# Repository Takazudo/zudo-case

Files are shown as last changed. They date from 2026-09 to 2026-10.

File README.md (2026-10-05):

# ZUDO CASE — zudo-doc引継ぎセット

**D1 / 文書スナップショット: 2026-09-24**

3U・60HP、3U＋3U＋1U・40HP、3U＋3U＋1U・60HPの金属ケースを、現物確認・見積・発注へ進めるためのドキュメントです。本文は日本語のMDX、サイト設定はzudo-doc用です。

このD1は**資料整理の版**です。ケースCADの新しい版や、製造承認ではありません。

## 現行7U40候補

[R9-FITFIX-01](src/content/docs/design/r9-fitfix-01.mdx)を追加。ガードと蓋座面の修正候補で、固定環境の生成・検査記録は `engineering/r9-fitfix-01/verification/`。旧R9は履歴として保存し、現物嵌合・接着・運搬と製造承認は未完了。

## 家庭印刷用8mmスペーサー

フレームとケース側板の間に入れる[8mmスペーサーのSTL・編集用ソース・印刷手順](engineering/home-print-spacer-01/README.md)を追加。外径10mm／穴径5.5mmはR6由来の仮寸法です。まず1個で現物確認し、3U60は4個、7U40/7U60は各10個を印刷します。

## まず起動する

Node.js 22以上とpnpmを用意してください。このスナップショットは公式scaffolderで初期化済みで、`package.json`と`pnpm-lock.yaml`を含みます。新しいチェックアウトでは、依存をロックファイルどおりに入れてから使います。動作確認した環境はNode.js 24.13.1、pnpm 10.30.3です。

```sh
# リポジトリのルートで実行
pnpm install --frozen-lockfile
pnpm check:docs
pnpm check:assets
pnpm test:setup
pnpm build
pnpm dev
```

このセットの初期化には公式`create-zudo-doc@5.27.0`を使いました。`scripts/setup.mjs`はscaffoldをまだ取り込んでいない文書のみのスナップショット向けです。この初期化済みチェックアウトでは再実行せず、ロックファイルから依存を復元してください。Git初期化、デプロイ、注文は自動実行しません。

2026-09-24の初回ビルドでは44ページを生成し、41件の文書ルートと検索項目、47件の公開資産を確認しました。現在は画像・図15件をzudo-docのAsset Viewerに移し、`/files/`の一覧と各閲覧ページを追加して60ページを生成します。同日のChrome 146.0.7680.153で、desktop 1440×900とnarrow 390×844の実表示も確認しました。41ルートと8カテゴリを両幅で開き、narrowでの横はみ出しはなく、検索・テーマ・画像・R8/R6プレビューの主要操作も動作しました。画面ごとの記録、ダウンロード件数、スクリーンショットは[検証記録](project/browser-validation.md)にまとめています。物理的な嵌合・強度・運搬試験はこのブラウザー確認に含みません。`pnpm dev`が表示するURLを開き、「現在地と最初に読むページ」から読んでください。

### ローカルと本番のプレビュー確認

`pnpm dev`で開いた文書のR8/R6プレビューと参照・旧版ZIPのリンクは、既定では同じチェックアウトの`public/previews/`と`public/downloads/`を参照します。R8ページの埋め込み枠の下にある「表示元: ローカル (public/)」を確認してください。`public/previews/r8-simple-lid.html`を変更すると、開き直したローカル文書からその変更を確認できます。

別のプレビュー配信元を試すときは、起動時にHTTP(S)のoriginだけを指定します。パスは付けません。

```sh
ZUDO_CASE_PREVIEW_ORIGIN=http://localhost:8787 pnpm dev
```

`dev`・`check`・`build` は同じチェックアウトで併用できます。起動ごとに `.cache/site-runs/run-*` の独立した設定と内部キャッシュを使うため、別コマンドを実行しても稼働中のdevの表示元は変わりません。異なるoverrideを指定したdevも、`pnpm dev --port 3001` のように別ポートで起動できます。記事・コード・設定は実行ごとのコピーを使い、devでは元の編集・追加・削除を約250ms間隔で反映します。`public/` は元のチェックアウトを直接参照します。build/checkは起動時のコピーを使います。

内部キャッシュは終了時に削除します。強制終了などで残った実行フォルダーは、対応するプロセスが停止していることを確認してから削除してください。公開ビルドは従来どおりチェックアウトの `dist/` に出力し、`pnpm preview` もその出力を配信します。同じ出力先への複数buildの同時実行は避けてください。

この場合は枠下に指定先のホストが表示されます。本番ビルドの既定値は`https://zudo-case-preview.zudolab.dev`で、文書とプレビューの２ホスト配信を維持します。本番ビルド前は上記環境変数を外してください。`pnpm build`後の`pnpm check:built-preview-links`で、生成した文書HTMLに本番ホストのリンクがあり、ローカルURLが混入していないことを確認できます。

### 初期化履歴と確認範囲

元の文書のみのスナップショットではnpmレジストリの名前解決が`EAI_AGAIN`となり、その時点では初期化・ビルドを確認できませんでした。その後、2026-09-24に公式scaffolderの実行とロックファイルに基づく依存インストールを完了し、上記の実ビルドを確認しています。各画面のブラウザー確認結果・表示幅・残件は検証記録に記載します。

初期化前の文書のみのスナップショットで、取り込み内容だけを確認する場合:

```sh
node scripts/setup.mjs --dry-run
```

公式CLIを別フォルダーへ実行した場合は、次の形でも土台だけ取り込めます。

```sh
node scripts/setup.mjs --from /absolute/path/to/fresh-official-scaffold
```

既に運用中のサイトへ統合する場合は、setupを実行せず、記事・資産・設定を個別にマージしてください。補助スクリプトはファイル衝突があると上書きせず停止します。CLIの版は`ZUDO_DOC_CLI_VERSION`環境変数で指定でき、デフォルトは`5.27.0`です。生成結果は`.handoff/`に記録します。

## 入っているもの

| 大分類 | 内容 |
|---|---|
| 概要 | 現在地、採用仕様、未確認事項、用語 |
| ３機種 | 寸法、レール・金具・ガード数量、比較表 |
| 設計 | レール積層、8mmスペーサー、長穴、締結、ガード、載せ蓋とバンド |
| 製作 | BOM、見積依頼条件、印刷用データの扱い、過去価格の根拠 |
| 検証 | 嵌合・組立・持ち運びの確認と、発注前ゲート |
| 資料 | R8とR6の3Dプレビュー、CAD、STL、STEP、DXF、元データ |
| 判断履歴 | 5→8mm、ガード薄肉化、蓋のロック不採用、バンド採用 |
| 引継ぎ | セットアップ、次工程、更新手順 |

**41文書ページ、8カテゴリ**です。カテゴリ一覧は`project/navigation.json`にあります。画像・図は`/files/`の一覧と閲覧ページにも表示されます。既存のプレビューは、サイトを起動しなくても`public/previews/r8-simple-lid.html`をブラウザーで直接開けます。

## 最初に確認すべき状態

| 対象 | 現在の扱い |
|---|---|
| 採用方式 | 10BOX式の載せ蓋＋運搬時だけ外周バンド２本。蓋と本体のロックなし |
| 本体 | R6の名目CADが修正起点。３機種・8mmスペーサー・薄型ガード |
| ブラケット用長穴 | 意図は採用済み。R6の製作図にはまだ丸穴が残る |
| 蓋 | R8の表示用形状まで。新しい製作用STL/STEP/DXFは未生成 |
| R7のM3ロック蓋 | 不採用の参考資料。最終仕様として注文しない |
| 現在の総原価 | 未確定。旧R3ガード2,264円を現行全体の見積に流用しない |
| 製作承認ファイル | なし。`engineering/release/`は注意書きだけ |

ガードの固定方法・嵌合、公差、ノブ上方の隙間、バンドによる天板のたわみ等も確認待ちです。ここを見失わないため、`project/open-issues.json`と発注前ゲートを用意しました。

## フォルダー

```text
zudo-case-doc/
├── README.md / AGENTS.md
├── zfb.config.ts                 # この文書サイトの設定
├── setup.preset.json             # 公式初期化CLIへ渡す設定
├── src/content/docs/             # 41ページのMDX
├── public/
│   ├── assets/                  # Asset Viewerの画像・図・見積画面
│   ├── previews/                # R8/R6の単一HTML
│   ├── evidence/                # 旧README、計算結果
│   └── downloads/
│       ├── reference/           # 未承認のR6参照データ
│       └── archive/             # 不採用のR7・ロック比較
├── engineering/
│   ├── r6-body/                 # 元ソース・CAD・STL・PCB
│   ├── r8-preview/              # 載せ蓋の表示用ソース
│   └── release/                 # 承認後にのみ格納
├── project/                     # 仕様・根拠・見積・課題・ハッシュ
├── scripts/                     # 初期化、整合チェック、表の再生成
└── tests/                       # 初期化の安全な取り込みを検査
```

元のR6/R8ソースと旧アーカイブは保全しています。過去の生成コードやREADMEにある絶対パス・前提は作成当時のものです。そのまま全スクリプトを一括実行せず、`src/content/docs/resources/engineering.mdx`を読んでからローカル環境に合わせてください。

## 更新と静的チェック

次は依存を入れる前でもNodeだけで実行できます。

```sh
node scripts/check-docs.mjs
node scripts/verify-assets.mjs
node --test tests/setup.test.mjs
```

- `check-docs`: メタデータ、ローカルリンク先、機種寸法・数量・見積加算の整合を検査します。MDXコンパイラではありません。
- `verify-assets`: 同梱資産のSHA-256を、引継ぎ時の台帳に照合します。CADの強度・干渉・公差を保証するものではありません。意図的に変更した資産は差分になります。
- `test:setup`: 模擬scaffoldを使い、既存記事保護・衝突停止・復旧を確認します。公式CLIの実行確認ではありません。

機種別の表とBOMは台帳から再生成します。

```sh
# project/current-spec.jsonを根拠とともに更新した後:
node scripts/sync-reference-tables.mjs
node scripts/check-docs.mjs
```

自動生成の対象は３機種ページ、機種比較、BOMの５ページ。**台帳はCADジェネレーターの入力ではありません**。ここだけ直して製作データを更新済みにしないでください。

## 根拠と公開範囲

ユーザーが測定した寸法、採用方針、元STL/PCB、過去のモデル値、見積画面、助手の概算を分けました。会話由来の採用判断は`project/source-notes/user-decisions.md`、出典台帳は`project/sources.json`です。今回、サプライヤーの価格を取り直してはいません。

Cloudflare Workers Static Assetsへの公開設定は２つのホストに分けています。`zudo-case.zudolab.dev`は文書、Asset Viewerの画像・図、テキスト/JSON根拠を配信し、`zudo-case-preview.zudolab.dev`は単体HTMLプレビューと参照/旧版ZIPを配信します。`pnpm build`の後に`pnpm prepare:worker-assets`で配信フォルダーを分離し、25MiBを超える２ファイルは小片に分けてプレビューWorkerが元のURLでストリーム配信します。元ファイルのSHA-256は維持します。GitHub Actionsは`main`へのpushで２つのWorkerを順にデプロイし、`CLOUDFLARE_ACCOUNT_ID`と`CLOUDFLARE_API_TOKEN`をデプロイ手順だけに渡します。**noindexはアクセス制限ではありません。** 見積画像と旧版ZIPもそれぞれのホストで閲覧できる設定です。初期設定はルートパス配信です。

### 公開配信の検証範囲

ローカルのモックテスト（`node --test tests/verify-deployed-assets.test.mjs tests/worker-assets.test.mjs`）は、短いサンプル資産でHTTP転送、SHA-256照合、Workerのチャンク欠落・切り詰めを確認します。デプロイ後のGitHub Actionsと`pnpm verify:deployed`は、対象２ファイルを全量GETでストリーム読み込みし、チェックアウト内の元ファイルとバイト数・SHA-256を照合します。HEADリクエストは到達確認だけです。どちらもブラウザー/WebGL表示の証拠ではなく、ブラウザー表示の確認は[検証記録](project/browser-validation.md)を参照してください。

第三者ライブラリや元資料の著作権・ライセンス表示は元ファイルの記載に従います。資料整理によって再ライセンスしたものではありません。

## 再実行と復旧

`pnpm prepare:worker-assets`を同じビルド結果に対して再実行すると、世代番号と分割ファイルの完全性を確認してから「already prepared」と表示し、配信ファイルを変更せず終了します。不完全な分割ファイルや片方だけ残った入力が見つかった場合は停止します。`pnpm build`を再実行して入力を作り直し、改めて`pnpm prepare:worker-assets`を実行してください。準備中の失敗でも元の`dist/previews`と`dist/downloads`は移動せず、成功後にだけ配信用のコピーから除きます。`public/`や`engineering/`の元資料には触れません。

公式資料: [Installation](https://zudo-doc.takazudomodular.com/docs/getting-started/installation/) / [CLI](https://zudo-doc.takazudomodular.com/docs/reference/create-zudo-doc/) / [Configuration](https://zudo-doc.takazudomodular.com/docs/guides/configuration/)

## 2WAY experimental family

The independent two-tray study is scoped by `engineering/two-way/AGENTS.md` and `project/two-way/`. F5 is immutable reference; TW-01 is the maintained workbench. It is separate from R9, not a manufacturing release. Its 72/58 mm patch-gap assumptions do not replace the single-tray lid specification.

TW-01の通常生成はオフラインで、既存CADの再生成を必要としません。

```sh
pnpm build:two-way
pnpm check:two-way
pnpm test:two-way
```

[2WAY文書](src/content/docs/two-way/index.mdx)と[ソース・ブラウザー検証手順](engineering/two-way/tw-01/README.md)を参照してください。元F5受入結果とTW-01の描画方式別結果は分けて記録します。

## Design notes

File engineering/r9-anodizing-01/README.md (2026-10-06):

# R9-ANODIZING-01 — 13枚のアルマイト吊り穴追加

Issue [#116](https://github.com/Takazudo/zudo-case/issues/116)。JLCCNC のアルミ試験片13枚に、各1個の専用丸穴を追加した別リビジョン。A5052、板厚1.5 mm、黒アルマイト。PA12の13設計・15個とは別です。元のR9/R9-FITFIXソース、注文ZIP、既存プレビューは変更しません。

`out/r9-anodizing-01-aluminum-13-NOT-APPROVED.zip` は13 STEP＋13 DXF、対応表と検査manifestを収録。STEP/DXFの組は同一品で、26個ではありません。各1枚です。`out/r9-anodizing-01-review.zip` は変更前後SVG13枚、参照STL13個、manifestです。STLはアルミ加工の提出原本ではありません。ZIPの `NOT-APPROVED` はサプライヤーへの製造承認・差替え操作を行っていない意味です。

## Ø4 mm、最小残り幅1.5 mmで保護領域を避ける

サプライヤーから伝達された許容径3.5–5 mmの中で、4 mmを選択。小さいC5でも既存接触面を避ける余地を残し、3.5 mmの下限より0.5 mm大きくしています。残り幅は**穴の端から板端まで**。許容の出発点1 mmに対し、通常2–3 mm、C5で1.5 mmを確保しました。

| ID | 板の平面寸法 mm | 穴中心 U,V mm | 最小残り幅 mm |
|---|---|---|---|
| c1-metal-edge | 40 × 20 | 5, 5 | 3 |
| c2-01-wall | 30 × 31 | 5, 5 | 3 |
| c2-01-plate | 30 × 26.4 | 5, 21.4 | 3 |
| c3-01-bottom / wall | 各32 × 20 | 各4, 16 | 2 |
| c3-02-bottom / wall | 各32 × 20 | 各4, 16 | 2 |
| c3-03-bottom / wall | 各32 × 20 | 各4, 16 | 2 |
| c4-01-floor | 30 × 20 | 5, 15 | 3 |
| c4-01-wall | 30 × 18.5 | 5, 13.5 | 3 |
| c5-01-front | 10.5 × 20 | 7, 7 | 1.5 |
| c5-01-left | 12 × 20 | 8.5, 7 | 1.5 |

U,Vは各DXF左下を原点、右・上が正。元のSTEPが組立座標の部品はそのまま保持。C3 STEPは従来どおり平置き座標です。manifestはSTEP座標と実ケース座標を明確に分離しています。

## 保護した領域とケースとの関係

- C1: 全比較ガードの上端5 mm帯を保持。
- C2: 3種類すべてのフレーム、ガード、支持棚、取付ねじ穴の周辺を避ける。壁の穴は下部、天板は棚から離れた内側の自由端。
- C3: 幅16 mmの金具帯全体と下端5 mmを保護。元の5.5×7.5 / 5.5×8.5 mm長穴および対照Ø5.5 mm丸穴は保持。金具帯は長い比較長穴の±1.5 mm移動と、計算上OD13.5 mmまでの座金受け面も含む保守的範囲。吊り穴との距離は2 mm。実座金・ねじ・工具は未選定。
- C4: 下ガード・床と壁の接触帯を保持。全体ケースの前底金具も再生成し投影を検査。
- C5: 上端ガードだけでなく、**試験片には含まれない全体ケースの縦角ガードと角金具**も検査。最初の穴案は縦ガード／金具帯にかかったため修正。採用位置は縦ガード帯から1.5 mm、角金具上端から1.5 mm、上ガード帯から6 mm離れる。

[既存ケース・試験片マップ](https://zudo-case-preview.zudolab.dev/previews/r9-order-map.html#part=c2-01-frame)は元注文の形状を表示する参照です。追加穴の正本は本リビジョンのSVG/STEP/DXFです。ケース本体の製造版へ穴を転記したものではありません。

## 再生成と検証

```sh
uv sync --locked --project engineering/r9-prototype-01
uv run --locked --project engineering/r9-prototype-01 python engineering/r9-anodizing-01/build.py
uv run --locked --project engineering/r9-prototype-01 python engineering/r9-anodizing-01/test_revision.py
```

`--out /tmp/anodizing-check` で出力先を分離できます。元の `fitfix.coupons.coupon_families` と `r9.coupons._build_c3` をパラメータから実行し、元STEPとの立体差分・元DXFの再構成一致を確認してから切削します。元ファイルと注文ZIPは注文時commit `541eca7f8ebc2e6da4375108b0d66773a0868b00` とバイト一致を検証。実装起点はプレビューPR115を含む `9bd8e65` です。

生成時に以下を全13枚で検査し、不合格時は停止します。

- 追加物なし、外形／厚み不変、削除領域がØ4×1.5 mm円柱1個だけ。削除体積は18.8495559 mm³。
- ガード／隣接部品の実BREP境界から保守的な平面投影を作り、穴との正の距離を確認。
- STEPを再読込し、DXFの外形・円・長穴円弧から再構成した立体と比較。
- STLの閉じた辺接続、向き、正体積、寸法／体積誤差を確認。
- `replacement-map.csv` と `manifest.json` が旧→新のファイル名・SHA-256を記録。`checksums.json` がZIPと図も含めて記録。
- 回帰テストで、欠落穴、余分な穴、径違い、元取付穴の埋戻し、端距離不足、ガード／金具干渉、誤ったDXFを検出。CIで39個のCADファイルと13枚の図の再生成一致を確認。

これは公称CAD・ファイル整合の検証です。実物の強度、アルマイト処理時の治具アクセス／跡、仕上がり公差、実金具との嵌合は保証しません。サプライヤーへのメール、JLCへの差替え・アップロード・発注／支払操作は実施していません。

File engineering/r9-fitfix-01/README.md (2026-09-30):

# R9-FITFIX-01 — 7U40 / #99・#100・#101 修正候補

## ローカル統合済み（2026-09-30）

Python3.12.12 / CadQuery2.7.0を既存uv.lockで復元して再生成。11回帰テスト、51 STL/STEP、旧R9本体３パターンのDXF比較が通過。候補台帳・文書・公開コピーを `node scripts/sync-fitfix.mjs` で同期し、`--check` で差分を検出する。旧R9台帳の検査は独立して継続する。検査範囲と残件は [verification/LOCAL-VALIDATION.md](verification/LOCAL-VALIDATION.md)。

本体＋専用天板の材質別アルミZIPも各案に追加した。下記のクラウド時点の「残るローカル作業」は引継ぎ当時の記録で、現在の状態は上記検証記録を優先する。out/は各ファイル25MiB以下の候補として保存する。製造承認・現物検証・見積は未完了。

基準: `7f04c5bda0672ecf2cded79b6e1b48ad141e64b5`。
**元のR6・R8・R9を上書きしない、独立した候補ディレクトリ。製造承認ではありません。**

## 実装した変更

- 下辺は底板を挟み込まないL字カバー。垂直単板向けU断面の上下反転は使いません。
- 上端は外側スカート・内側返し・屋根を、入れ子の矩形リングで作ります。２枚の立板が交わる角にも返しが侵入しません。
- `wall`は主要平坦部分の実肉厚です。横方向の嵌合/接着用すきまは肉厚とは独立し、外形と内側開口へ反映されます。
- **垂直な接着面だけ**に`fit_per_face + adhesive_per_face`の空きを設けます。屋根下面は金属上端、下辺の水平フランジ上面は底板下面へ直接当たるハードストップです。未定義のガスケットや上下の浮きは加えません。
- 蓋座面はその実ガード上端と一致。天板下面=座面+30mm、段差下面=座面-12mmを同じ関数から導出します。
- C1/C2を更新し、床＋壁の下辺C4、２立板の上端コーナーC5を追加。同じ本体断面/部品の切り出しです。

## 生成と検査

このフォルダーをリポジトリの`engineering/r9-fitfix-01/`に追加した状態で:

```sh
cd engineering/r9-fitfix-01
uv run --locked --project ../r9-prototype-01 python build.py
uv run --locked --project ../r9-prototype-01 python tests/test_geometry.py
uv run --locked --project ../r9-prototype-01 python tools/compare_r9_patterns.py
```

`build.py`は依存を追加しません。CadQuery/numpy/ezdxfだけを使用します。Python3.12/CadQuery2.7系の既存uv.lock環境での実行は**ローカル担当**です。このチャットの出力はPython3.13.5/CadQuery2.8.0で生成しています。

参照する`../r6-body`は現在のR9が引き継いだ公称配置の保存元です。必要な６入力をGit blob SHAで照合します。元ディレクトリへの書出しは無効化し、レール・PCB・金具の配置だけを再構築します。本体穴はR9のルール（36長穴＋10丸穴）で再作成します。**リポジトリ全体をcloneした環境でR9パイプラインを実行したものではありません。** `compare_r9_patterns.py`で現在R9の実DXFとの一致を追加確認してください。

既存出力を保全して比較する場合、`--out /path/to/new-empty-output`へ生成してください。一度に１ビルドだけ実行してください。`out/`は既定ではgitignore対象です。現物/ローカル確認後、現在のリポジトリ規約に合わせて候補出力の追跡方法を決めます。

## 材料・寸法の扱い

基本案は実肉厚1.2mm、比較案は1.0mm。主断面は屋根・外側壁・内側返しとも同じ厚さです。丸みを含む全域の自動最小肉厚検査や強度解析をしたものではありません。試験片の小さい浮出し文字は識別用で、構造壁とは別です。

基本案: ガード外形232.4×337.0mm、上端Z92.2、蓋座面Z92.2、天板下面Z122.2、天板228.2×332.8×1.5mm。底板下面Z0を基準とし、ガード全高93.4mmと上端座標を混同しません。

`fit=.15`＋`adhesive=.15`は片面の**空間配分候補**で、0.15mmテープを選定した意味ではありません。実際の空き0.30mmを埋めて保持できる接着剤、またはテープ/当て材の組合せが必要です。側面保持は未選定・未検証。上端の着座確認は乾式でもできます。ハードストップに接着層を追加する場合はその高さも再設計してください。

本体アルミ５枚、8mm離隔、レール寸法、単純載せ蓋＋外周バンドの方式は維持。C3の座金/工具/長穴範囲は今回の３件とは別の未確認事項です。厚い旧ガードやロック機構へ戻していません。

## 出力

`out/preview.html`は同じ生成形状を内蔵する単一HTML。WebGLが使えない場合はCanvas簡易描画に切り替わります。簡易描画の断面は三角形の選別で、CAD切断面ではありません。

- `pa12/t1p2` / `pa12/t1p0`: 各案の本体ガード６種類（16個）と蓋枠４個。
- `aluminum/body`: 本体３種類、必要枚数1/2/2。各案の蓋は`aluminum/t1p2`または`t1p0`。
- `coupons`: C1/C2/C4/C5。C2の壁・ガード・天板は比較間で再利用できます。
- `BOM.csv`: 個数、材料、参照パス。STLは１個の形状です。
- `validation.json`: 検証範囲と未検証事項。`environment.json`: 実行環境。
- `outputs-manifest.json`: 生成コード入力と出力のハッシュ。

1.2mm/1.0mmは**それぞれ専用の蓋**も生成します。比較する案を混ぜて注文しないでください。PA12とアルミは別の見積用ZIPです。

## 残るローカル作業

1. 固定環境の再生成、保存R9の本体DXFとの比較、元CIへの統合。
2. 候補台帳・現行指定・生成MDX・公開プレビューの参照をこの版へ統合。古いR9へ新しいSHAだけを書き込まない。
3. 接着/テープ/座金等の品番・最終嵌合を小型試験片で確認。未確認値を試験済みにしない。

`tools/make_ledger_proposal.py --after-local-verification`は、確認後の出力から候補登録案をJSON標準出力へ出すだけです。既存台帳への自動反映、G01〜G11の更新、発注、デプロイ、承認は行いません。

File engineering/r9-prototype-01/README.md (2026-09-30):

# R9-PROTOTYPE-01 7U40 candidate generator

This directory contains the independent 7U40 candidate generator and its recorded CAD outputs. The candidate uses the R6 7U40 geometry as its starting point and rebuilds the adopted R8 lift-off lid as editable R9 geometry. It is not a manufacturing release; all physical fit, hardware, finish, and transport gates remain open.

Python 3.12 and uv are required. From this directory, install the locked environment, regenerate the candidate, and run its validation:

```sh
uv sync --locked
uv run python build.py
uv run python build.py --validate
uv run python tests/smoke.py
```

For a focused regeneration, pass a comma-separated module list such as `uv run python build.py --only body,slots`. The complete module order is body, slots, guards, lid, coupons, preview data, and checks. `out/outputs-manifest.json` records the generator inputs and output byte hashes; `project/release-state.json` and `project/artifact-manifest.json` register the unapproved candidate files.

The committed `out/` files are the generated evidence for this revision. Scratch builds and parameter-change checks use temporary directories. Review generated geometry and its manifest together when intentionally refreshing a candidate; a hash update by itself does not validate a geometry change.

## Candidate bracket slots

The body plate exports use 36 obround bracket slots (5.5 × 7.5 mm, ±1.0 mm candidate travel), with the long axis perpendicular to the joint bend line. The 10 rail-fix holes stay round φ5.5 because the independent rail frame is located by its fixer PCB. There is no intentional adjustment along the bend line; along-edge positions follow the CAD hole spacing. The nominal datums are the bottom plate's lower face and each wall's exterior face. Assemble by 仮締め → 外形/直角を整える → 本締め.

`out/aluminum/hole-table.json` lists all 46 locations; `slot-checks.json` records edge, ligament, bearing, guard-band, and nominal exterior tool-envelope checks. The provisional 10 mm outer washer does not meet the specified bearing overlap at 26 wall slots. An OD of at least 11.5 mm is a candidate to check for fit and availability, not a selected part. Slot size, driver envelope, fastening hardware, and physical access need coupon and assembly confirmation before manufacture.

## Current recorded validation

See [VALIDATION.md](VALIDATION.md) for the stored validation summary and flags. It records 156 passes, 14 flags, and zero failures for the current candidate. CAD checks do not validate physical fit, loads, guard retention, anodizing allowance, strap strength, module clearances, or transport. The open physical checks and blank result sheets are documented in the project verification pages.

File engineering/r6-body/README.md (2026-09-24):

# ZUDO CASE FAMILY — R6

8mmスペーサー、前後約8mmの余白、実データのレール・PCBを反映した３機種の設計検討データです。

- **3u60**：3U・60HP、レール２本。
- **7u40**：3U＋3U＋1U・40HP、レール６本。プレビューの初期表示。
- **7u60**：3U＋3U＋1U・60HP、レール６本。

7Uの３列は同一の水平面に並びます。ケースは奥行が長いトレー形状とし、金属部分の高さ91mmを共通にしています。内部の仕切り板は追加していません。

## まずプレビューを見る

ZIPをすべて展開して `index.html` をブラウザで開いてください。別途配布の `zb60-case-preview.html` は同じ内容を１ファイルにまとめたものです。Three.js、全形状、ガードSTLのダウンロード用データを同梱しているため、インターネット接続なしで利用できます。

上部の３つのボタンでケースを切り替えます。ガード厚1.2／1.0mm、組立／分解／レール脱着、黒アルマイト／識別色／銀色表示、外板の透過、断面、部品別の表示を選べます。部品をクリックすると寸法が出て、ガードはその部品のSTLを保存できます。「寸法・積層・出典」には選択中のモデルの条件が表示されます。

## 外形と数量

寸法の順序は **幅W（レールの長手）× 奥行D（区画を並べる方向）× 高さH**、単位mmです。ガード込みは1.2mm案の公称包絡寸法で、ゴム脚・外側ナットなどの突起、モジュール・ノブ・ケーブルは含みません。

| モデル | 金属外形 mm | ガード込み mm | レール本数 | 8mmスペーサー個数 | L字ブラケット個数 | ガード個数 | ガード体積 cm³ |
|---|---|---|---:|---:|---:|---:|---:|
| 3u60 | 330.4 × 154 × 91 | 332.8 × 156.4 × 93.4 | 2 | 4 | 16 | 12 | 27.333 |
| 7u40 | 229.4 × 334 × 91 | 231.8 × 336.4 × 93.4 | 6 | 10 | 18 | 16 | 31.096 |
| 7u60 | 330.4 × 334 × 91 | 332.8 × 336.4 × 93.4 | 6 | 10 | 18 | 16 | 35.906 |

40HPの実STL長は204.0mm、60HPは305.0mmです。HPから算出した公称幅への置換や、60HPデータの縮尺変更は行っていません。

外幅は以下の積層から求めています。

`レール長 + 2 × (padder 1.6 + fixer 1.6 + 内側スペーサー8 + アルミ1.5)`

したがって40HPは229.4mm、60HPは330.4mmです。レールユニット外幅は、それぞれ210.4／311.4mmです。

前後の余白は、**レールユニット全体の最も外側の輪郭から、前後アルミ板の内面まで**を基準にしました。元データの長手包絡は3Uが134.531860mm、7Uが314.754456mm。両側に8mmと板厚1.5mmを加え、加工寸法を整数mmに切り上げて154／334mmとしました。実際の片側余白は3Uが8.234070mm、7Uが8.122772mmです。上端ガードは板内面から1mm内側へ張り出すため、ガードまでの余白はそれぞれ約7.23／7.12mmです。

## アルミ５枚

全モデルで1.5mm厚の黒アルマイト仕上げを想定しています。曲げ加工や、厚い板の凸凹による組合せを使わず、底１枚・左右２枚・前後２枚をL字ブラケットで固定します。

| モデル | 底板：W × D、１枚 | 前後板：横 × 高さ、２枚 | 左右板：横 × 高さ、２枚 |
|---|---|---|---|
| 3u60 | 330.4 × 154 | 327.4 × 89.5 | 154 × 89.5 |
| 7u40 | 229.4 × 334 | 226.4 × 89.5 | 334 × 89.5 |
| 7u60 | 330.4 × 334 | 327.4 × 89.5 | 334 × 89.5 |

左右板が前後板の端面を挟み、４枚の立板が底板の上に載る配置です。縦の４接合部にはそれぞれL字ブラケット２個。3Uの底の周囲は各辺２個、7Uの長い左右辺は３個ずつとして中央の支持を増やしています。

ブラケットは在庫の20×20×16mm、実測厚2.0mmをモデル化しました。変形分として0.2mmを足した2.2mmの占有厚もクリアランスの検討に使います。**穴中心の位置は現物未測定のため、内面から10mmという仮値です。** アルミのφ5.5穴とDXFの穴位置はこの条件に基づく提案です。長穴への変更方向・長さは、現物穴位置を確認してから決めてください。

## 底面のネジと仮のゴム脚

底板との接合ネジ８本（3U）／10本（7U）は、低頭の頭を底板の外側、ワッシャーとナットを内側へ向けます。外側ナットが接地してしまう問題を避けるため、ここだけ締結方向を反転しました。アルミ穴とガード形状は同じです。

低頭の頭は底板下面から1.4mm出るため、接地用に黒い貼付ゴム脚φ10×厚3mmを４個仮配置しました。中心は各外縁から20mm内側。無荷重の公称寸法で、脚の接地面から金属ネジ頭まで1.6mmの余裕があります。脚は未選定の既製部品を想定しており、JLC3DP用ガードSTLや体積に含みません。実物の材質と圧縮量は別途確認してください。

1.2mmガードとこの脚を含む高さは95.2mm、1.0mmガードでは95.0mmです。上表の「ガード込み外形」は脚を含まないため、この高さとは異なります。

## fixer・padder・レール

PCBの厚さはすべてユーザー確認済みの1.6mm。元のEdge.Cutsを保持しています。7U fixerは314.754456×60.015381mmの一枚で、3U fixerより下側に約30mm深く張り出します。`docs/7u-layout.svg` とPNGに輪郭と使用穴の関係を示しました。

7Uの各側面には、3U padder２枚と1U padder１枚を置きます。1U元CADの約0.025mmの原点ずれを補正し、元の形状を変更せずに区画の外形へ合わせています。3U同士、および3Uと1Uの間にはそれぞれ約0.032mmの元データ由来の隙間があります。穴中心の微差は消していません。M5の径5mm軸は全６箇所のpadder角穴内に収まることを公称輪郭で確認しています。

レールとPCBを固定するネジはレールユニットに属します。「レール脱着」でレール、fixer、padder、レール端ネジを一緒に持ち上げ、外箱固定用のボルト、内側スペーサー、外側ワッシャー、ナットを別方向へ分離して表示します。

## ケース側の締付積層

内側から、M5の頭 → fixer 1.6mm → ナイロンスペーサー8mm → アルミ1.5mm → ナイロンワッシャー1mm → 外側ナット、です。padderはfixerの内側で頭を逃がすため、締付積層に含めません。

頭高さはユーザー実測を反映した**1.4mm**。padder厚1.6mmに対して公称0.2mmの高さ余裕です。fixer外面から外板内面までの8mmには、fixer自体の1.6mmを重複して加算しません。対向する頭が平面上で重なっても、`8 − (1.4 + 2.2 + 1.4) = 3.0mm`の横方向の公称余裕があります。

3Uの外箱固定は片側２本。7Uは各3U区画に２本、1U区画に１本の片側５本を、既存fixerの長穴とpadder窓が重なる位置へ配置しました。窓内にある頭の表示直径は仮にφ9mmとしています。この直径では全点が窓に収まりますが、実物の頭径を測定した値ではありません。外側ナットとボルト長は配置説明用であり、必要ねじ長の確定仕様ではありません。

## PA12ガードと見積

ガードは黒のPA12-HP Nylonを想定し、装飾と縁の保護を担う部品です。箱の構造固定は金属板とL字ブラケットが担当します。

- `t1p2`：厚さ1.2mm、板を覆う幅5mm、外側丸みR0.4mm。
- `t1p0`：厚さ1.0mm、同じ被覆幅と分割構成。
- 3U：12個、４種類。
- 7U：上端は４つのL字、長い左右下辺も半分にして、16個、６種類。
- 各部品の最長辺は概ね180mm以内です。

`stl/<model>/<variant>/` 内の各STLは**１個の形状**です。ファイル名のqtyと`manifest.json`の数量を指定すると、ケース１台分になります。同一ファイルを数量分複製して重ねた形状ではありません。

今回の寸法変更後の価格は未取得です。旧形状の見積金額は新モデルへ流用していません。JLC3DPでは該当モデルのSTLと数量を投入して再見積してください。

ガードの板に対するクリアランスは、現在は公称接触の0mmです。保持方法（接着等）、造形・仕上げによる寸法差、実物への嵌合は未確定で、量産発注用の最終公差設計ではありません。最初の試作で確認してください。

## ファイル構成

- `index.html` / `app.js` / `styles.css`：プレビュー本体。
- `vendor/`：オフライン描画用Three.jsとライセンス。
- `mesh-data.js`：３機種の全表示形状と計算寸法。
- `stl-data.js`：プレビューから保存するガードSTLの元バイト列。
- `design-parameters.json`：確認済み寸法、設計選択、未測定の仮値の区別。
- `build_geometry.py`：元データからのCADとメッシュ生成。
- `package_preview.py`：単体HTML、ソースZIP、モデル別見積ZIPの生成。
- `stl/`：モデル別・厚さ別のガードSTLと数量表。
- `engineering/`：モデル別のSTEP、DXF、寸法、穴位置、干渉・STL検証記録。
- `source-data/`：元STL、KiCad、抽出輪郭、出典・ハッシュ。
- `docs/`：7Uの実輪郭配置図とプレビューの確認記録。

再生成はCadQuery 2.7とezdxfを利用するPython環境で、`python build_geometry.py`、続いて`python package_preview.py`です。元STLのメッシュ上の重複面等は勝手に修復せず、そのまま参照形状として保持しています。ねじ山の噛合い、電源・モジュールやケーブルの占有空間、荷重試験は本プレビューの幾何検証の範囲外です。

## 検証結果

３機種について、オフラインの単体HTMLをChromeで開き、モデル切替、厚さ切替、レールユニットの一括脱着、STLの保存、寸法と数量の更新を確認しました。保存したSTLはCAD出力のファイルとバイト一致しています。360px／390px幅でも横にはみ出さず表示されます。スクリプトエラーと外部通信はありませんでした。

CAD側の検証範囲と結果は`engineering/<model>/validation.json`、独立確認は`docs/`のレビュー記録を参照してください。表示に使うボルト頭と、より大きな仮の径を使った占有検討は区別しています。未測定のレール端頭をφ12と仮定すると、7Uの隣接軸間11.996mmに対して頭同士の包絡が約0.004mm重なります。実外径未確認の条件付き結果であり、実際の既存fixerやレールの軸位置は変更していません。表示用φ9の頭と実レール本体の配置では干渉を検出していません。

## 一次データ

レールの固定コミットは `0f7316ad9000b7906e5769aa89aff2dc18c661c8`、PCBは `b4db88ce5c93709f3f2f0a031f75190081f02443` です。

- [40HP rail STL](https://github.com/Takazudo/zudo-rail/blob/0f7316ad9000b7906e5769aa89aff2dc18c661c8/working/nuts-v2-40hp-single.stl)
- [60HP rail STL](https://github.com/Takazudo/zudo-rail/blob/0f7316ad9000b7906e5769aa89aff2dc18c661c8/working/nuts-v2-60hp-single.stl)
- [3U fixer](https://github.com/Takazudo/zudo-blanks/tree/b4db88ce5c93709f3f2f0a031f75190081f02443/panels/zb-side-frame-3u)
- [7U fixer](https://github.com/Takazudo/zudo-blanks/tree/b4db88ce5c93709f3f2f0a031f75190081f02443/panels/zb-side-frame-7u)
- [3U padder](https://github.com/Takazudo/zudo-blanks/tree/b4db88ce5c93709f3f2f0a031f75190081f02443/panels/zb-side-frame-pad-3u)
- [1U padder](https://github.com/Takazudo/zudo-blanks/tree/b4db88ce5c93709f3f2f0a031f75190081f02443/panels/zb-side-frame-pad-1u)
- [既存ケースの構成例](https://panels.takazudomodular.com/case-models/)

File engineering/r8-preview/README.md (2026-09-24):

# ZUDO CASE — R8 / Simple lid + travel bands

## この版

最終承認の構成を確認するプレビュー専用の版です。
**元の10BOXの「前後の段差を空きスペースへ下ろして位置決めする載せ蓋」＋「持ち運ぶときだけ別体のバンド2本」**を表示します。

- 蓋から本体への固定用M3、前後のロック穴、ナット受け、回転カム、スライダー、奥の固定フックを削除。
- 蓋は下ろす／真上に持ち上げる動作だけ。2mmずらす動作はありません。
- 天板をPA12枠へ組み立てるM3は残ります。このネジは開閉時に外しません。
- 元ケースの8mmスペーサー・前後約8mmの余白、蓋の30mm高さを維持。
- レール、PCB、基準となる本体寸法はR6/R7の表示用メッシュから引き継いでいます。
- バンドは既製品を別途用意する想定。表示は幅20mm・厚さ1.4mmの汎用的な模式形状です。特定の製品の再現ではありません。

## 開く

`zudo-simple-lid-preview.html` は単一HTMLです。ブラウザーで開きます。外部スクリプト・画像・フォント・ネットワーク要求はありません。
WebGL2 / DecompressionStream に対応したブラウザーが必要です。

ソース版はこのフォルダーを丸ごと展開し、`index.html` を開きます。

## 操作

- 「日常」：バンドなしの閉じた蓋。
- 「運搬」：閉じた状態でバンド2本を表示。
- 「使用中」：バンドを非表示にして、蓋を真上へ110mm取り外した表示。
- 持ち上げスライダー：0–150mm。
- 蓋を開く操作では、バンドを外した状態へ切り替わります。バンドそのものの解除・伸長のアニメーションはありません。
- 「蓋なし」：蓋を非表示。
- 透過・説明用色分け・前後の差し込みの模式断面・ノブの仮の確認領域。
- ドラッグで回転、スクロールで拡大、右ドラッグで移動。
- 部品をクリックすると名称を表示。
- PNGボタンで現在の全体表示を保存。

初期表示は7U / 40HP・日常の載せ蓋です。

## ケース寸法（mm）

| ケース | 本体アルミ W×D×H | 蓋の金属板 | 備考 |
|---|---|---|---|
| 3U 60HP | 330.4×154×91 | 328.6×152.2×1.5 | レール2本 |
| 7U 40HP | 229.4×334×91 | 227.6×332.2×1.5 | 3U+3U+1U、レール6本 |
| 7U 60HP | 330.4×334×91 | 328.6×332.2×1.5 | 3U+3U+1U、レール6本 |

本体ガードの見付け幅5mm・肉厚1.2mm、PCB厚1.6mm、側面スペーサー8mmは引き継いでいます。
蓋の金属下面はZ122.2mm。閉じた包絡高さは脚と天板ネジを含め128.8mm。バンド／外側のナット等の突起は別です。

### 前後の差し込み

見せ方だけを変更するのではなく、旧ロック付きの細い差し込み部を、単純な幅広の段差へ描き直しました。
PA12枠4個の前後側に半幅ずつ付く形で、中央には分割用0.4mmの継ぎ目があります。
厚さ2mm、上辺ガード上面から下へ12mm、ガード開口に対して公称片側0.7mmの隙間を仮定。
製造でのフィットを決定する値ではありません。実造形、板の反り、ガードの取付を含めて別途調整します。

## 保持とクリアランスの限界

- 蓋には機械的な抜け止めがありません。持ち運ぶときは外周バンドで保持する方針です。
- バンドで強く締め付けた際の蓋のたわみ、保持力、バンドの横滑り、バックルや他の部品との擦れは未検証。
- バンド幅・厚さは表示用の仮値です。商品選定や必要なバンド長さの確定データではありません。
- 蓋やバンドを持ち手として持ち上げることは想定していません。
- パッチケーブルを抜いて閉じる想定です。パネル2mm＋ノブ25mmを仮の包絡としています。
- 本体のブラケット穴位置、樹脂ガードの保持など、R6/R7からの未確定項目も残っています。
- 表示を軽くするため、一部の細かい締結部品とねじ山は省略されています。
- この版に製造用STL・STEP・DXFは含みません。既存の製造用ファイルは変更していません。
- 旧ロック案の製造データを、この載せ蓋の確定図として発注しないでください。

## 検証

`geometry-checks.json`：新しいPA12枠のBRep妥当性、前後ガードと差込部の公称すきま、レールユニットの包絡／金具上端からの距離。本体・レール全体の公差解析や応力解析を示すものではありません。
`browser-validation.json`：３機種×日常／運搬／蓋を外す状態、コントロール、幅390pxのレイアウトの確認結果。
テスト環境では管理設定によりfile://への移動が制限されるため、同じ単一HTMLをオフラインのChromiumコンテキストへset_contentで投入して確認します。ソフトウェアWebGL用にXvfbを使用。

## 再生成

HTMLだけをまとめ直す：

```sh
python build.py
```

段差などの表示用ジオメトリを再生成する（cadquery, numpyが必要）：

```sh
python prepare_models.py
python build.py
```

`reference-models.json.gz` は、以前の軽量比較版からの入力メッシュです。旧機構は入力の一部に含まれますが、再生成時に使うのは本体／天板／天板組立金具／当たり材だけです。古いロックは最終表示データへ入れません。
`model-data.js` は生成済みの現行表示データです。
`app.js` は描画、バンドの模式モデル、操作UIです。
Three.js等のライセンスは `THREE-LICENSE.txt` を参照してください。

## 参照

- 10BOX組立ガイド（位置決め構造の根拠）：https://takazudomodular.com/guides/how-to-build-10box/
- 入力：本会話の `zudo-lid-connection-source.zip` および `zudo-case-r7-lid-source.zip`
- 元STL・PCBのURLとコミットは入力モデルのmeta.sources / meta.sourceCommitsに保存。

新しい段差形状、クリアランス、バンドの表現は今回の設計提案であり、10BOX実物の寸法の複製ではありません。

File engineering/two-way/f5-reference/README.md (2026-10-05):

# Zudo Case F5 — original rail/frame integration

A, B and C now use the zudo-case source rail/frame arrangement in both populated trays.
**This is an interactive dimensional study, not production CAD or a durability approval.**

Open `zudo-case-F5.html` directly in a modern browser. It is self-contained and needs no network.
Start with **Rail frame → A / B / C**, then use **Separate side layers**. `Closed`, `Play · 45°`, `Closure joint`, `Trunk`, and the previous accessory views remain available.

## What changed

| Family | Per tray | Frame now used | Lid rear depth |
|---|---|---|---:|
| A | 3U / 60HP | One original 3U frame | 48 mm |
| B | 6U / 60HP | Two original 3U frames, 1 mm apart | 48 mm |
| C | 7U / 40HP | Original full-depth 7U fixer and 3U + 3U + 1U padders | **70 mm** |

The original 7U board is up to 60.015381 mm deep. With its mounting datum below the module front, it reaches 61.950925 mm behind that front. The previous 48 mm lid cannot hold it unchanged. C's source board was **not shortened**. Its 70 mm lid leaves 6.549075 mm to the modeled inside back plate.

B's shell row-direction dimension becomes 290 mm, not 289 mm, to retain a 1 mm gap between the two original 3U assemblies. The collar seat is moved outward to clear the real side-board stack. Exterior nut-cover envelopes are counted in the new transport width.

## Fidelity

* The 40HP and 60HP rail JSONs are byte-identical upstream Git blobs. Every source triangle is retained; only proper rigid transforms are applied.
* PCB outside vertices, padder rectangles, layer thicknesses, source row/fastener datums, and padder offsets follow the pinned KiCad design. **Rounded cutouts are simplified for visualization.** Do not manufacture PCBs or drill parts from GLBs.
* The source 1.6 + 1.6 mm PCB stack, 8 mm side spacers, 1 mm outer washers, and 1.4 mm fastener-head study are retained. Unspecified hardware dimensions, guard details, mounting bores and fastener lengths remain provisional.
* Both trays use the same selected frame arrangement. The rail-frame inspection shows one tray's frame, with the shell omitted.

Source: `Takazudo/zudo-case` at `6a13d80d816b0247ab9eee761c29c1fb786b76cc`. See [frame integration](docs/RAIL-FRAME-INTEGRATION.md) and [provenance](reference/PROVENANCE.md).

## Files

`models/` contains 15 F5 setup JSONs and six viewing-only GLBs: a frame view and a playing view for each family. Setup/geometry coordinates use mm/Z-up; GLBs use metres/Y-up. `docs/` includes dimensional tables, frame-part counts and nominal mounting datums. `docs/archive-F4/` contains superseded background documents; its old dimensions and validation results do not apply to F5.

See [validation and limitations](docs/VALIDATION.md): 117 numerical/source tests, 69 browser checks, and six GLB round-trip checks passed. The browser run used the software renderer, not WebGL.

## Build and test

```sh
python build.py                       # standard library; offline baked reference geometry
node --test tests/frame.test.cjs      # source / geometry / regression checks
python tests/browser-f5.py            # Playwright + /usr/bin/chromium
node export-models.cjs
python export-glb.py                  # numpy + trimesh; exports six GLBs
```

Only regenerating the baked frame-data file requires `python scripts/prepare-frame-data.py` (Shapely 2.1). Normal HTML builds do not need Shapely or a CAD kernel.

No GitHub repository was modified. No load test, manufacturing release, actual hinge-fit approval, complete interference sweep or fixed-length cable simulation is included.

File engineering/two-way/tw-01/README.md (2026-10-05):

# TW-01 / 2WAY 実験設計

F5の採用構造を維持した独立トレーの作業版。製造承認・耐荷重・実機適合は未検証。
`../f5-reference/` は元ZIPの最小完全ソース。改変しない。

## 再生成

リポジトリルートで Node.js 24 / Python 3.11–3.12 を使用する。

```sh
node engineering/two-way/tw-01/build.cjs --out /tmp/two-way-output
node engineering/two-way/tw-01/build.cjs        # この版の公開資産だけ更新
node engineering/two-way/tw-01/build.cjs --check
node --test engineering/two-way/tw-01/tests/*.test.cjs
```

通常のHTML・設定・表・GLB・ZIP生成は標準ライブラリのみ、ネットワーク不要。
`--check` は一時出力と比較して消去する。ソースに書き込まない。
GLBは同じ表示メッシュを mm/Z-up から metres/Y-up に剛体座標変換した閲覧用。
製作STL/STEP/DXFは生成しない。決定的なZIP日時は2020-01-01。

## 正規輪郭を再変換する場合のみ

```sh
uv sync --locked --project engineering/two-way/tw-01
uv run --locked --project engineering/two-way/tw-01 python engineering/two-way/tw-01/scripts/prepare-frame-data.py --out /tmp/two-way-contours
cmp /tmp/two-way-contours/frame-data.js engineering/two-way/tw-01/source/frame-data.js
```

出力を確認後、意図的な更新時のみ `source/frame-data.js` を置換する。
入力は既存 `engineering/r6-body/source-data/` のレール全頂点・全インデックスとPCB全輪郭。
7Uでは raw Y→U / raw X→V。配置は `placements.json`。
空の3U側面固定軸だけはR6 `configure()` の明示規則（中心±45、V=21.3105735）を採用する。
Shapely/GEOS版、入力SHAは焼き込みデータに残す。非多様体レールを修復しない。

## 単一計算源

`project/two-way/study-spec.json` が宣言入力。`source/model.js` の `dimensions()` が純粋な寸法・診断リゾルバー。
UI・設定・表・エクスポートは同じ結果を使う。F5近似切欠きから正規輪郭へ変更したが、外形・固定軸・積層は変更しない。
Cの48mm蓋も入力可能で、背板干渉を警告する。元PCBは切り縮めない。

F5 `zudo-case-study/5` の全state項目を保持し、TW-01 `zudo-case-two-way/1` へ変換する。
新schemaはfamilyId、mm/Z-upを要求する。derived、承認フラグ、外部URLは信用せず再計算。
F4、欠落・不正項目、未知familyは失敗し、UIの前状態を保持する。
有効な連続値の厚み・スタンド板厚・slider値も丸めず表示する。非対応のF5 state項目はない。

## ブラウザー（任意の開発環境）

```sh
npm install --prefix engineering/two-way/tw-01/tests/browser
engineering/two-way/tw-01/tests/browser/node_modules/.bin/playwright install chromium
pnpm test:two-way:browser --backend software
pnpm test:two-way:browser --backend webgl
```

`--out` に証拠出力ディレクトリ、`--url` にローカルHTTPビューアーを指定できる。
既存Chromiumは `TW_CHROMIUM`、既存Playwrightモジュールは `TW_PLAYWRIGHT_MODULE` で指定可能。
softwareはgetContextでWebGLを無効化して強制する。WebGLに落ちた場合はblockedで終了する。
レポートにブラウザー版・描画方式・TW-01 HTMLハッシュを記録。物理承認を意味しない。

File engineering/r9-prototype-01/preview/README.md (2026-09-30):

# R9-PROTOTYPE-01 preview

The viewer is a standalone offline HTML file built from the generated R9 STEP parts and placement manifests. It also includes the original pinned R6 40HP rail STL at 204 mm. The viewer does not use R8 meshes.

From the repository root, regenerate the geometry data and preview with the pinned CadQuery environment:

```sh
cd engineering/r9-prototype-01
uv run --locked python build.py --only body,slots,guards,lid,preview_data
cd preview
uv run python build.py
```

The generated mesh, section PNGs, section index, and file table live under `engineering/r9-prototype-01/out/preview/`. The built page is `public/previews/r9-prototype-01.html`. The single HTML contains its scripts, styles, mesh, section images, and file table; it makes no network requests. Rebuilding with unchanged inputs writes identical bytes.

## Manager-owned browser check

This workflow intentionally leaves browser launch and screenshot review to the integration manager. Install Playwright and its Chromium build in the local environment, then run:

```sh
uv run --with playwright playwright install chromium
uv run --with playwright python engineering/r9-prototype-01/preview/check_preview.py
```

The script opens only the local HTML, blocks HTTP(S) requests, records console and page errors, checks daily/travel/open states, verifies the 0–150 mm slider and part information, measures horizontal overflow at 390 px, and writes three screenshots to `engineering/r9-prototype-01/preview/shots/` plus `out/preview/browser-check.json`.

The manager should inspect the generated screenshots at desktop 1440 px and mobile 390 px, and confirm the lid lift, two travel bands, transparent envelope, slot section, guard fit/adhesive section, locator clearance section, and click-selected part dimensions. These are visual checks only; they do not validate physical fit, loads, transport, or manufacturing readiness.

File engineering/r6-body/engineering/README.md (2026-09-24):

# Zudo case family / R6 CAD

すべてmm。3モデルは `3u60/`, `7u40/`, `7u60/` に分けています。元レールSTL・PCB輪郭、ユーザー確認済みPCB厚1.6mm、スペーサー8mm、頭厚1.4mm、ブラケット実厚2mmを反映した設計です。

| モデル | 金属外形 W×D×H | レール | PCB | ブラケット | 外板穴 | ケース取付点 |
|---|---|---:|---:|---:|---:|---:|
| 3U60 | 330.4×154×91 | 2 | 4 | 16 | 36 | 4 |
| 7U40 | 229.4×334×91 | 6 | 8 | 18 | 46 | 10 |
| 7U60 | 330.4×334×91 | 6 | 8 | 18 | 46 | 10 |

7Uは3U+3U+1Uを同一平面に並べる深いトレーです。全モデルが底・前後・左右の5枚構成で、内部仕切り板はありません。

## アルミ板

各モデルの `aluminum/` に3種類5枚分のSTEP / STL / DXFがあります。DXFはmm、左下原点、閉外形とφ5.5真円穴です。寸法と穴中心は `aluminum/hole-layout.json`。前後は2枚同型です。3Uの左右板は同型ですが、7Uの左右板は穴配置が奥行方向に非対称です。板を裏返す扱いを含め、同一XY穴配置で左右へ設置する想定です。

ブラケット穴中心は内面から10mmという提案値で、実測された穴中心ではありません。長穴方向を推測して加工データへ固定することは避け、今回の外板はφ5.5丸穴としています。

## ガード

各モデルの `guards/` はSTEP、上位 `stl/<model>/<variant>/` は対応する単体STLと数量表です。

- 3U：4種類・12個、最大辺166.4mm（t1.2）。
- 7U：6種類・16個、最大辺168.2mm（t1.2）。上端は4つのL字、長い左右下辺も2分割。
- t1.2／t1.0を用意。各STLは1個分、ファイル名のqtyとmanifestが必要個数です。
- 公称接触すきま0mm。保持方法、接着層、嵌合公差は未確定です。
- 黒ゴム脚4個は既製貼付式を想定する別部品で、JLCガードのSTL・数量・体積には含めません。

## 底面と締結

側面／前後の接合は内側に低頭、外側に座金とナット。底板だけは低頭を外側、座金／ナットを内側へ反転しています。底頭下面はZ−1.4mm。φ10×3mmの貼付黒ゴム脚4個（未選定の仮寸法）は各外縁から20mm内側にあり、接地面Z−3mmと頭の間に1.6mmの差があります。脚用の穴は不要です。

取付部の模式ナット・軸長・頭径は現物採寸を置き換えるものではありません。外板内スペーサー8mmの頭下積層はfixer1.6+8+metal1.5+outer washer1=12.1mm。内側padderはこの締付積層に入りません。

## ソースと検証

- PCBの全Edge.Cuts頂点を保持。7Uの短手／長手の軸を正規化し、外形基準で2枚の3U padderと1枚の1U padderを並べています。
- パダー間の隙間は0.031860／0.031861mm。元の穴中心微差を変形・補正していません。
- 元レールSTLには重複面があり、修復せずビューアーに配置します。
- 各モデルのアセンブリーSTEPはアルミ・ブラケット・PCB・t1.2ガード・模式ゴム脚を含みます。生レールメッシュと模式締結材は含みません。
- `validation.json` はガードSTLのmanifold／正体積／CADとの差、DXF再読込、実体干渉、内側の頭とPCBの関係、底部座金／ナットと脚の干渉を記録しています。
- ブラケット実体は2mm。内側占有2.2mm・頭厚1.4mmで、レール端頭φ12を仮定した追加チェックではブラケットとの干渉なし、対向頭X包絡には3mmの隙間があります。
- そのφ12仮定では、7Uの隣接行レール端頭同士だけ、既存軸間11.9960175mmに対して約0.004mmの微小な包絡重複が発生します。ケース隙間の問題と分けて追加診断に記録し、表示用φ9との違いを明示しています。元fixerやrail間隔は変更していません。

`../design-parameters.json` と `../build_geometry.py` から再生成できます。依存はCadQuery2.7、NumPy、ezdxfです。実機強度、加工公差、ゴム脚材質や粘着、ガード保持は別途試作で確認する項目です。

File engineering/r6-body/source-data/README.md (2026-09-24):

# R6の入力ソース

- `rail60/`: 提供60HP STLの原本・未修復メッシュ・取付中心解析。実長305mm。
- `rail40/`: 提供40HP STLの原本・未修復メッシュ・取付中心解析。実長204mm。60HPと断面は一致。
- `panels/`: fixer3u/fixer7u/padder3u/padder1uの元KiCadと全輪郭、source commit/hash。
- `panels/placements.json`: 7Uを3U+3U+1Uとするレール軸、パダー配置、選択した5個/側のM5位置、頭と窓の余裕を収録。

元の解析スナップショットにある初期案の5mmスペーサーや未確認板厚の記述は、その後のユーザー指定により更新されています。現在の条件は上位 `design-parameters.json` にあるPCB厚1.6mm、スペーサー8mm、頭厚1.4mm、ブラケット実厚2mmです。元STLとPCBファイルは変更していません。

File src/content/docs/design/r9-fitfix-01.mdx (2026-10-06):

---
title: "7U40 R9-FITFIX-01 修正候補"
description: "金属への侵入、ガード実肉厚、蓋座面を修正した未承認候補。"
sidebar_position: 80
---

7U40の現行候補は **R9-FITFIX-01（未承認）**。下辺ガードをL字にし、上端の内側返しを矩形リングの内周へ限定した。横方向の嵌合・接着空間と実肉厚を分離し、金属上端に直接着座する屋根から蓋座面を導く。旧[R9-PROTOTYPE-01](./r9-prototype-01.mdx)は修正前の履歴として保存する。

<PreviewLink path="/previews/r9-fitfix-01.html">修正候補を別タブで開く</PreviewLink>

<PreviewLink path="/previews/r9-order-map.html">注文した試験片の位置を見る / Ordered fit tests (English)</PreviewLink>

<PreviewFrame path="/previews/r9-fitfix-01.html" title="R9-FITFIX-01 7U40・ガード・蓋・試験片" />

プレビューは同じ生成CADの三角形を内蔵する。1.2/1.0mm、蓋の開閉、C1/C2/C4/C5を切り替えられる。バンドは模式表示、断面は表示用。WebGLが使えない環境ではCanvas簡易描画へ切り替わる。

## 寸法と支持面

| 項目 | 基本1.2mm | 比較1.0mm |
|---|---:|---:|
| ガード外形W×D | 232.4×337.0mm | 232.0×336.6mm |
| ガード上端・蓋座面Z | 92.2mm | 92.0mm |
| ガード全高（脚を除く） | 93.4mm | 93.0mm |
| 天板下面Z | 122.2mm | 122.0mm |
| 蓋天板 | 228.2×332.8×1.5mm | 227.8×332.4×1.5mm |

本体アルミは229.4×334×91mm。Z=0は底板下面。全高と上端座標は別の値である。1.2/1.0mm案ではガードだけでなく蓋枠・天板も専用品を使う。

側面の0.30mmはfit0.15＋adhesive0.15の空間配分候補。0.15mmテープの選定や保持性能を確認した意味ではない。屋根下面Z=91は金属上端へ直接当たり、下辺の水平フランジは底板下面へ直接当たる。上下の接着層を追加するなら座面高さを再設計する。

[小型試験片の見積準備セット](../manufacturing/fit-test-order.mdx)に、数量確定案・未送信文案・実物試験手順をまとめた。

## 材質別データと数量

- <PreviewLink path="/downloads/candidate/r9-fitfix-01-7u40-t1p2-pa12-NOT-APPROVED.zip">基本1.2mm・ガードと蓋枠PA12</PreviewLink>
- <PreviewLink path="/downloads/candidate/r9-fitfix-01-7u40-t1p0-pa12-NOT-APPROVED.zip">比較1.0mm・ガードと蓋枠PA12</PreviewLink>
- <PreviewLink path="/downloads/candidate/r9-fitfix-01-7u40-t1p2-aluminum-NOT-APPROVED.zip">基本1.2mm用・本体５枚＋蓋天板アルミ</PreviewLink>
- <PreviewLink path="/downloads/candidate/r9-fitfix-01-7u40-t1p0-aluminum-NOT-APPROVED.zip">比較1.0mm用・本体５枚＋蓋天板アルミ</PreviewLink>
- <PreviewLink path="/downloads/candidate/r9-fitfix-01-fit-coupons-pa12-NOT-APPROVED.zip">C1/C2/C4/C5・PA12試験片</PreviewLink>
- <PreviewLink path="/downloads/candidate/r9-fitfix-01-fit-coupons-metal-NOT-APPROVED.zip">試験片・アルミSTEP/DXF</PreviewLink>

本体ガードは各案16個、蓋枠4個。各ZIPのorder-tablesと `engineering/r9-fitfix-01/out/BOM.csv` のorder_quantityを使う。C1-06/07は各２個で対を作る。C2-02/03の壁・ガード・天板はC2-01から再利用し、数量0の部材を重複発注しない。本体３種類・蓋天板２案のSTEP/DXFは同フォルダーのaluminum内にある。

現在価格は未見積。旧R3の2,264円は本候補の価格ではない。

## 検証と残件

固定環境の再生成、回帰テスト、本体３パターンの旧R9 DXF照合、生成資産と公開コピーのSHA-256照合は `engineering/r9-fitfix-01/verification/` のローカル記録を参照する。生成時の公称検査は `out/validation.json`、Python/CadQueryの実行版は `out/environment.json` に記録する。

幾何検査はガード16個×穴を無視したアルミ５枚の侵入、主要平坦壁の厚さ、分割済みガードへの支持面積、0〜15mmの19位置での蓋着脱を対象とする。サンプル間の連続掃引や現物試験ではない。保存レールはSTL表示と保守的な外接箱、金具・PCBは保存元の公称形状を使う。

次はC1/C2/C4/C5で嵌合と接着保持を確認する。[空欄記録票](../verification/coupon-record.mdx)にファイルSHA-256、実板厚、表面処理、接着品番、観察を記入する。C3の座金受け面、ねじ・工具アクセス、実ノブ高さ、長い部品の反り、バンド締付と運搬は別途残る。G01〜G11の現物ゲートと製造承認は未完了。

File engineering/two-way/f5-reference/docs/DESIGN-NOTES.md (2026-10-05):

# F5 current design notes

Read [RAIL-FRAME-INTEGRATION.md](RAIL-FRAME-INTEGRATION.md) for the current geometry, dimensional corrections, source fidelity and limitations. It supersedes F4's placeholder rail geometry.

The unchanged transport/play concept is preserved in [the historical F4 notes](archive-F4/DESIGN-NOTES.md), but **F4 dimensions and validation results must not be reused as F5 results**.

No source PCB should be trimmed to make the previous shallow-lid drawing fit. C now has a 70 mm lid.

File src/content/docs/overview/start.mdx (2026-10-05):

---
title: "現在地と最初に読むページ"
description: "３機種の金属ケースを、現物確認・見積・発注へつなぐ。"
sidebar_position: 10
---

## 現在の計画

**黒アルマイトの平板アルミ５枚＋手持ちのL字ブラケット＋細い黒PA12ガード**でケースを作る。レールユニットは独立して取り外せる。蓋はアルミ板１枚とPA12枠からなる10BOX式の載せ蓋で、外へ持ち出すときだけ別体のバンド２本で保持する。

対象は3U・60HP、3U＋3U＋1U・40HP、3U＋3U＋1U・60HPの３機種。中心となるのは、リュックへ収めて持ち運ぶことを意図した**7U・40HP**である。

R8・7U40の運搬イメージ

:::warning[製作承認済みのデータはまだない]

採用仕様とCADの反映状態は一致していない。本体はR6の名目CAD、蓋はR8の表示モデルまで。**R8の製作用STL・STEP・DXF、ブラケット用の長穴、樹脂の嵌合・保持**を次に詰める。旧R7ロック蓋をそのまま注文しない。

:::

## 読む順序

| 目的 | ページ |
|---|---|
| 最終方針を確認する | [採用仕様とデータ状態](./status.mdx) |
| 全体を回して見る | [R8・載せ蓋のプレビュー](../resources/current-preview.mdx) |
| ３機種の差を見る | [機種比較](../models/comparison.mdx) |
| 発注までの残作業を進める | [発注前ゲート](../verification/before-order.mdx) |
| 何をいくつ買うか調べる | [BOM](../manufacturing/bom.mdx) |
| 価格の根拠を確認する | [見積と概算の区別](../manufacturing/costs.mdx) |
| ローカルでサイトを起動する | [セットアップ](../handoff/setup.mdx) |

## この文書の位置づけ

2026-09-24時点の会話・提供ファイルを整理した、設計／製作の引継ぎ資料である。今回の整理作業で新しいケースCADを作ったり、荷重試験を実施したり、業者へ注文したりしたわけではない。

数字の根拠は、ユーザー実測、元STL/PCB、保存済みのCAD計算、表示用仮定、過去の価格予測を区別する。[根拠の扱い](./scope.mdx)と[資料台帳](../resources/sources.mdx)を参照。

## 独立した2WAYの実験設計

[2WAY / TW-01](../two-way/index.mdx)は2つのモジュール入りトレーを使う別系列です。現行R9製作候補や既存3機種の仕様は変更しません。

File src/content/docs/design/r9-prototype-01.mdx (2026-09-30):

---
title: "7U40 R9 製作候補"
description: "R9-PROTOTYPE-01の形状、出力と未検証事項を同じ版で確認する。"
sidebar_position: 70
---

**修正前の履歴です。現行候補は[R9-FITFIX-01](./r9-fitfix-01.mdx)。以下のファイルを現行候補と混在させないでください。**

**R9-PROTOTYPE-01は7U40だけの製作候補・未承認。** 有償試作、量産、発注の指示ではない。

<PreviewLink path="/previews/r9-prototype-01.html">R9の3Dプレビュー</PreviewLink>。形状の概観には使えるが、嵌合・荷重の現物結果ではない。CADと数量は`engineering/r9-prototype-01/out/`、検査範囲は`out/validation.json`、版とファイルの正本は`out/preview/file-table.json`にある。

## 版とファイル

この表は生成済み`out/preview/file-table.json`から`node scripts/sync-r9-doc-table.mjs`で生成する。再生成時は表と断面画像の公開コピーも更新する。各行は１台分の部品パターン。元ファイルのSHA-256はJSONで、ZIPの収録物はZIP内`package-manifest.json`で照合する。表の元形式すべてがZIPへ収録されるわけではない（アルミZIPはDXF/STEP）。表示専用の`hardware-envelopes`は除外した。

<table data-r9-file-table="generated">
<thead><tr><th>版・部品ID</th><th>名称・数量</th><th>形式と元ファイル</th><th>候補ZIP</th></tr></thead>
<tbody>
<tr><td>R9-PROTOTYPE-01<br />7U40-R9-AL-BOTTOM</td><td>底板 × 1</td><td><div>DXF: <code>engineering/r9-prototype-01/out/aluminum/7u40-r9-al-bottom-qty1-mm.dxf</code></div><div>STEP: <code>engineering/r9-prototype-01/out/aluminum/7u40-r9-al-bottom-qty1-mm.step</code></div><div>STL: <code>engineering/r9-prototype-01/out/aluminum/7u40-r9-al-bottom-qty1-mm.stl</code></div></td><td>7u40-r9-prototype-01-aluminum-NOT-APPROVED.zip</td></tr>
<tr><td>R9-PROTOTYPE-01<br />7U40-R9-AL-FRONT-BACK</td><td>前板・後板 × 2</td><td><div>DXF: <code>engineering/r9-prototype-01/out/aluminum/7u40-r9-al-front-back-qty2-mm.dxf</code></div><div>STEP: <code>engineering/r9-prototype-01/out/aluminum/7u40-r9-al-front-back-qty2-mm.step</code></div><div>STL: <code>engineering/r9-prototype-01/out/aluminum/7u40-r9-al-front-back-qty2-mm.stl</code></div></td><td>7u40-r9-prototype-01-aluminum-NOT-APPROVED.zip</td></tr>
<tr><td>R9-PROTOTYPE-01<br />7U40-R9-AL-LEFT-RIGHT</td><td>左板・右板 × 2</td><td><div>DXF: <code>engineering/r9-prototype-01/out/aluminum/7u40-r9-al-left-right-qty2-mm.dxf</code></div><div>STEP: <code>engineering/r9-prototype-01/out/aluminum/7u40-r9-al-left-right-qty2-mm.step</code></div><div>STL: <code>engineering/r9-prototype-01/out/aluminum/7u40-r9-al-left-right-qty2-mm.stl</code></div></td><td>7u40-r9-prototype-01-aluminum-NOT-APPROVED.zip</td></tr>
<tr><td>R9-PROTOTYPE-01<br />7U40-R9-CPN-C1-01</td><td>7u40-r9-cpn-c1-01 × 1</td><td><div>STEP: <code>engineering/r9-prototype-01/out/coupons/7u40-r9-cpn-c1-01-qty1-mm.step</code></div><div>STL: <code>engineering/r9-prototype-01/out/coupons/7u40-r9-cpn-c1-01-qty1-mm.stl</code></div></td><td>7u40-r9-prototype-01-coupons-NOT-APPROVED.zip</td></tr>
<tr><td>R9-PROTOTYPE-01<br />7U40-R9-CPN-C1-02</td><td>7u40-r9-cpn-c1-02 × 1</td><td><div>STEP: <code>engineering/r9-prototype-01/out/coupons/7u40-r9-cpn-c1-02-qty1-mm.step</code></div><div>STL: <code>engineering/r9-prototype-01/out/coupons/7u40-r9-cpn-c1-02-qty1-mm.stl</code></div></td><td>7u40-r9-prototype-01-coupons-NOT-APPROVED.zip</td></tr>
<tr><td>R9-PROTOTYPE-01<br />7U40-R9-CPN-C1-03</td><td>7u40-r9-cpn-c1-03 × 1</td><td><div>STEP: <code>engineering/r9-prototype-01/out/coupons/7u40-r9-cpn-c1-03-qty1-mm.step</code></div><div>STL: <code>engineering/r9-prototype-01/out/coupons/7u40-r9-cpn-c1-03-qty1-mm.stl</code></div></td><td>7u40-r9-prototype-01-coupons-NOT-APPROVED.zip</td></tr>
<tr><td>R9-PROTOTYPE-01<br />7U40-R9-CPN-C1-04</td><td>7u40-r9-cpn-c1-04 × 1</td><td><div>STEP: <code>engineering/r9-prototype-01/out/coupons/7u40-r9-cpn-c1-04-qty1-mm.step</code></div><div>STL: <code>engineering/r9-prototype-01/out/coupons/7u40-r9-cpn-c1-04-qty1-mm.stl</code></div></td><td>7u40-r9-prototype-01-coupons-NOT-APPROVED.zip</td></tr>
<tr><td>R9-PROTOTYPE-01<br />7U40-R9-CPN-C1-05</td><td>7u40-r9-cpn-c1-05 × 1</td><td><div>STEP: <code>engineering/r9-prototype-01/out/coupons/7u40-r9-cpn-c1-05-qty1-mm.step</code></div><div>STL: <code>engineering/r9-prototype-01/out/coupons/7u40-r9-cpn-c1-05-qty1-mm.stl</code></div></td><td>7u40-r9-prototype-01-coupons-NOT-APPROVED.zip</td></tr>
<tr><td>R9-PROTOTYPE-01<br />7U40-R9-CPN-C1-06-A</td><td>7u40-r9-cpn-c1-06-a × 1</td><td><div>STEP: <code>engineering/r9-prototype-01/out/coupons/7u40-r9-cpn-c1-06-a-qty1-mm.step</code></div><div>STL: <code>engineering/r9-prototype-01/out/coupons/7u40-r9-cpn-c1-06-a-qty1-mm.stl</code></div></td><td>7u40-r9-prototype-01-coupons-NOT-APPROVED.zip</td></tr>
<tr><td>R9-PROTOTYPE-01<br />7U40-R9-CPN-C1-06-B</td><td>7u40-r9-cpn-c1-06-b × 1</td><td><div>STEP: <code>engineering/r9-prototype-01/out/coupons/7u40-r9-cpn-c1-06-b-qty1-mm.step</code></div><div>STL: <code>engineering/r9-prototype-01/out/coupons/7u40-r9-cpn-c1-06-b-qty1-mm.stl</code></div></td><td>7u40-r9-prototype-01-coupons-NOT-APPROVED.zip</td></tr>
<tr><td>R9-PROTOTYPE-01<br />7U40-R9-CPN-C1-07-A</td><td>7u40-r9-cpn-c1-07-a × 1</td><td><div>STEP: <code>engineering/r9-prototype-01/out/coupons/7u40-r9-cpn-c1-07-a-qty1-mm.step</code></div><div>STL: <code>engineering/r9-prototype-01/out/coupons/7u40-r9-cpn-c1-07-a-qty1-mm.stl</code></div></td><td>7u40-r9-prototype-01-coupons-NOT-APPROVED.zip</td></tr>
<tr><td>R9-PROTOTYPE-01<br />7U40-R9-CPN-C1-07-B</td><td>7u40-r9-cpn-c1-07-b × 1</td><td><div>STEP: <code>engineering/r9-prototype-01/out/coupons/7u40-r9-cpn-c1-07-b-qty1-mm.step</code></div><div>STL: <code>engineering/r9-prototype-01/out/coupons/7u40-r9-cpn-c1-07-b-qty1-mm.stl</code></div></td><td>7u40-r9-prototype-01-coupons-NOT-APPROVED.zip</td></tr>
<tr><td>R9-PROTOTYPE-01<br />7U40-R9-CPN-C1-AL-EDGE</td><td>7u40-r9-cpn-c1-al-edge × 1</td><td><div>DXF: <code>engineering/r9-prototype-01/out/coupons/7u40-r9-cpn-c1-al-edge-qty1-mm.dxf</code></div><div>STEP: <code>engineering/r9-prototype-01/out/coupons/7u40-r9-cpn-c1-al-edge-qty1-mm.step</code></div></td><td>7u40-r9-prototype-01-coupons-NOT-APPROVED.zip</td></tr>
<tr><td>R9-PROTOTYPE-01<br />7U40-R9-CPN-C2-01-BODY-WALL</td><td>7u40-r9-cpn-c2-01-body-wall × 1</td><td><div>DXF: <code>engineering/r9-prototype-01/out/coupons/c2/c2-01/7u40-r9-cpn-c2-01-body-wall-qty1-mm.dxf</code></div><div>STEP: <code>engineering/r9-prototype-01/out/coupons/c2/c2-01/7u40-r9-cpn-c2-01-body-wall-qty1-mm.step</code></div><div>STL: <code>engineering/r9-prototype-01/out/coupons/c2/c2-01/7u40-r9-cpn-c2-01-body-wall-qty1-mm.stl</code></div></td><td>7u40-r9-prototype-01-coupons-NOT-APPROVED.zip</td></tr>
<tr><td>R9-PROTOTYPE-01<br />7U40-R9-CPN-C2-01-GUARD</td><td>7u40-r9-cpn-c2-01-guard × 1</td><td><div>STEP: <code>engineering/r9-prototype-01/out/coupons/c2/c2-01/7u40-r9-cpn-c2-01-guard-qty1-mm.step</code></div><div>STL: <code>engineering/r9-prototype-01/out/coupons/c2/c2-01/7u40-r9-cpn-c2-01-guard-qty1-mm.stl</code></div></td><td>7u40-r9-prototype-01-coupons-NOT-APPROVED.zip</td></tr>
<tr><td>R9-PROTOTYPE-01<br />7U40-R9-CPN-C2-01-LID-FRAME</td><td>7u40-r9-cpn-c2-01-lid-frame × 1</td><td><div>STEP: <code>engineering/r9-prototype-01/out/coupons/c2/c2-01/7u40-r9-cpn-c2-01-lid-frame-qty1-mm.step</code></div><div>STL: <code>engineering/r9-prototype-01/out/coupons/c2/c2-01/7u40-r9-cpn-c2-01-lid-frame-qty1-mm.stl</code></div></td><td>7u40-r9-prototype-01-coupons-NOT-APPROVED.zip</td></tr>
<tr><td>R9-PROTOTYPE-01<br />7U40-R9-CPN-C2-01-LID-PLATE</td><td>7u40-r9-cpn-c2-01-lid-plate × 1</td><td><div>DXF: <code>engineering/r9-prototype-01/out/coupons/c2/c2-01/7u40-r9-cpn-c2-01-lid-plate-qty1-mm.dxf</code></div><div>STEP: <code>engineering/r9-prototype-01/out/coupons/c2/c2-01/7u40-r9-cpn-c2-01-lid-plate-qty1-mm.step</code></div><div>STL: <code>engineering/r9-prototype-01/out/coupons/c2/c2-01/7u40-r9-cpn-c2-01-lid-plate-qty1-mm.stl</code></div></td><td>7u40-r9-prototype-01-coupons-NOT-APPROVED.zip</td></tr>
<tr><td>R9-PROTOTYPE-01<br />7U40-R9-CPN-C2-01-RAIL-ENVELOPE</td><td>7u40-r9-cpn-c2-01-rail-envelope × 1</td><td><div>STEP: <code>engineering/r9-prototype-01/out/coupons/c2/c2-01/7u40-r9-cpn-c2-01-rail-envelope-qty1-mm.step</code></div><div>STL: <code>engineering/r9-prototype-01/out/coupons/c2/c2-01/7u40-r9-cpn-c2-01-rail-envelope-qty1-mm.stl</code></div></td><td>7u40-r9-prototype-01-coupons-NOT-APPROVED.zip</td></tr>
<tr><td>R9-PROTOTYPE-01<br />7U40-R9-CPN-C2-02-BODY-WALL</td><td>7u40-r9-cpn-c2-02-body-wall × 1</td><td><div>DXF: <code>engineering/r9-prototype-01/out/coupons/c2/c2-02/7u40-r9-cpn-c2-02-body-wall-qty1-mm.dxf</code></div><div>STEP: <code>engineering/r9-prototype-01/out/coupons/c2/c2-02/7u40-r9-cpn-c2-02-body-wall-qty1-mm.step</code></div><div>STL: <code>engineering/r9-prototype-01/out/coupons/c2/c2-02/7u40-r9-cpn-c2-02-body-wall-qty1-mm.stl</code></div></td><td>7u40-r9-prototype-01-coupons-NOT-APPROVED.zip</td></tr>
<tr><td>R9-PROTOTYPE-01<br />7U40-R9-CPN-C2-02-GUARD</td><td>7u40-r9-cpn-c2-02-guard × 1</td><td><div>STEP: <code>engineering/r9-prototype-01/out/coupons/c2/c2-02/7u40-r9-cpn-c2-02-guard-qty1-mm.step</code></div><div>STL: <code>engineering/r9-prototype-01/out/coupons/c2/c2-02/7u40-r9-cpn-c2-02-guard-qty1-mm.stl</code></div></td><td>7u40-r9-prototype-01-coupons-NOT-APPROVED.zip</td></tr>
<tr><td>R9-PROTOTYPE-01<br />7U40-R9-CPN-C2-02-LID-FRAME</td><td>7u40-r9-cpn-c2-02-lid-frame × 1</td><td><div>STEP: <code>engineering/r9-prototype-01/out/coupons/c2/c2-02/7u40-r9-cpn-c2-02-lid-frame-qty1-mm.step</code></div><div>STL: <code>engineering/r9-prototype-01/out/coupons/c2/c2-02/7u40-r9-cpn-c2-02-lid-frame-qty1-mm.stl</code></div></td><td>7u40-r9-prototype-01-coupons-NOT-APPROVED.zip</td></tr>
<tr><td>R9-PROTOTYPE-01<br />7U40-R9-CPN-C2-02-LID-PLATE</td><td>7u40-r9-cpn-c2-02-lid-plate × 1</td><td><div>DXF: <code>engineering/r9-prototype-01/out/coupons/c2/c2-02/7u40-r9-cpn-c2-02-lid-plate-qty1-mm.dxf</code></div><div>STEP: <code>engineering/r9-prototype-01/out/coupons/c2/c2-02/7u40-r9-cpn-c2-02-lid-plate-qty1-mm.step</code></div><div>STL: <code>engineering/r9-prototype-01/out/coupons/c2/c2-02/7u40-r9-cpn-c2-02-lid-plate-qty1-mm.stl</code></div></td><td>7u40-r9-prototype-01-coupons-NOT-APPROVED.zip</td></tr>
<tr><td>R9-PROTOTYPE-01<br />7U40-R9-CPN-C2-02-RAIL-ENVELOPE</td><td>7u40-r9-cpn-c2-02-rail-envelope × 1</td><td><div>STEP: <code>engineering/r9-prototype-01/out/coupons/c2/c2-02/7u40-r9-cpn-c2-02-rail-envelope-qty1-mm.step</code></div><div>STL: <code>engineering/r9-prototype-01/out/coupons/c2/c2-02/7u40-r9-cpn-c2-02-rail-envelope-qty1-mm.stl</code></div></td><td>7u40-r9-prototype-01-coupons-NOT-APPROVED.zip</td></tr>
<tr><td>R9-PROTOTYPE-01<br />7U40-R9-CPN-C2-03-BODY-WALL</td><td>7u40-r9-cpn-c2-03-body-wall × 1</td><td><div>DXF: <code>engineering/r9-prototype-01/out/coupons/c2/c2-03/7u40-r9-cpn-c2-03-body-wall-qty1-mm.dxf</code></div><div>STEP: <code>engineering/r9-prototype-01/out/coupons/c2/c2-03/7u40-r9-cpn-c2-03-body-wall-qty1-mm.step</code></div><div>STL: <code>engineering/r9-prototype-01/out/coupons/c2/c2-03/7u40-r9-cpn-c2-03-body-wall-qty1-mm.stl</code></div></td><td>7u40-r9-prototype-01-coupons-NOT-APPROVED.zip</td></tr>
<tr><td>R9-PROTOTYPE-01<br />7U40-R9-CPN-C2-03-GUARD</td><td>7u40-r9-cpn-c2-03-guard × 1</td><td><div>STEP: <code>engineering/r9-prototype-01/out/coupons/c2/c2-03/7u40-r9-cpn-c2-03-guard-qty1-mm.step</code></div><div>STL: <code>engineering/r9-prototype-01/out/coupons/c2/c2-03/7u40-r9-cpn-c2-03-guard-qty1-mm.stl</code></div></td><td>7u40-r9-prototype-01-coupons-NOT-APPROVED.zip</td></tr>
<tr><td>R9-PROTOTYPE-01<br />7U40-R9-CPN-C2-03-LID-FRAME</td><td>7u40-r9-cpn-c2-03-lid-frame × 1</td><td><div>STEP: <code>engineering/r9-prototype-01/out/coupons/c2/c2-03/7u40-r9-cpn-c2-03-lid-frame-qty1-mm.step</code></div><div>STL: <code>engineering/r9-prototype-01/out/coupons/c2/c2-03/7u40-r9-cpn-c2-03-lid-frame-qty1-mm.stl</code></div></td><td>7u40-r9-prototype-01-coupons-NOT-APPROVED.zip</td></tr>
<tr><td>R9-PROTOTYPE-01<br />7U40-R9-CPN-C2-03-LID-PLATE</td><td>7u40-r9-cpn-c2-03-lid-plate × 1</td><td><div>DXF: <code>engineering/r9-prototype-01/out/coupons/c2/c2-03/7u40-r9-cpn-c2-03-lid-plate-qty1-mm.dxf</code></div><div>STEP: <code>engineering/r9-prototype-01/out/coupons/c2/c2-03/7u40-r9-cpn-c2-03-lid-plate-qty1-mm.step</code></div><div>STL: <code>engineering/r9-prototype-01/out/coupons/c2/c2-03/7u40-r9-cpn-c2-03-lid-plate-qty1-mm.stl</code></div></td><td>7u40-r9-prototype-01-coupons-NOT-APPROVED.zip</td></tr>
<tr><td>R9-PROTOTYPE-01<br />7U40-R9-CPN-C2-03-RAIL-ENVELOPE</td><td>7u40-r9-cpn-c2-03-rail-envelope × 1</td><td><div>STEP: <code>engineering/r9-prototype-01/out/coupons/c2/c2-03/7u40-r9-cpn-c2-03-rail-envelope-qty1-mm.step</code></div><div>STL: <code>engineering/r9-prototype-01/out/coupons/c2/c2-03/7u40-r9-cpn-c2-03-rail-envelope-qty1-mm.stl</code></div></td><td>7u40-r9-prototype-01-coupons-NOT-APPROVED.zip</td></tr>
<tr><td>R9-PROTOTYPE-01<br />7U40-R9-CPN-C3-01-BOTTOM</td><td>7u40-r9-cpn-c3-01-bottom × 1</td><td><div>DXF: <code>engineering/r9-prototype-01/out/coupons/7u40-r9-cpn-c3-01-bottom-qty1-mm.dxf</code></div><div>STEP: <code>engineering/r9-prototype-01/out/coupons/7u40-r9-cpn-c3-01-bottom-qty1-mm.step</code></div></td><td>7u40-r9-prototype-01-coupons-NOT-APPROVED.zip</td></tr>
<tr><td>R9-PROTOTYPE-01<br />7U40-R9-CPN-C3-01-WALL</td><td>7u40-r9-cpn-c3-01-wall × 1</td><td><div>DXF: <code>engineering/r9-prototype-01/out/coupons/7u40-r9-cpn-c3-01-wall-qty1-mm.dxf</code></div><div>STEP: <code>engineering/r9-prototype-01/out/coupons/7u40-r9-cpn-c3-01-wall-qty1-mm.step</code></div></td><td>7u40-r9-prototype-01-coupons-NOT-APPROVED.zip</td></tr>
<tr><td>R9-PROTOTYPE-01<br />7U40-R9-CPN-C3-02-BOTTOM</td><td>7u40-r9-cpn-c3-02-bottom × 1</td><td><div>DXF: <code>engineering/r9-prototype-01/out/coupons/7u40-r9-cpn-c3-02-bottom-qty1-mm.dxf</code></div><div>STEP: <code>engineering/r9-prototype-01/out/coupons/7u40-r9-cpn-c3-02-bottom-qty1-mm.step</code></div></td><td>7u40-r9-prototype-01-coupons-NOT-APPROVED.zip</td></tr>
<tr><td>R9-PROTOTYPE-01<br />7U40-R9-CPN-C3-02-WALL</td><td>7u40-r9-cpn-c3-02-wall × 1</td><td><div>DXF: <code>engineering/r9-prototype-01/out/coupons/7u40-r9-cpn-c3-02-wall-qty1-mm.dxf</code></div><div>STEP: <code>engineering/r9-prototype-01/out/coupons/7u40-r9-cpn-c3-02-wall-qty1-mm.step</code></div></td><td>7u40-r9-prototype-01-coupons-NOT-APPROVED.zip</td></tr>
<tr><td>R9-PROTOTYPE-01<br />7U40-R9-CPN-C3-03-BOTTOM</td><td>7u40-r9-cpn-c3-03-bottom × 1</td><td><div>DXF: <code>engineering/r9-prototype-01/out/coupons/7u40-r9-cpn-c3-03-bottom-qty1-mm.dxf</code></div><div>STEP: <code>engineering/r9-prototype-01/out/coupons/7u40-r9-cpn-c3-03-bottom-qty1-mm.step</code></div></td><td>7u40-r9-prototype-01-coupons-NOT-APPROVED.zip</td></tr>
<tr><td>R9-PROTOTYPE-01<br />7U40-R9-CPN-C3-03-WALL</td><td>7u40-r9-cpn-c3-03-wall × 1</td><td><div>DXF: <code>engineering/r9-prototype-01/out/coupons/7u40-r9-cpn-c3-03-wall-qty1-mm.dxf</code></div><div>STEP: <code>engineering/r9-prototype-01/out/coupons/7u40-r9-cpn-c3-03-wall-qty1-mm.step</code></div></td><td>7u40-r9-prototype-01-coupons-NOT-APPROVED.zip</td></tr>
<tr><td>R9-PROTOTYPE-01<br />7U40-R9-LID-PLATE</td><td>載せ蓋アルミ板 × 1</td><td><div>DXF: <code>engineering/r9-prototype-01/out/aluminum/7u40-r9-lid-plate-qty1-mm.dxf</code></div><div>STEP: <code>engineering/r9-prototype-01/out/aluminum/7u40-r9-lid-plate-qty1-mm.step</code></div><div>STL: <code>engineering/r9-prototype-01/out/aluminum/7u40-r9-lid-plate-qty1-mm.stl</code></div></td><td>7u40-r9-prototype-01-aluminum-NOT-APPROVED.zip</td></tr>
<tr><td>R9-PROTOTYPE-01<br />7U40-R9-PA12-GUARD-T1P0-LOWER-DEPTH-A</td><td>7U40-R9-PA12-GUARD-T1P0-LOWER-DEPTH-A × 2</td><td><div>STEP: <code>engineering/r9-prototype-01/out/pa12/guards/t1p0/7u40-r9-pa12-guard-t1p0-lower-depth-a-qty2-mm.step</code></div><div>STL: <code>engineering/r9-prototype-01/out/pa12/guards/t1p0/7u40-r9-pa12-guard-t1p0-lower-depth-a-qty2-mm.stl</code></div></td><td>7u40-r9-prototype-01-pa12-NOT-APPROVED.zip</td></tr>
<tr><td>R9-PROTOTYPE-01<br />7U40-R9-PA12-GUARD-T1P0-LOWER-DEPTH-B</td><td>7U40-R9-PA12-GUARD-T1P0-LOWER-DEPTH-B × 2</td><td><div>STEP: <code>engineering/r9-prototype-01/out/pa12/guards/t1p0/7u40-r9-pa12-guard-t1p0-lower-depth-b-qty2-mm.step</code></div><div>STL: <code>engineering/r9-prototype-01/out/pa12/guards/t1p0/7u40-r9-pa12-guard-t1p0-lower-depth-b-qty2-mm.stl</code></div></td><td>7u40-r9-prototype-01-pa12-NOT-APPROVED.zip</td></tr>
<tr><td>R9-PROTOTYPE-01<br />7U40-R9-PA12-GUARD-T1P0-LOWER-WIDTH-HALF</td><td>7U40-R9-PA12-GUARD-T1P0-LOWER-WIDTH-HALF × 4</td><td><div>STEP: <code>engineering/r9-prototype-01/out/pa12/guards/t1p0/7u40-r9-pa12-guard-t1p0-lower-width-half-qty4-mm.step</code></div><div>STL: <code>engineering/r9-prototype-01/out/pa12/guards/t1p0/7u40-r9-pa12-guard-t1p0-lower-width-half-qty4-mm.stl</code></div></td><td>7u40-r9-prototype-01-pa12-NOT-APPROVED.zip</td></tr>
<tr><td>R9-PROTOTYPE-01<br />7U40-R9-PA12-GUARD-T1P0-TOP-A</td><td>7U40-R9-PA12-GUARD-T1P0-TOP-A × 2</td><td><div>STEP: <code>engineering/r9-prototype-01/out/pa12/guards/t1p0/7u40-r9-pa12-guard-t1p0-top-a-qty2-mm.step</code></div><div>STL: <code>engineering/r9-prototype-01/out/pa12/guards/t1p0/7u40-r9-pa12-guard-t1p0-top-a-qty2-mm.stl</code></div></td><td>7u40-r9-prototype-01-pa12-NOT-APPROVED.zip</td></tr>
<tr><td>R9-PROTOTYPE-01<br />7U40-R9-PA12-GUARD-T1P0-TOP-B</td><td>7U40-R9-PA12-GUARD-T1P0-TOP-B × 2</td><td><div>STEP: <code>engineering/r9-prototype-01/out/pa12/guards/t1p0/7u40-r9-pa12-guard-t1p0-top-b-qty2-mm.step</code></div><div>STL: <code>engineering/r9-prototype-01/out/pa12/guards/t1p0/7u40-r9-pa12-guard-t1p0-top-b-qty2-mm.stl</code></div></td><td>7u40-r9-prototype-01-pa12-NOT-APPROVED.zip</td></tr>
<tr><td>R9-PROTOTYPE-01<br />7U40-R9-PA12-GUARD-T1P0-VERTICAL-CORNER</td><td>7U40-R9-PA12-GUARD-T1P0-VERTICAL-CORNER × 4</td><td><div>STEP: <code>engineering/r9-prototype-01/out/pa12/guards/t1p0/7u40-r9-pa12-guard-t1p0-vertical-corner-qty4-mm.step</code></div><div>STL: <code>engineering/r9-prototype-01/out/pa12/guards/t1p0/7u40-r9-pa12-guard-t1p0-vertical-corner-qty4-mm.stl</code></div></td><td>7u40-r9-prototype-01-pa12-NOT-APPROVED.zip</td></tr>
<tr><td>R9-PROTOTYPE-01<br />7U40-R9-PA12-GUARD-T1P2-LOWER-DEPTH-A</td><td>7U40-R9-PA12-GUARD-T1P2-LOWER-DEPTH-A × 2</td><td><div>STEP: <code>engineering/r9-prototype-01/out/pa12/guards/t1p2/7u40-r9-pa12-guard-t1p2-lower-depth-a-qty2-mm.step</code></div><div>STL: <code>engineering/r9-prototype-01/out/pa12/guards/t1p2/7u40-r9-pa12-guard-t1p2-lower-depth-a-qty2-mm.stl</code></div></td><td>7u40-r9-prototype-01-pa12-NOT-APPROVED.zip</td></tr>
<tr><td>R9-PROTOTYPE-01<br />7U40-R9-PA12-GUARD-T1P2-LOWER-DEPTH-B</td><td>7U40-R9-PA12-GUARD-T1P2-LOWER-DEPTH-B × 2</td><td><div>STEP: <code>engineering/r9-prototype-01/out/pa12/guards/t1p2/7u40-r9-pa12-guard-t1p2-lower-depth-b-qty2-mm.step</code></div><div>STL: <code>engineering/r9-prototype-01/out/pa12/guards/t1p2/7u40-r9-pa12-guard-t1p2-lower-depth-b-qty2-mm.stl</code></div></td><td>7u40-r9-prototype-01-pa12-NOT-APPROVED.zip</td></tr>
<tr><td>R9-PROTOTYPE-01<br />7U40-R9-PA12-GUARD-T1P2-LOWER-WIDTH-HALF</td><td>7U40-R9-PA12-GUARD-T1P2-LOWER-WIDTH-HALF × 4</td><td><div>STEP: <code>engineering/r9-prototype-01/out/pa12/guards/t1p2/7u40-r9-pa12-guard-t1p2-lower-width-half-qty4-mm.step</code></div><div>STL: <code>engineering/r9-prototype-01/out/pa12/guards/t1p2/7u40-r9-pa12-guard-t1p2-lower-width-half-qty4-mm.stl</code></div></td><td>7u40-r9-prototype-01-pa12-NOT-APPROVED.zip</td></tr>
<tr><td>R9-PROTOTYPE-01<br />7U40-R9-PA12-GUARD-T1P2-TOP-A</td><td>7U40-R9-PA12-GUARD-T1P2-TOP-A × 2</td><td><div>STEP: <code>engineering/r9-prototype-01/out/pa12/guards/t1p2/7u40-r9-pa12-guard-t1p2-top-a-qty2-mm.step</code></div><div>STL: <code>engineering/r9-prototype-01/out/pa12/guards/t1p2/7u40-r9-pa12-guard-t1p2-top-a-qty2-mm.stl</code></div></td><td>7u40-r9-prototype-01-pa12-NOT-APPROVED.zip</td></tr>
<tr><td>R9-PROTOTYPE-01<br />7U40-R9-PA12-GUARD-T1P2-TOP-B</td><td>7U40-R9-PA12-GUARD-T1P2-TOP-B × 2</td><td><div>STEP: <code>engineering/r9-prototype-01/out/pa12/guards/t1p2/7u40-r9-pa12-guard-t1p2-top-b-qty2-mm.step</code></div><div>STL: <code>engineering/r9-prototype-01/out/pa12/guards/t1p2/7u40-r9-pa12-guard-t1p2-top-b-qty2-mm.stl</code></div></td><td>7u40-r9-prototype-01-pa12-NOT-APPROVED.zip</td></tr>
<tr><td>R9-PROTOTYPE-01<br />7U40-R9-PA12-GUARD-T1P2-VERTICAL-CORNER</td><td>7U40-R9-PA12-GUARD-T1P2-VERTICAL-CORNER × 4</td><td><div>STEP: <code>engineering/r9-prototype-01/out/pa12/guards/t1p2/7u40-r9-pa12-guard-t1p2-vertical-corner-qty4-mm.step</code></div><div>STL: <code>engineering/r9-prototype-01/out/pa12/guards/t1p2/7u40-r9-pa12-guard-t1p2-vertical-corner-qty4-mm.stl</code></div></td><td>7u40-r9-prototype-01-pa12-NOT-APPROVED.zip</td></tr>
<tr><td>R9-PROTOTYPE-01<br />7U40-R9-PA12-LID-FRAME-BL</td><td>PA12蓋枠 / BL × 1</td><td><div>STEP: <code>engineering/r9-prototype-01/out/pa12/lid/7u40-r9-pa12-lid-frame-bl-qty1-mm.step</code></div><div>STL: <code>engineering/r9-prototype-01/out/pa12/lid/7u40-r9-pa12-lid-frame-bl-qty1-mm.stl</code></div></td><td>7u40-r9-prototype-01-pa12-NOT-APPROVED.zip</td></tr>
<tr><td>R9-PROTOTYPE-01<br />7U40-R9-PA12-LID-FRAME-BR</td><td>PA12蓋枠 / BR × 1</td><td><div>STEP: <code>engineering/r9-prototype-01/out/pa12/lid/7u40-r9-pa12-lid-frame-br-qty1-mm.step</code></div><div>STL: <code>engineering/r9-prototype-01/out/pa12/lid/7u40-r9-pa12-lid-frame-br-qty1-mm.stl</code></div></td><td>7u40-r9-prototype-01-pa12-NOT-APPROVED.zip</td></tr>
<tr><td>R9-PROTOTYPE-01<br />7U40-R9-PA12-LID-FRAME-FL</td><td>PA12蓋枠 / FL × 1</td><td><div>STEP: <code>engineering/r9-prototype-01/out/pa12/lid/7u40-r9-pa12-lid-frame-fl-qty1-mm.step</code></div><div>STL: <code>engineering/r9-prototype-01/out/pa12/lid/7u40-r9-pa12-lid-frame-fl-qty1-mm.stl</code></div></td><td>7u40-r9-prototype-01-pa12-NOT-APPROVED.zip</td></tr>
<tr><td>R9-PROTOTYPE-01<br />7U40-R9-PA12-LID-FRAME-FR</td><td>PA12蓋枠 / FR × 1</td><td><div>STEP: <code>engineering/r9-prototype-01/out/pa12/lid/7u40-r9-pa12-lid-frame-fr-qty1-mm.step</code></div><div>STL: <code>engineering/r9-prototype-01/out/pa12/lid/7u40-r9-pa12-lid-frame-fr-qty1-mm.stl</code></div></td><td>7u40-r9-prototype-01-pa12-NOT-APPROVED.zip</td></tr>
</tbody>
</table>

<PreviewLink path="/downloads/candidate/7u40-r9-prototype-01-aluminum-NOT-APPROVED.zip">アルミ候補ZIP</PreviewLink> ／ <PreviewLink path="/downloads/candidate/7u40-r9-prototype-01-pa12-NOT-APPROVED.zip">PA12候補ZIP</PreviewLink> ／ <PreviewLink path="/downloads/candidate/7u40-r9-prototype-01-coupons-NOT-APPROVED.zip">試験片ZIP</PreviewLink>。いずれも未承認。

## R6・R8からの変更

| 対象 | 旧版 | R9候補と理由 |
|---|---|---|
| 本体接合 | R6は全46穴が丸穴 | 金具接合36穴を曲げ線に直交する5.5×7.5mm長穴へ。±1.0mmの試験出発値。レール固定10穴は丸穴φ5.5 |
| 本体ガード | R6の金属との公称すきま0、保持未定 | 片側嵌合すきま0.15mmと接着層0.15mmを別パラメータ化。接着性は未確認 |
| 蓋 | R8は表示用メッシュ | 直上へ外すPA12枠とアルミ天板を編集可能なCADへ。蓋と本体のロックなし |
| 試験片 | 現行断面の小片なし | 本体ガードC1、蓋と上端C2、金具と長穴C3を同じ形状関数から出力 |

長穴の調整範囲
座金と長穴の受け面
ガードの片側すきま
ガードの接着層
蓋の差し込み代
蓋と上端のすきま

断面図は生成値の説明で、現物嵌合結果ではない。蓋上昇30mm、パネル2mm＋ノブ25mm、差し込み12mm、片側すきま0.7mmは仮値。パッチケーブルを抜く条件と実モジュールの高さを[測定記録](../verification/measurements.mdx)で確認する。

## 再生成と判定の境界

R9のPython環境で`cd engineering/r9-prototype-01 && uv sync --locked && uv run python build.py`。プレビュー、断面、候補ZIPの再生成後、`out/outputs-manifest.json`のハッシュと`out/validation.json`を確認する。

現行の機械検査は`passed_with_flags`。外径10mmの仮座金は壁側26長穴で受け面条件を満たさない。外径11.5mm以上は検討候補で、部品選定ではない。蓋枠の一部干渉・引抜経路の名目検査を通しているが、全組立の干渉、実金具、接着保持、アルマイト後の嵌合、バンド荷重、天板たわみ、落下・疲労は未検証。[小片手順](../verification/fit-test.mdx)から確認する。

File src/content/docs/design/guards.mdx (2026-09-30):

---
title: "薄型PA12ガード"
description: "本体の強度は金具へ任せ、樹脂は端の被覆と意匠に絞る。"
sidebar_position: 40
---

## 現在の基本断面

標準候補は**厚さ1.2mm、板面を覆う幅5mm、外側角R0.4mm**。1.0mm版も比較用に残す。材料はこれまで試したJLC3DPのPA12-HP Nylon、黒染めを候補にする。

R2の厚さ3mm・被覆幅18mmから、用途に合わせて薄くした。構造用バンパーではなく、アルミ端や継ぎ目を触れにくくし、黒い縁を意匠とする部品である。

## 分割と数量

3U60は４種類12個、7U40/60は６種類16個。長辺を分割し、7Uの上端は４個のL字にした。最長部品は3Uで166.4mm、7Uで168.2mm（1.2mm版）。部品数量と体積は[機種比較](../models/comparison.mdx)から確認する。

STLには１個しか入っていない。注文画面の数量を`qty`へ合わせる。[3Dプリント見積](../manufacturing/print-order.mdx)に機種別の数量表がある。

## R6でまだ形になっていない部分

**R6は金属と公称接触、クリアランス0mm**。接着、はめ込み、端止め等の固定方法を確定していない。このまま印刷して確実に取り付けられるという意味ではない。

薄肉にしたことで、外側のM5頭やナットは隠れない。バッグや机などを傷つけないことを評価する際は、ガードだけでなく金属締結部の突出も確認する。

表示上の外形を維持したまま、必要な公差や接着層を入れると、体積・穴位置・蓋の差し込み隙間が変わる場合がある。変更後は本体ガード、蓋の位置決め部、金属の外形を同じ版で確認する。

## 価格と混同しない

R3の見積画面合計2,264円は、薄肉化が有効だった根拠である。ただし現在のR6３機種やR8蓋の価格ではない。小部品の最低料金・数量・染色などを含め、価格はSTL投入で取り直す。

根拠：[R6ガードmanifest](../resources/files.mdx)、[R3見積画面](../manufacturing/costs.mdx)、<a href="/evidence/r6-original-readme.md">R6保存README</a>。

## R9 7U40の保持候補

上記R6の未確定状態に対し、R9はアルミ端へ被せるスリップフィット溝に**別体の接着材・テープ層**を設けて試す。薄い一体クリップだけを唯一の保持手段にはしない。片側すきま0.15mmと接着層0.15mmは独立した試験値で、実際のPA12-HP黒染め品の寸法・接着性・剥離強度は未確認。1.2mmを主候補、1.0mmを比較用に残す。

C1短片でアルマイト前後の板端との嵌合、接着材の製品名・貼付厚・端面露出・脱落を記録する。FDMの予備確認とPA12-HP黒染めの結果を混ぜない。短片が合っても長いガードの反りと継ぎ目は１台分で別に確認する。[R9断面](./r9-prototype-01.mdx)と[試験記録](../verification/coupon-record.mdx)を参照。

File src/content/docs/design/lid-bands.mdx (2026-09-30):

---
title: "10BOX式の載せ蓋と外周バンド"
description: "可動ロックを持たせず、位置決めと運搬時の保持を分ける。"
sidebar_position: 50
---

## 最終的に採用した方式

天板は黒アルマイトのアルミ１枚。黒PA12枠の**前後に出る段差**を、レールユニットと前後板の隙間へ下ろす。横へずらしたり爪を掛けたりせず、上へ持ち上げるだけで外れる。

普段は載せるだけ。運搬するときは別のバンド２本を巻き、上へ抜けるのを止める。蓋自体にはロック機構を設けない。天板と樹脂枠を組み立てるネジは残すが、開閉時に触らない。

R8の載せ蓋

[10BOX組立ガイド](https://takazudomodular.com/guides/how-to-build-10box/)を、位置決め構造の考え方として参照した。以下の寸法は10BOX実物の複製ではなく、今回のR8プレビューの仮定である。

## プレビューにある寸法

| 要素 | R8の値 | 扱い |
|---|---:|---|
| 本体上端ガードから天板下面まで | 30mm | ノブを避ける設計値。実モジュール確認待ち |
| 前後段差の厚さ | 2mm | 表示形状 |
| 段差の差し込み代 | 12mm | 表示形状 |
| ガード開口との片側隙間 | 0.7mm | 実造形で調整する仮値 |
| 中央の分割継ぎ目 | 0.4mm | 表示形状 |
| バンド幅／厚さ | 20mm／1.4mm | 市販品を特定しない模式値 |
| 仮モジュール | パネル2mm＋ノブ25mm | 全モジュール共通の保証ではない |

天板下面はZ=122.2mm、脚から模式ねじ頭までの蓋付き高さは128.8mm。外側ナット、バンド、バッグ内の余裕は別に確認する。

## 取り除くもの

R7の前後各２本のM3補助固定、ナットチャンネル、本体側の圧縮スペーサー、M3追加長穴は**最終案に不要**。回転カム、スライダー、奥の固定フックも不採用。

ただしR8で変更したのはプレビュー。**R8自体の製作用CADはない。** R9 7U40の未承認候補は後述する。G01の物理的な完了は別に確認する。

## バンドで強く締めればよい、とはしない

薄い天板のたわみがノブへ届くこと、バンドが横へ滑ること、バックルが金属へ擦れることを現物で確認する。周囲の枠へ荷重を渡し、蓋やバンドを持ち手にしない。パッチケーブルは抜いて閉じる条件。

浅い位置決め溝は過去の検討案であり、現行CADに入った仕様ではない。バンドの品番・通し方を先に試してから必要性を判断する。

[R8旧プレビュー](../resources/current-preview.mdx)／[バンド候補と長さ](../manufacturing/bands-suppliers.mdx)／<a href="/evidence/r8-original-readme.md">R8保存README</a>。

## R9で製作候補へ写した内容

R8の載せ蓋をR9 7U40で編集可能なアルミ天板とPA12枠にした。蓋と本体をつなぐM3ロック、後フック、スライダー、回転機構、磁石はない。天板と枠の組立ねじは別用途として残る。上のR8寸法・未出力という記述は旧版の履歴。現在の候補形状は[R9ページ](./r9-prototype-01.mdx)で確認する。

30mm上昇、12mm差し込み、片側0.7mmすきま、パネル2mm＋ノブ25mmは現物で未検証。バンド２本は蓋外周から本体へ回し、保持荷重を枠と側壁へ渡す想定。ただしR9の模式接触では天板だけが接する区間があり、枠の連続支持も天板たわみも未確認。品番、幅、長さ、張力、滑り、バックル当たり、天板下面と実ノブの距離を１台で確認する。[記録欄](../verification/measurements.mdx)へ残す。

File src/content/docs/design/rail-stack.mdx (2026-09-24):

---
title: "実レール・PCB・8mmスペーサー"
description: "幅を決める積層と、締付長の積層を混同しない。"
sidebar_position: 20
---

## レールユニットを独立させる

レールの左右は、外側から`fixer → padder → rail → padder → fixer`。PCBは両方1.6mm。40HPレール長は元STLで204mm、60HPは305mmとしてR6へ記録されている。HPの公称値から再生成したり、60HPを比例縮小したりしていない。

| 要素 | 40HP | 60HP |
|---|---:|---:|
| レール長 | 204mm | 305mm |
| fixer＋padderを加えたユニット外幅 | 210.4mm | 311.4mm |
| 左右8mmスペーサー後のケース内幅 | 226.4mm | 327.4mm |
| 左右1.5mmアルミ後のケース外幅 | 229.4mm | 330.4mm |

計算式は`レール長＋2×(padder1.6＋fixer1.6＋スペーサー8＋アルミ1.5)`。

## ケースへの締付

内側から順に、**M5頭 → fixer1.6 → 内側スペーサー8 → アルミ1.5 → 外側座金1 → ロックナット**。padderは頭を収める層なので、頭下の締付長へは足さない。

頭下から外側座金までの公称積層は**12.1mm**。これはネジ長の購入指定ではない。ナットの掛かり・座金・実ねじ形状を加えて必要な長さを決める。

頭高さはユーザー実測1.3〜1.4mmから1.4mmを採用し、1.6mmのpadderに対して公称0.2mmの高さ余裕。以前の1mm仮定は使用しない。

## 8mmにした理由

fixerの外面と側板内面の間で、レール端の頭1.4mm、金具の占有厚2.2mm、金具固定の頭1.4mmが向かい合う想定では、`8−(1.4＋2.2＋1.4)=3.0mm`が残る。

5mmの場合は同じ仮定で残り0mm。元ケースで干渉を避けて固定点を下げていた経験を踏まえ、上下の２点支持を保てる8mm案を採用した。実際の衝突は頭の直径・位置にも依存するため、この足し算を全体干渉検証の代わりにしない。

## 7U側面

一枚の7U fixerに、各側3U padder２枚と1U padder１枚を取り付ける。ケースとの固定は各3U区画に２点、1U区画に１点、片側５点。3U単列は片側２点。

7U fixerとpadderの配置

7U fixerは約314.754456×60.015381mm。3U fixerより下へ約30mm深い。隣接する元データ間の微差を丸めず保持している。

元形状・コミットと計算記録：[R6の元データ](../resources/engineering.mdx)、[保存済み設計パラメータ](/evidence/r6-design-parameters.json)。

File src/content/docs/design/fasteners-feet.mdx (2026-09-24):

---
title: "締結材・底面・接地"
description: "実測値と模式部品を区別して、突出と接触を確認する。"
sidebar_position: 60
---

## 現物で確認された値

M5平頭の高さは1.4mmとして扱い、fixer/padderの厚さは1.6mm、L字金具の厚さは2mmとする。ネジの商品参照は[ユーザーのM5購入リンク](https://ja.aliexpress.com/item/1005005590438825.html)。頭がpadderに収まることは既存部品で確認済みというユーザー情報を引き継ぐ。

ねじ頭の直径、ナット高さ、軸長の一部はモデル表示用の値。`mountingBoltLengthMm: 20`などがJSONにあっても、購入確定値ではない。頭下積層12.1mmの上に必要なナットの掛かりを確認する。

## 底板だけ締結方向を反転

底面の金属ナットが接地するのを避けるため、底板のネジは**低い頭を外側、座金とナットを内側**へ向ける。対象は3Uで８本、7Uで10本。

ゴム脚はφ10×高さ3mmを４個、外縁から20mm内側へ置く仮配置。公称値では脚の下端から頭まで1.6mm離れるが、実際の脚の圧縮量や貼付状態は未確認。材料・品番を決めて確認する。

## 蓋の組立ネジ

R8にも天板と枠を組み立てるM3が残る。R7では８本、M3×6等を候補にしていたが、R8の製作枠を作り直した後で軸長・ナット座を再確認する。毎回蓋を固定する４本とは用途が違う。

## 追加で見るところ

薄型ガードより外側へ出る頭・ナットが、バッグや周囲を傷つけないか確認する。必要な対策は最終図で決める。金属内部の配線・基板接触、ゴム脚の剥がれ、長穴まわりの座金の支持も検証に含める。

ナット側の詳細寸法はユーザーが今回の設計で重視していないため、ここで特定品を追加指定しない。調達時の部品表で整合を取る。

根拠：<a href="/evidence/r6-original-readme.md">R6保存README</a>、[BOM](../manufacturing/bom.mdx)。

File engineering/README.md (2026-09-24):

# エンジニアリング資産の扱い

- `r6-body/`：提供されたR6 ZIPの全内容を保持した本体CADの参照セット。丸穴、仮穴中心、未確定嵌合に注意。
- `r8-preview/`：提供されたR8 ZIPの全内容。採用した載せ蓋＋バンドの表示専用モデル。
- `release/`：空。製作承認済みファイルだけを将来配置する。
- 旧R7蓋と回転/スライド比較のソースZIPは `../public/downloads/archive/` に保管。

元ファイルのREADMEs・検証ログは当時の記録です。文書整理時にCAD検証や荷重試験を再実行したものではありません。
同梱コードの元の出力パスや依存パッケージはローカルへ合わせて確認してください。過去の生成コードを一括実行して現在の設計を上書きしないでください。

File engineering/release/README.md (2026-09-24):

# 製作承認済みデータ

**現在は空です。承認済みのSTL・STEP・DXFはありません。**

R6は本体の修正起点、R7は不採用ロック蓋、R8は採用方針のプレビューです。
R8載せ蓋の再CAD化、本体の長穴化、嵌合、現物検証後、承認したファイルだけをここへ配置してください。
`project/release-state.json`を同時更新し、版番号・チェックサム・数量・実測結果・承認日を残します。

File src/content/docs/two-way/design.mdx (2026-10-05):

---
title: "構造・保持・開梱"
description: "低い固定トレー、取り外すカラー、捕捉ストラップ、別体スタンドの役割。"
sidebar_position: 10
---

## 圧縮・位置決め・保持

両トレーは独立した金属平板のケースと固定レールです。低い演奏用リムを残し、背の高い位置決め部は取り外すカラーに持たせます。

| 要素 | 役割と限界 |
|---|---|
| カラーの座面 | 周辺部で圧縮を受ける設計仮説。座屈・局部変形は未測定 |
| 重なり・位置決め | 横ずれを抑える。名目の接触と実際の公差は別 |
| 捕捉ストラップ2本 | ガイドを通して座面の離脱を抑える。品番・縫製・張力・保持力は未確定 |
| エッジと金具保護 | 手・脚・トランク内張りへの引っ掛かりを抑える。現物確認が必要 |
| 緩衝材付きトランク | 両トレーを拘束して運ぶ目標。ケースの単独吊り下げ定格ではない |

パッキンはがたつき対策であり、横方向をそれだけで保持しません。バンド摩擦を唯一の荷重経路としません。

## 部品の行き先

| 部品 | 収納 | 演奏 |
|---|---|---|
| 本体・蓋トレー | カラーを間に対向させる | 本体は脚、蓋は別体45°スタンド |
| カラー | 基準は独立4枚、比較案は蝶番でつないだ2組 | 保護袋に入れて空のトランク |
| スタンド | トランク内の独立した袋と仕切り | 側板2枚＋横桟2本。接合・転倒安定性は未検証 |
| ストラップ | ガイドを通る外周2本 | 上側ガイドから抜き、丸めて空のトランク |

下面の必須ポケットはありません。スタンドやカラーをパッチ空間に収納しません。トランク表示で持ち上げたスタンド袋は分解表示であり、寸法予算では内側に計上します。

## 開梱の検討順

1. 電源を切り、安定した台に置く。
2. バックルを開き、上トレーのガイドからバンド端を抜く。
3. 浅いトレーを両手で支え、位置決め部から外して安全な場所に置く。
4. カラーを継ぎ目から横へ開く。ケーブルを支持材にしない。
5. スタンドを組み、浅いトレーを載せる。取り外した部品をトランクへ移す。

実ケーブル長・束の体積・回転時の干渉は未解決です。表示姿勢は静止配置で、連続した開閉機構ではありません。

## 採用しない機構

高い常設壁、外部リンク、大型共通スタンド、スライド壁・スリーブ、持ち上げカセット、必須の下面ポケット、モジュール入り蓋を支える蝶番、フライトケース定格の取っ手・ラッチ、閉じた一体カラーリングは復活させません。

購入蝶番の76 mm全長・15 mm幅・35 mm羽・15 mm穴ピッチはカラー部品をまとめるための入力です。76 mmをパッチ隙間や耐荷重に読み替えません。板厚・ピン・取付・段付きカラーの折り畳み干渉は[現物開発](./verification.mdx)で確認します。

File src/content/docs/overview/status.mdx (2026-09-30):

---
title: "採用仕様とデータ状態"
description: "決めたこと、モデルにあること、未確認のことを分離する。"
sidebar_position: 20
---

**現在の製作候補は7U40の[R9-FITFIX-01](../design/r9-fitfix-01.mdx)（未承認）**。R6本体とR8載せ蓋コンセプトから、長穴・ガード・蓋・小型試験片を同一版にした。現物嵌合、接着保持、座金受け面、運搬荷重は未検証で、製作承認ファイルはない。下記のR6/R8記述は出発版の状態を示す。

## 採用した方針

| 要素 | 採用方針 | 現在のファイル |
|---|---|---|
| 本体 | 独立した平板５枚。凸凹の差し込み接合は使わない | R9 7U40候補あり。他２機種はR6 |
| 金属仕上げ | アルミ、黒アルマイト | 表示・発注候補。加工先未選定 |
| レール | 実STLとfixer/padderの独立ユニット | R6に元形状あり |
| 左右の離隔 | 8mmスペーサー | R6に反映済み |
| 前後の余白 | 全ユニット外形から約8mm | R6に反映済み |
| L字ブラケット | 在庫20×20×16mm、実測厚2mm | R6に模式形状あり。穴中心は仮 |
| ブラケット穴 | 誤差を調整し、締付で保持する | R9 7U40は36長穴・10丸穴。寸法は試験候補 |
| 本体ガード | 黒PA12、薄肉・細幅。標準候補1.2mm／被覆5mm | R9 7U40候補あり。保持・嵌合未検証 |
| 蓋 | 10BOX式の位置決め段差＋単純な載せ蓋 | R9 7U40の未承認CAD候補あり。R8は旧表示のみ |
| 運搬時 | 独立した外周バンド２本 | R8に模式表示。品番未選定 |
| ロック | M3補助固定、回転、スライド、奥フックは不採用 | R7等は履歴へ隔離 |

## 仕様の状態を表す語

**ユーザー確認済み**は本人からの測定・使用情報。**採用方針**は作り方の選択。**名目CAD**は公称寸法での形状。**仮定**は今回の設計・表示のための値。**現物未検証**は試作品で確認が必要な箇所である。

「採用した」だけでは「製作図ができた」にならず、「CAD上で重ならない」だけでは「安全に運べる」にならない。

## 文書サイトの確認状態

2026-09-24時点で、公式scaffolderによる初期化、lockfileに基づく依存導入、実ビルドを確認した。実ビルドは44ページを生成し、41文書ルート・検索項目と47公開資産を確認している。Chrome 146.0.7680.153でも、desktop 1440×900とnarrow 390×844で全41ルート・8カテゴリを開き、検索・テーマ・画像・R8/R6プレビューの主要操作が動作した。詳しい経路、ダウンロードの範囲、スクリーンショットはリポジトリの`project/browser-validation.md`に記録する。これはケースの嵌合、強度、運搬を検証した結果ではない。

## 使用する版

- **R9**：7U40の現行・未承認製作候補。**R8**：採用蓋の旧コンセプト表示。
- **R6**：本体・レール・ガードの設計を進める起点。
- **R7**：不採用のM3ロック蓋。再設計の参考資料に限る。

[版とファイルの対応](../resources/files.mdx)に、コピーしたファイルの位置と用途を示す。`engineering/release/`は現段階では空。承認済みファイルを装って既存ファイルを入れない。

## 発注を止める未確認事項

R9候補の長穴・座金受け面、ガード保持、公差と現物の嵌合、ノブの高さ、ねじ品番、金属仕上げ、運搬検証が残る。[発注前ゲート](../verification/before-order.mdx)には各項目の完了条件を付けた。

根拠：<a href="/evidence/r6-original-readme.md">R6保存README</a>、<a href="/evidence/r8-original-readme.md">R8保存README</a>、会話中のユーザー指定U01–U10（[資料台帳](../resources/sources.mdx)）。

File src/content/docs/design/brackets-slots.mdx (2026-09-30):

---
title: "ブラケットと公差吸収用の長穴"
description: "穴位置を厳密に合わせるのではなく、組立時に調整して締める。"
sidebar_position: 30
---

## ユーザーが意図していること

手持ちの20×20×16mm金具には大きな差が見えなくても、材料・穴位置のずれでパネルが揃わなくなる危険を避けたい。**長穴で位置を調整し、矩形へ整えた後の締付で保持する**のが意図である。

「金具の穴をすべて正確に測らないと設計できない」という方針ではない。実測は必要な調整範囲と干渉を把握するために使い、量産部品の差は設計で吸収する。

旧zudo-block底面パネルの長穴

このSVGはユーザーが提供した旧版の形状。物理単位が埋め込まれていないため、ここから新ケースの長穴寸法をそのまま確定しない。

## 確認済みと仮値

| 項目 | 値・状態 |
|---|---|
| 金具外形 | 20×20×16mm（ユーザー指定） |
| 板厚 | 実測2mm。微小な曲がりを考慮 |
| 占有厚の比較条件 | 2.2mmは設計側の仮定 |
| R6の金具穴中心 | 内面から10mmという仮値 |
| R6のアルミ穴 | φ5.5mmの丸穴 |
| R6の長穴 | 未実装。R9 7U40の5.5×7.5mmは試験候補 |

過去には幅5.5×全長7.5mmの短い長穴を候補として挙げたが、採用済み寸法ではない。旧SVGの長穴寸法に関する過去推定も、新図の承認値としては扱わない。

## 次の作図方針

基準となる位置を保ちつつ、調整したい方向に長穴を置く。全穴を無制限に動く形へするのではなく、板端を揃えて仮締めし、直角・対角を確認して本締めできる組立手順とセットで決める。

座金を使う場合は、長穴周囲の受け面と、内側への厚さ増加を確認する。丸穴をスロットへ変えてもねじ頭や金具の厚さは減らないので、8mm離隔の検討と分離する。

### 発注前の確認結果として残すこと

長穴の幅・全長・向き、基準穴、使用する座金の外径と厚さ、板端からの距離、仮締めで吸収できた実際のずれを記録する。許容トルクはまだ定めていない。

商品リンクは[ブラケットの商品ページ](https://www.alibaba.com/x/18paSt?ck=pdp)。現物の厚さ・形状はユーザーの実測を優先する。今回、商品ページの寸法図や価格を再取得してはいない。

## R9 7U40の試験候補

上記のR6説明に対し、R9では36個の金具接合穴だけを幅5.5×全長7.5mmの長穴へ変更した。中心から長手方向へ±1.0mm動かせる**試験候補**であり、サプライヤーの公差指定や現物合格値ではない。レール固定10穴は独立フレームの位置を保つ丸穴φ5.5とした。[R9断面](./r9-prototype-01.mdx)と`out/aluminum/hole-table.json`を参照する。

| 接合 | 長穴の長手方向 | 基準 |
|---|---|---|
| 底板と前・後板 | 前後方向、曲げ線と直交 | 底板下面と壁板外面 |
| 底板と左・右板 | 左右方向、曲げ線と直交 | 底板下面と壁板外面 |
| 壁板どうしの縦接合 | 各接合の曲げ線と直交する板面方向 | 壁板外面 |

曲げ線**沿い**のずれはこの長穴で吸収できない。金具穴ピッチと板穴ピッチをC3試験片と実組立で確認する。底板を基準に金具と壁板を仮締めし、外形・直角・対角を揃え、調整位置と座金の覆いを見て本締めする。締付順・トルク・緩み止めは実締結材を決めて記録する。

CADでは板端、穴間の肉、ガード接触、名目工具外形を確認した。一方、仮の外径10mm座金は壁側26長穴で必要な受け面を覆えない。外径11.5mm以上を候補に、実座金の内外径・厚み、頭径、工具アクセス、端部での受け面を確認する。

関連：[G02・長穴のゲート](../verification/before-order.mdx)、[アルミ加工条件](../manufacturing/aluminum-order.mdx)。

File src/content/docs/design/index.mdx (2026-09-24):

---
title: "共通設計"
description: "平板、レール、締結、ガード、載せ蓋の役割。"
sidebar_position: 30
---

平板、レール、締結、ガード、載せ蓋の役割。

<CategoryNav category="design" />

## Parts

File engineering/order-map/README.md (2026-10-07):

# Ordered fit-test map

English supplier-facing companion to the R9-FITFIX-01 preview for order W2026100405546498. The self-contained published entry is `/previews/r9-order-map.html`; select a design with `#part=c2-01-frame` (or another exact order-plan part ID).

`build.mjs` reads the existing saved scene and order plan, embeds the existing Three.js vendor bundle, and emits the standalone page plus provenance. It never regenerates CAD. `app.js` uses original mesh coordinates; raised-lid and separated-detail offsets affect presentation only. C1 is a representative shared cross-section; C2/C4/C5 use the source-confirmed clip locations in `fitfix/coupons.py`. Counts come from the PA12 order manifest: 13 designs / 15 pieces. Aluminum meshes are mating references, not part of that print quantity.

```sh
node engineering/order-map/build.mjs
node engineering/order-map/build.mjs --check
node --test tests/order-map.test.mjs
```

For browser checks, serve `public/` over HTTP, provide Playwright via `PLAYWRIGHT_MODULE` if not installed in the repository, then run `node engineering/order-map/browser.cjs`. `PREVIEW_ORIGIN` defaults to `http://127.0.0.1:8765`; `SCREENSHOT_DIR` chooses evidence output. Chrome is selected by channel. Tests cover 1440/390 widths, all IDs, markers, selection links, assembly modes, visibility controls and the original preview. Screenshots require visual inspection in addition to assertions. The order map requires WebGL; failure points users to the unchanged normal preview's Canvas fallback.

The link in the normal preview is maintained in `engineering/r9-fitfix-01/fitfix/preview.py`. Its saved HTML and the existing fitfix manifests were updated without modifying their embedded mesh payload. `node scripts/sync-fitfix.mjs --check` verifies those established manifests.

No manufacturing orientation, new tolerance, production release or model revision is implied by this view.

## Anodizing revision review (issue 118)

The material selector separates the **13 aluminum plates** from the unchanged **13 PA12 designs / 15 pieces**. `#part=c5-01-left&revision=revised` opens an individual revised plate; `revision=original` opens its original geometry. Existing PA12 `#part=c2-01-frame` links remain valid. The default aluminum geometry is R9-ANODIZING-01; the same selection controls metal mating references in the PA12 detail view. C2 comparison frames reuse the one ordered C2-01 metal pair.

The aluminum detail is one actual manufacturing plate, with no explanatory assembly offsets. C3 STEP/STL exports are flat XY even for wall coupons; they are deliberately not placed at their case marker. The left panel is unchanged full-case context. No hanging holes are applied to full-size case plates.

`aluminum_meshes.py` reads the original/revised STL vertices without changing them. Original C3 has no STL, so its original STEP is tessellated with the locked CAD toolchain. Each mesh records the source SHA-256 and path. Rebuild and verify with:

```sh
uv run --locked --project engineering/r9-prototype-01 python engineering/order-map/aluminum_meshes.py
node engineering/order-map/build.mjs
node --test tests/order-map.test.mjs
uv run --locked --project engineering/r9-prototype-01 python engineering/order-map/aluminum_meshes.py --check
```

Browser checks raycast the displayed mesh through the manifest hole center in all 13 plates, checking an open revised hole, solid original sheet, and nearby retained material. They also exercise both view widths, both revisions, direct links, refresh, hash changes and the original engineering preview. `CHROME_PATH` optionally selects an installed Chromium executable. Use the machine's heavy/browser guards when required.

Final issue-118 verification: `verification/anodizing-browser.json` records the passing 1440/390 run, with C5 screenshots at both widths. A prior mobile selection timeout did not reproduce in a focused all-13 run or the complete final suite (295 seconds, no page errors); no selector workaround or weakened assertion was needed. The browser script now logs each aluminum selection, records failure messages, and accepts `BROWSER_WIDTHS=390` for focused diagnosis. Bound external runs with `timeout 360` (or the platform equivalent).

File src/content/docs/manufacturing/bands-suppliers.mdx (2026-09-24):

---
title: "調達先と運搬バンドの候補"
description: "会話で挙げた候補を残す。品番・価格の再確認は注文前に行う。"
sidebar_position: 50
---

## アルミ・樹脂・金具

| 対象 | 会話で挙げた調達先 | 扱い |
|---|---|---|
| アルミ板の切断・穴・黒アルマイト | [JLCCNC](https://jlccnc.com/sheet-metal-fabrication) | A5052での一括依頼候補。実見積未取得 |
| 国内の黒アルマイト板 | [タカチB2F](https://www.takachi-el.co.jp/products/B2F) | A1100Pの比較候補。カスタム穴は別 |
| 切板の比較 | [横山テクノ](https://www.yokoyama-techno.net/detail/44.html) | 素材と切断の参考。完成板原価ではない |
| PA12黒部品 | [JLC3DP PA12-HP](https://jlc3dp.com/help/article/pa12-hp-nylon) | 本体ガードはSTL投入で比較 |
| L字金具 | [Alibabaのユーザー購入品](https://www.alibaba.com/x/18paSt?ck=pdp) | 在庫20×20×16mmを使用 |
| M5低頭 | [AliExpressのユーザー購入品](https://ja.aliexpress.com/item/1005005590438825.html) | 高さ1.4mmをユーザー実測 |

## バンド候補の記録

これらは**過去の調査で挙げた候補**。今回、在庫・価格・製品仕様は再取得していない。最終品番を選んだわけではない。

| 候補 | 過去に記録した条件 | 位置づけ |
|---|---|---|
| [FIXPLUS 86cm](https://fukaya-nagoya.co.jp/product/fixplus-strap-86cm/) | 黒、幅23mm、税込2,090円/本と報告 | ゴム系の外観を比較する候補 |
| [Voilé 32インチ Nylon Buckle](https://www.voile.com/voile-straps-32-inch-nylon-buckle.html) | 使用周長14〜75.3cm、11USD/本と報告 | ポリウレタン＋ナイロンバックルの候補 |
| [JACK ボア結束ベルト](https://store.shopping.yahoo.co.jp/handcraft/jack-bur-belt-l1-20-1500.html) | 幅20mm×1.5m、10本2,762円と報告 | 面ファスナーの低価格同梱候補 |
| [ALMの純正ストラップ](https://busycircuits.com/products/alm-csstp) | 700×50mmの面ファスナーベルトと報告 | 蓋＋ストラップ方式の製品例 |

過去価格を現時点の購入可能価格として表示しない。ALMは方式の参考であり、今回のケースへ長さが適合するという指定ではない。

## 長さを確認する

R8モデルの閉じた高さ128.8mmと短辺から得た幾何学的な一周長さは次のとおり。

| モデル | 一周の概算 | R8での巻き方向 |
|---|---:|---|
| 3U60 | 570.4mm | 奥行Dを一周 |
| 7U40 | 721.2mm | 幅Wを一周 |
| 7U60 | 923.2mm | 幅Wを一周 |

**全長ではなく使用可能な周長で選ぶ。** バックルの折返し、面ファスナーの重なり、頭/ナットの突出、角部、締付の変形は上の値に入っていない。7U60を全長86cm１本で回すことは、この計算の段階でも足りない。

両手を離してもバンドが横へ落ちないか、天板がノブへ沈まないか、バックルがケースへ擦れないかを実物で見る。２本を平行に巻く方針だが、位置決め溝は未採用・未設計。バンドを持ち手には使わない。

根拠：[R8パラメータ](/evidence/r8-preview-parameters.json)、[載せ蓋の設計](../design/lid-bands.mdx)。

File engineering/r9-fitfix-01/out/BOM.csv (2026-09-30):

variant | part | material | per_set_quantity | order_quantity | volume_mm3 | stl | step | dxf
shared | body-bottom | A5052 t1.5 black anodized candidate | 1 | 1 | 114408.02558335834 | aluminum/body/7u40-r9f-body-bottom-qty1-mm.stl | aluminum/body/7u40-r9f-body-bottom-qty1-mm.step | aluminum/body/7u40-r9f-body-bottom-qty1-mm.dxf
shared | body-front_back | A5052 t1.5 black anodized candidate | 2 | 2 | 30081.375350015045 | aluminum/body/7u40-r9f-body-front_back-qty2-mm.stl | aluminum/body/7u40-r9f-body-front_back-qty2-mm.step | aluminum/body/7u40-r9f-body-front_back-qty2-mm.dxf
shared | body-left_right | A5052 t1.5 black anodized candidate | 2 | 2 | 44296.35070003007 | aluminum/body/7u40-r9f-body-left_right-qty2-mm.stl | aluminum/body/7u40-r9f-body-left_right-qty2-mm.step | aluminum/body/7u40-r9f-body-left_right-qty2-mm.dxf
t1p2 | t1p2-top-a | PA12-HP black candidate | 2 | 2 | 4857.027761172996 | pa12/t1p2/guards/7u40-r9f-t1p2-top-a-qty2-mm.stl | pa12/t1p2/guards/7u40-r9f-t1p2-top-a-qty2-mm.step
t1p2 | t1p2-top-b | PA12-HP black candidate | 2 | 2 | 4857.027761443578 | pa12/t1p2/guards/7u40-r9f-t1p2-top-b-qty2-mm.stl | pa12/t1p2/guards/7u40-r9f-t1p2-top-b-qty2-mm.step
t1p2 | t1p2-lower-width-half | PA12-HP black candidate | 4 | 4 | 1591.4352408157733 | pa12/t1p2/guards/7u40-r9f-t1p2-lower-width-half-qty4-mm.stl | pa12/t1p2/guards/7u40-r9f-t1p2-lower-width-half-qty4-mm.step
t1p2 | t1p2-lower-depth-a | PA12-HP black candidate | 2 | 2 | 2223.1546885422013 | pa12/t1p2/guards/7u40-r9f-t1p2-lower-depth-a-qty2-mm.stl | pa12/t1p2/guards/7u40-r9f-t1p2-lower-depth-a-qty2-mm.step
t1p2 | t1p2-lower-depth-b | PA12-HP black candidate | 2 | 2 | 2223.1546885422013 | pa12/t1p2/guards/7u40-r9f-t1p2-lower-depth-b-qty2-mm.stl | pa12/t1p2/guards/7u40-r9f-t1p2-lower-depth-b-qty2-mm.step
t1p2 | t1p2-vertical-corner | PA12-HP black candidate | 4 | 4 | 1137.1159283445545 | pa12/t1p2/guards/7u40-r9f-t1p2-vertical-corner-qty4-mm.stl | pa12/t1p2/guards/7u40-r9f-t1p2-vertical-corner-qty4-mm.step
t1p2 | lid-frame-fr | PA12-HP black candidate | 1 | 1 | 21094.55187062771 | pa12/t1p2/lid/7u40-r9f-lid-frame-fr-qty1-mm.stl | pa12/t1p2/lid/7u40-r9f-lid-frame-fr-qty1-mm.step
t1p2 | lid-frame-fl | PA12-HP black candidate | 1 | 1 | 21094.55187062771 | pa12/t1p2/lid/7u40-r9f-lid-frame-fl-qty1-mm.stl | pa12/t1p2/lid/7u40-r9f-lid-frame-fl-qty1-mm.step
t1p2 | lid-frame-bl | PA12-HP black candidate | 1 | 1 | 21094.551870627693 | pa12/t1p2/lid/7u40-r9f-lid-frame-bl-qty1-mm.stl | pa12/t1p2/lid/7u40-r9f-lid-frame-bl-qty1-mm.step
t1p2 | lid-frame-br | PA12-HP black candidate | 1 | 1 | 21094.55187062771 | pa12/t1p2/lid/7u40-r9f-lid-frame-br-qty1-mm.stl | pa12/t1p2/lid/7u40-r9f-lid-frame-br-qty1-mm.step
t1p2 | lid-plate | A5052 t1.5 black anodized candidate | 1 | 1 | 113796.90106759699 | aluminum/t1p2/7u40-r9f-lid-plate-qty1-mm.stl | aluminum/t1p2/7u40-r9f-lid-plate-qty1-mm.step | aluminum/t1p2/7u40-r9f-lid-plate-qty1-mm.dxf
t1p0 | t1p0-top-a | PA12-HP black candidate | 2 | 2 | 3934.031495689728 | pa12/t1p0/guards/7u40-r9f-t1p0-top-a-qty2-mm.stl | pa12/t1p0/guards/7u40-r9f-t1p0-top-a-qty2-mm.step
t1p0 | t1p0-top-b | PA12-HP black candidate | 2 | 2 | 3934.031495959509 | pa12/t1p0/guards/7u40-r9f-t1p0-top-b-qty2-mm.stl | pa12/t1p0/guards/7u40-r9f-t1p0-top-b-qty2-mm.step
t1p0 | t1p0-lower-width-half | PA12-HP black candidate | 4 | 4 | 1300.1114767316772 | pa12/t1p0/guards/7u40-r9f-t1p0-lower-width-half-qty4-mm.stl | pa12/t1p0/guards/7u40-r9f-t1p0-lower-width-half-qty4-mm.step
t1p0 | t1p0-lower-depth-a | PA12-HP black candidate | 2 | 2 | 1819.40468854219 | pa12/t1p0/guards/7u40-r9f-t1p0-lower-depth-a-qty2-mm.stl | pa12/t1p0/guards/7u40-r9f-t1p0-lower-depth-a-qty2-mm.step
t1p0 | t1p0-lower-depth-b | PA12-HP black candidate | 2 | 2 | 1819.40468854219 | pa12/t1p0/guards/7u40-r9f-t1p0-lower-depth-b-qty2-mm.stl | pa12/t1p0/guards/7u40-r9f-t1p0-lower-depth-b-qty2-mm.step
t1p0 | t1p0-vertical-corner | PA12-HP black candidate | 4 | 4 | 931.0359283445591 | pa12/t1p0/guards/7u40-r9f-t1p0-vertical-corner-qty4-mm.stl | pa12/t1p0/guards/7u40-r9f-t1p0-vertical-corner-qty4-mm.step
t1p0 | lid-frame-fr | PA12-HP black candidate | 1 | 1 | 20968.20813611207 | pa12/t1p0/lid/7u40-r9f-lid-frame-fr-qty1-mm.stl | pa12/t1p0/lid/7u40-r9f-lid-frame-fr-qty1-mm.step
t1p0 | lid-frame-fl | PA12-HP black candidate | 1 | 1 | 20968.20813611207 | pa12/t1p0/lid/7u40-r9f-lid-frame-fl-qty1-mm.stl | pa12/t1p0/lid/7u40-r9f-lid-frame-fl-qty1-mm.step
t1p0 | lid-frame-bl | PA12-HP black candidate | 1 | 1 | 20968.208136112084 | pa12/t1p0/lid/7u40-r9f-lid-frame-bl-qty1-mm.stl | pa12/t1p0/lid/7u40-r9f-lid-frame-bl-qty1-mm.step
t1p0 | lid-frame-br | PA12-HP black candidate | 1 | 1 | 20968.20813611207 | pa12/t1p0/lid/7u40-r9f-lid-frame-br-qty1-mm.stl | pa12/t1p0/lid/7u40-r9f-lid-frame-br-qty1-mm.step
t1p0 | lid-plate | A5052 t1.5 black anodized candidate | 1 | 1 | 113460.54106759699 | aluminum/t1p0/7u40-r9f-lid-plate-qty1-mm.stl | aluminum/t1p0/7u40-r9f-lid-plate-qty1-mm.step | aluminum/t1p0/7u40-r9f-lid-plate-qty1-mm.dxf
coupon | c1-01-guard | PA12-HP black candidate | 1 | 1 | 696.5465482457441 | coupons/c1-01/7u40-r9f-c1-01-guard-qty1-mm.stl | coupons/c1-01/7u40-r9f-c1-01-guard-qty1-mm.step
coupon | c1-02-guard | PA12-HP black candidate | 1 | 1 | 691.8905482457435 | coupons/c1-02/7u40-r9f-c1-02-guard-qty1-mm.stl | coupons/c1-02/7u40-r9f-c1-02-guard-qty1-mm.step
coupon | c1-03-guard | PA12-HP black candidate | 1 | 1 | 706.2905482457437 | coupons/c1-03/7u40-r9f-c1-03-guard-qty1-mm.stl | coupons/c1-03/7u40-r9f-c1-03-guard-qty1-mm.step
coupon | c1-04-guard | PA12-HP black candidate | 1 | 1 | 682.1945482457435 | coupons/c1-04/7u40-r9f-c1-04-guard-qty1-mm.stl | coupons/c1-04/7u40-r9f-c1-04-guard-qty1-mm.step
coupon | c1-05-guard | PA12-HP black candidate | 1 | 1 | 564.6905482457436 | coupons/c1-05/7u40-r9f-c1-05-guard-qty1-mm.stl | coupons/c1-05/7u40-r9f-c1-05-guard-qty1-mm.step
coupon | c1-06-guard | PA12-HP black candidate | 2 | 2 | 345.083858196336 | coupons/c1-06/7u40-r9f-c1-06-guard-qty2-mm.stl | coupons/c1-06/7u40-r9f-c1-06-guard-qty2-mm.step
coupon | c1-07-guard | PA12-HP black candidate | 2 | 2 | 349.1852741228718 | coupons/c1-07/7u40-r9f-c1-07-guard-qty2-mm.stl | coupons/c1-07/7u40-r9f-c1-07-guard-qty2-mm.step
coupon | c1-metal-edge | A5052 t1.5 candidate | 1 | 1 | 1199.9999999999998 | coupons/c1-metal/7u40-r9f-c1-metal-edge-qty1-mm.stl | coupons/c1-metal/7u40-r9f-c1-metal-edge-qty1-mm.step | coupons/c1-metal/7u40-r9f-c1-metal-edge-qty1-mm.dxf
coupon | c2-01-wall | A5052 t1.5 candidate | 1 | 1 | 1395.0 | coupons/c2-01/7u40-r9f-c2-01-wall-qty1-mm.stl | coupons/c2-01/7u40-r9f-c2-01-wall-qty1-mm.step | coupons/c2-01/7u40-r9f-c2-01-wall-qty1-mm.dxf
coupon | c2-01-guard | PA12-HP black candidate | 1 | 1 | 520.9699111843069 | coupons/c2-01/7u40-r9f-c2-01-guard-qty1-mm.stl | coupons/c2-01/7u40-r9f-c2-01-guard-qty1-mm.step
coupon | c2-01-frame | PA12-HP black candidate | 1 | 1 | 3218.6606197286665 | coupons/c2-01/7u40-r9f-c2-01-frame-qty1-mm.stl | coupons/c2-01/7u40-r9f-c2-01-frame-qty1-mm.step
coupon | c2-01-plate | A5052 t1.5 candidate | 1 | 1 | 1174.3811958466883 | coupons/c2-01/7u40-r9f-c2-01-plate-qty1-mm.stl | coupons/c2-01/7u40-r9f-c2-01-plate-qty1-mm.step | coupons/c2-01/7u40-r9f-c2-01-plate-qty1-mm.dxf
coupon | c2-02-wall | A5052 t1.5 candidate | 1 | 0 | 1395.0 | coupons/c2-02/7u40-r9f-c2-02-wall-qty1-mm.stl | coupons/c2-02/7u40-r9f-c2-02-wall-qty1-mm.step | coupons/c2-02/7u40-r9f-c2-02-wall-qty1-mm.dxf
coupon | c2-02-guard | PA12-HP black candidate | 1 | 0 | 520.9699111843069 | coupons/c2-02/7u40-r9f-c2-02-guard-qty1-mm.stl | coupons/c2-02/7u40-r9f-c2-02-guard-qty1-mm.step
coupon | c2-02-frame | PA12-HP black candidate | 1 | 1 | 3203.804619728664 | coupons/c2-02/7u40-r9f-c2-02-frame-qty1-mm.stl | coupons/c2-02/7u40-r9f-c2-02-frame-qty1-mm.step
coupon | c2-02-plate | A5052 t1.5 candidate | 1 | 0 | 1174.3811958466883 | coupons/c2-02/7u40-r9f-c2-02-plate-qty1-mm.stl | coupons/c2-02/7u40-r9f-c2-02-plate-qty1-mm.step | coupons/c2-02/7u40-r9f-c2-02-plate-qty1-mm.dxf
coupon | c2-03-wall | A5052 t1.5 candidate | 1 | 0 | 1395.0 | coupons/c2-03/7u40-r9f-c2-03-wall-qty1-mm.stl | coupons/c2-03/7u40-r9f-c2-03-wall-qty1-mm.step | coupons/c2-03/7u40-r9f-c2-03-wall-qty1-mm.dxf
coupon | c2-03-guard | PA12-HP black candidate | 1 | 0 | 520.9699111843069 | coupons/c2-03/7u40-r9f-c2-03-guard-qty1-mm.stl | coupons/c2-03/7u40-r9f-c2-03-guard-qty1-mm.step
coupon | c2-03-frame | PA12-HP black candidate | 1 | 1 | 3233.804619728665 | coupons/c2-03/7u40-r9f-c2-03-frame-qty1-mm.stl | coupons/c2-03/7u40-r9f-c2-03-frame-qty1-mm.step
coupon | c2-03-plate | A5052 t1.5 candidate | 1 | 0 | 1174.3811958466883 | coupons/c2-03/7u40-r9f-c2-03-plate-qty1-mm.stl | coupons/c2-03/7u40-r9f-c2-03-plate-qty1-mm.step | coupons/c2-03/7u40-r9f-c2-03-plate-qty1-mm.dxf
coupon | c4-01-floor | A5052 t1.5 candidate | 1 | 1 | 900.0 | coupons/c4-01/7u40-r9f-c4-01-floor-qty1-mm.stl | coupons/c4-01/7u40-r9f-c4-01-floor-qty1-mm.step | coupons/c4-01/7u40-r9f-c4-01-floor-qty1-mm.dxf
coupon | c4-01-wall | A5052 t1.5 candidate | 1 | 1 | 832.5 | coupons/c4-01/7u40-r9f-c4-01-wall-qty1-mm.stl | coupons/c4-01/7u40-r9f-c4-01-wall-qty1-mm.step | coupons/c4-01/7u40-r9f-c4-01-wall-qty1-mm.dxf
coupon | c4-01-lower-guard | PA12-HP black candidate | 1 | 1 | 405.93791118430977 | coupons/c4-01/7u40-r9f-c4-01-lower-guard-qty1-mm.stl | coupons/c4-01/7u40-r9f-c4-01-lower-guard-qty1-mm.step
coupon | c5-01-front | A5052 t1.5 candidate | 1 | 1 | 315.0 | coupons/c5-01/7u40-r9f-c5-01-front-qty1-mm.stl | coupons/c5-01/7u40-r9f-c5-01-front-qty1-mm.step | coupons/c5-01/7u40-r9f-c5-01-front-qty1-mm.dxf
coupon | c5-01-left | A5052 t1.5 candidate | 1 | 1 | 359.99999999999994 | coupons/c5-01/7u40-r9f-c5-01-left-qty1-mm.stl | coupons/c5-01/7u40-r9f-c5-01-left-qty1-mm.step | coupons/c5-01/7u40-r9f-c5-01-left-qty1-mm.dxf
coupon | c5-01-upper-guard | PA12-HP black candidate | 1 | 1 | 392.64305577192147 | coupons/c5-01/7u40-r9f-c5-01-upper-guard-qty1-mm.stl | coupons/c5-01/7u40-r9f-c5-01-upper-guard-qty1-mm.step

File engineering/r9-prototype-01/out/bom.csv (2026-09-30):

section | id | name | quantity | unit | quantityMeaning | dimensionsMm | thicknessMm | measuredThicknessMm | coverMm | widthMm | modeledThicknessMm | estimatedLoopLengthMm | material | status | unitPriceJpy | lineTotalJpy | incrementalCashJpy | productCostJpy | costTreatment | fileCount | notes
aluminum | 7U40-R9-AL-BOTTOM | 底板 | 1 | piece |  | [229.4,334.0,1.5] |  |  |  |  |  |  | A5052 t1.5 mm; black anodizing (candidate) | candidate; not approved for manufacture |  |  |  |  | unquoted |  | R6-body-derived R9 candidate geometry; verify material, finish, tolerances, and flat pattern with the fabricator.
aluminum | 7U40-R9-AL-FRONT-BACK | 前板・後板 | 2 | piece |  | [226.4,89.5,1.5] |  |  |  |  |  |  | A5052 t1.5 mm; black anodizing (candidate) | candidate; not approved for manufacture |  |  |  |  | unquoted |  | R6-body-derived R9 candidate geometry; verify material, finish, tolerances, and flat pattern with the fabricator.
aluminum | 7U40-R9-AL-LEFT-RIGHT | 左右板 | 2 | piece |  | [334.0,89.5,1.5] |  |  |  |  |  |  | A5052 t1.5 mm; black anodizing (candidate) | candidate; not approved for manufacture |  |  |  |  | unquoted |  | R6-body-derived R9 candidate geometry; verify material, finish, tolerances, and flat pattern with the fabricator.
aluminum | 7U40-R9-LID-PLATE | 蓋板 | 1 | piece |  | [227.6,332.2,1.5] |  |  |  |  |  |  | A5052 t1.5 mm; black anodizing (candidate) | R8-derived candidate; dimensions and assembly fit remain provisional |  |  |  |  | unquoted |  | Aluminum lid sheet paired with the separate PA12 locating frame; not a locking lid.
pa12_guard_main | 7U40-R9-PA12-GUARD-T1P2-TOP-A | 上端コーナーガード A | 2 | piece |  | [115.6500015258789,167.9499969482422,6.1999969482421875] | 1.2 |  | 5 |  |  |  | PA12-HP dyed black candidate | main candidate |  |  |  |  | unquoted |  | Protective cover only; not a structural joint. Retention, adhesion, material tolerance, and fit are unvalidated.
pa12_guard_main | 7U40-R9-PA12-GUARD-T1P2-TOP-B | 上端コーナーガード B | 2 | piece |  | [115.6500015258789,167.9499969482422,6.1999969482421875] | 1.2 |  | 5 |  |  |  | PA12-HP dyed black candidate | main candidate |  |  |  |  | unquoted |  | Protective cover only; not a structural joint. Retention, adhesion, material tolerance, and fit are unvalidated.
pa12_guard_main | 7U40-R9-PA12-GUARD-T1P2-LOWER-WIDTH-HALF | 前後下辺ガード・半分 | 4 | piece |  | [115.6500015258789,6.1999969482421875,6.200000047683716] | 1.2 |  | 5 |  |  |  | PA12-HP dyed black candidate | main candidate |  |  |  |  | unquoted |  | Protective cover only; not a structural joint. Retention, adhesion, material tolerance, and fit are unvalidated.
pa12_guard_main | 7U40-R9-PA12-GUARD-T1P2-LOWER-DEPTH-A | 左右下辺ガード・半分 A | 2 | piece |  | [3.7000045776367188,161.75,6.200000047683716] | 1.2 |  | 5 |  |  |  | PA12-HP dyed black candidate | main candidate |  |  |  |  | unquoted |  | Protective cover only; not a structural joint. Retention, adhesion, material tolerance, and fit are unvalidated.
pa12_guard_main | 7U40-R9-PA12-GUARD-T1P2-LOWER-DEPTH-B | 左右下辺ガード・半分 B | 2 | piece |  | [3.7000045776367188,161.75,6.200000047683716] | 1.2 |  | 5 |  |  |  | PA12-HP dyed black candidate | main candidate |  |  |  |  | unquoted |  | Protective cover only; not a structural joint. Retention, adhesion, material tolerance, and fit are unvalidated.
pa12_guard_main | 7U40-R9-PA12-GUARD-T1P2-VERTICAL-CORNER | 縦辺コーナーガード | 4 | piece |  | [6.200004577636719,6.1999969482421875,81.0] | 1.2 |  | 5 |  |  |  | PA12-HP dyed black candidate | main candidate |  |  |  |  | unquoted |  | Protective cover only; not a structural joint. Retention, adhesion, material tolerance, and fit are unvalidated.
pa12_guard_comparison | 7U40-R9-PA12-GUARD-T1P0-TOP-A | 上端コーナーガード A | 2 | piece |  | [115.44999694824219,167.75,6.0] | 1.0 |  | 5 |  |  |  | PA12-HP dyed black candidate | comparison only; separate from the main candidate |  |  |  |  | unquoted |  | Protective cover only; not a structural joint. Retention, adhesion, material tolerance, and fit are unvalidated.
pa12_guard_comparison | 7U40-R9-PA12-GUARD-T1P0-TOP-B | 上端コーナーガード B | 2 | piece |  | [115.44999694824219,167.75,6.0] | 1.0 |  | 5 |  |  |  | PA12-HP dyed black candidate | comparison only; separate from the main candidate |  |  |  |  | unquoted |  | Protective cover only; not a structural joint. Retention, adhesion, material tolerance, and fit are unvalidated.
pa12_guard_comparison | 7U40-R9-PA12-GUARD-T1P0-LOWER-WIDTH-HALF | 前後下辺ガード・半分 | 4 | piece |  | [115.44999694824219,6.0,6.0] | 1.0 |  | 5 |  |  |  | PA12-HP dyed black candidate | comparison only; separate from the main candidate |  |  |  |  | unquoted |  | Protective cover only; not a structural joint. Retention, adhesion, material tolerance, and fit are unvalidated.
pa12_guard_comparison | 7U40-R9-PA12-GUARD-T1P0-LOWER-DEPTH-A | 左右下辺ガード・半分 A | 2 | piece |  | [3.5,161.75,6.0] | 1.0 |  | 5 |  |  |  | PA12-HP dyed black candidate | comparison only; separate from the main candidate |  |  |  |  | unquoted |  | Protective cover only; not a structural joint. Retention, adhesion, material tolerance, and fit are unvalidated.
pa12_guard_comparison | 7U40-R9-PA12-GUARD-T1P0-LOWER-DEPTH-B | 左右下辺ガード・半分 B | 2 | piece |  | [3.5,161.75,6.0] | 1.0 |  | 5 |  |  |  | PA12-HP dyed black candidate | comparison only; separate from the main candidate |  |  |  |  | unquoted |  | Protective cover only; not a structural joint. Retention, adhesion, material tolerance, and fit are unvalidated.
pa12_guard_comparison | 7U40-R9-PA12-GUARD-T1P0-VERTICAL-CORNER | 縦辺コーナーガード | 4 | piece |  | [6.0,6.0,81.0] | 1.0 |  | 5 |  |  |  | PA12-HP dyed black candidate | comparison only; separate from the main candidate |  |  |  |  | unquoted |  | Protective cover only; not a structural joint. Retention, adhesion, material tolerance, and fit are unvalidated.
pa12_lid_frame | 7U40-R9-PA12-LID-FRAME-FR | 蓋フレーム FR | 1 | piece |  |  |  |  |  |  |  |  | PA12-HP; lid-frame finish not confirmed | candidate; physical fit not validated |  |  |  |  | unquoted |  | Four separate locating-corner parts. Assembly screws/nuts are listed below.
pa12_lid_frame | 7U40-R9-PA12-LID-FRAME-FL | 蓋フレーム FL | 1 | piece |  |  |  |  |  |  |  |  | PA12-HP; lid-frame finish not confirmed | candidate; physical fit not validated |  |  |  |  | unquoted |  | Four separate locating-corner parts. Assembly screws/nuts are listed below.
pa12_lid_frame | 7U40-R9-PA12-LID-FRAME-BL | 蓋フレーム BL | 1 | piece |  |  |  |  |  |  |  |  | PA12-HP; lid-frame finish not confirmed | candidate; physical fit not validated |  |  |  |  | unquoted |  | Four separate locating-corner parts. Assembly screws/nuts are listed below.
pa12_lid_frame | 7U40-R9-PA12-LID-FRAME-BR | 蓋フレーム BR | 1 | piece |  |  |  |  |  |  |  |  | PA12-HP; lid-frame finish not confirmed | candidate; physical fit not validated |  |  |  |  | unquoted |  | Four separate locating-corner parts. Assembly screws/nuts are listed below.
hardware | existing-stock-bracket-20x20x16 | 在庫L字ブラケット | 18 | piece |  | [20,20,16] |  | 2 |  |  |  |  | Existing metal stock; alloy unconfirmed | existing stock; thickness 2.0 mm measured |  |  | 0 |  | existing stock; no incremental cash; product cost unknown |  | 2.2 mm is a separate CAD allowance, not the measured thickness.
hardware | m5-case-mount-bolt | M5 本体固定ねじ | 10 | piece |  |  |  |  |  |  |  |  | Unselected; provisional fastener envelope | provisional; length and head diameter unconfirmed; 1.4 mm head height confirmed |  |  |  |  | unquoted |  | M5 flat-head height 1.4 mm is user-confirmed; seated below the padder.
hardware | m5-panel-joint-bolt | M5 パネル接合ねじ | 36 | piece |  |  |  |  |  |  |  |  | Unselected; provisional fastener envelope | provisional; exact head diameter and length unconfirmed |  |  |  |  | unquoted |  | Head height 1.4 mm is user-confirmed; seated below the padder.
hardware | m5-rail-end-bolt | M5 レール端ねじ | 12 | piece |  |  |  |  |  |  |  |  | Unselected; provisional fastener envelope | provisional; length unconfirmed |  |  |  |  | unquoted |  | M5 flat-head height 1.4 mm is user-confirmed, seated below the padder; exact shank length remains provisional. Rail unit manufacturing cost is excluded by request.
hardware | m5-washer-1mm | M5 ワッシャー | 46 | piece |  |  | 1 |  |  |  |  |  | Unselected; OD/ID provisional | provisional; 1.0 mm thickness user-confirmed |  |  |  |  | unquoted |  | Combined count: 10 outer washers and 36 panel-joint washers. Slot bearing coverage is not resolved.
hardware | m5-nut | M5 ナット | 46 | piece |  |  |  |  |  |  |  |  | Unselected; display-envelope dimensions provisional | provisional; nut type and dimensions unconfirmed |  |  |  |  | unquoted |  | Envelope count comprises 10 case-mount and 36 panel-joint nuts.
hardware | inner-spacer-8mm | 内側スペーサー | 10 | piece |  |  | 8 |  |  |  |  |  | Unselected; OD/ID provisional | provisional; 8 mm thickness user-confirmed |  |  |  |  | unquoted |  | Product dimensions and material are not selected.
hardware | m3-lid-frame-screw | M3 蓋板・フレーム組立ねじ | 8 | piece |  |  |  |  |  |  |  |  | Unselected; provisional hardware | provisional; length, head, and tool access unconfirmed |  |  |  |  | unquoted |  | Eight plate-to-frame bores; these are lid-assembly screws, not lid-to-body locks.
hardware | m3-lid-frame-nut | M3 蓋板・フレーム組立ナット | 8 | piece |  |  |  |  |  |  |  |  | Unselected; provisional hardware | provisional; exact nut type and tool access unconfirmed |  |  |  |  | unquoted |  | Eight plate-to-frame bores; these are not lid-to-body locks.
hardware | rubber-foot | ゴム足 | 4 | piece |  |  |  |  |  |  |  |  | Black rubber candidate; product unselected | provisional; dimensions and attachment method unconfirmed |  |  |  |  | unquoted |  | Display envelope only.
hardware | external-transport-strap | 着脱式外周バンド | 2 | piece |  |  |  |  |  | 20.0 | 1.4 | 721.2 | Generic external strap; material and product unselected | schematic estimate; not load-tested |  |  |  |  | unquoted |  | Geometric loop estimate excludes buckle, overlap, protrusions, and actual tightening.
coupon | C1-01 | Baseline 40 mm body-guard section to trial over the matching 1.5 mm aluminum edge. | 1 | coupon units per source manifest | physical coupon count recorded by the source manifest |  |  |  |  |  |  |  |  | candidate physical-fit coupon; result not tested |  |  |  |  | unquoted | 2 | Coupon manifest distinguishes the comparison setup from the count of CAD component files. Files: 7u40-r9-cpn-c1-01-qty1-mm.step, 7u40-r9-cpn-c1-01-qty1-mm.stl
coupon | C1-02 | Compare one guard-section parameter: fitClearancePerSideMm. | 1 | coupon units per source manifest | physical coupon count recorded by the source manifest |  |  |  |  |  |  |  |  | candidate physical-fit coupon; result not tested |  |  |  |  | unquoted | 2 | Coupon manifest distinguishes the comparison setup from the count of CAD component files. Files: 7u40-r9-cpn-c1-02-qty1-mm.step, 7u40-r9-cpn-c1-02-qty1-mm.stl
coupon | C1-03 | Compare one guard-section parameter: fitClearancePerSideMm. | 1 | coupon units per source manifest | physical coupon count recorded by the source manifest |  |  |  |  |  |  |  |  | candidate physical-fit coupon; result not tested |  |  |  |  | unquoted | 2 | Coupon manifest distinguishes the comparison setup from the count of CAD component files. Files: 7u40-r9-cpn-c1-03-qty1-mm.step, 7u40-r9-cpn-c1-03-qty1-mm.stl
coupon | C1-04 | Compare one guard-section parameter: adhesiveLayerMm. | 1 | coupon units per source manifest | physical coupon count recorded by the source manifest |  |  |  |  |  |  |  |  | candidate physical-fit coupon; result not tested |  |  |  |  | unquoted | 2 | Coupon manifest distinguishes the comparison setup from the count of CAD component files. Files: 7u40-r9-cpn-c1-04-qty1-mm.step, 7u40-r9-cpn-c1-04-qty1-mm.stl
coupon | C1-05 | Compare one guard-section parameter: guardThicknessMm. | 1 | coupon units per source manifest | physical coupon count recorded by the source manifest |  |  |  |  |  |  |  |  | candidate physical-fit coupon; result not tested |  |  |  |  | unquoted | 2 | Coupon manifest distinguishes the comparison setup from the count of CAD component files. Files: 7u40-r9-cpn-c1-05-qty1-mm.step, 7u40-r9-cpn-c1-05-qty1-mm.stl
coupon | C1-06 | Short two-piece pair for checking the centered guard split relief on an aluminum edge. | 2 | coupon units per source manifest | physical coupon count recorded by the source manifest |  |  |  |  |  |  |  |  | candidate physical-fit coupon; result not tested |  |  |  |  | unquoted | 4 | Coupon manifest distinguishes the comparison setup from the count of CAD component files. Files: 7u40-r9-cpn-c1-06-a-qty1-mm.step, 7u40-r9-cpn-c1-06-a-qty1-mm.stl, 7u40-r9-cpn-c1-06-b-qty1-mm.step, 7u40-r9-cpn-c1-06-b-qty1-mm.stl
coupon | C1-07 | Short two-piece pair for checking the centered guard split relief on an aluminum edge. | 2 | coupon units per source manifest | physical coupon count recorded by the source manifest |  |  |  |  |  |  |  |  | candidate physical-fit coupon; result not tested |  |  |  |  | unquoted | 4 | Coupon manifest distinguishes the comparison setup from the count of CAD component files. Files: 7u40-r9-cpn-c1-07-a-qty1-mm.step, 7u40-r9-cpn-c1-07-a-qty1-mm.stl, 7u40-r9-cpn-c1-07-b-qty1-mm.step, 7u40-r9-cpn-c1-07-b-qty1-mm.stl
coupon | C1-AL-EDGE | Reusable small plate-edge fixture for the C1 PA12 guard coupons. | 1 | coupon units per source manifest | physical coupon count recorded by the source manifest |  |  |  |  |  |  |  |  | candidate physical-fit coupon; result not tested |  |  |  |  | unquoted | 2 | Coupon manifest distinguishes the comparison setup from the count of CAD component files. Files: 7u40-r9-cpn-c1-al-edge-qty1-mm.step, 7u40-r9-cpn-c1-al-edge-qty1-mm.dxf
coupon | C2-01 | Local front body/guard/lid section for locator clearance and plate support trials. | 1 | coupon units per source manifest | one candidate scenario assembly; component CAD files are listed separately |  |  |  |  |  |  |  |  | candidate physical-fit coupon; result not tested |  |  |  |  | unquoted | 12 | Coupon manifest distinguishes the comparison setup from the count of CAD component files. Files: 7u40-r9-cpn-c2-01-body-wall-qty1-mm.step, 7u40-r9-cpn-c2-01-body-wall-qty1-mm.stl, 7u40-r9-cpn-c2-01-body-wall-qty1-mm.dxf, 7u40-r9-cpn-c2-01-rail-envelope-qty1-mm.step, 7u40-r9-cpn-c2-01-rail-envelope-qty1-mm.stl, 7u40-r9-cpn-c2-01-guard-qty1-mm.step, 7u40-r9-cpn-c2-01-guard-qty1-mm.stl, 7u40-r9-cpn-c2-01-lid-frame-qty1-mm.step, 7u40-r9-cpn-c2-01-lid-frame-qty1-mm.stl, 7u40-r9-cpn-c2-01-lid-plate-qty1-mm.step, 7u40-r9-cpn-c2-01-lid-plate-qty1-mm.stl, 7u40-r9-cpn-c2-01-lid-plate-qty1-mm.dxf
coupon | C2-02 | Local front body/guard/lid section for locator clearance and plate support trials. | 1 | coupon units per source manifest | one candidate scenario assembly; component CAD files are listed separately |  |  |  |  |  |  |  |  | candidate physical-fit coupon; result not tested |  |  |  |  | unquoted | 12 | Coupon manifest distinguishes the comparison setup from the count of CAD component files. Files: 7u40-r9-cpn-c2-02-body-wall-qty1-mm.step, 7u40-r9-cpn-c2-02-body-wall-qty1-mm.stl, 7u40-r9-cpn-c2-02-body-wall-qty1-mm.dxf, 7u40-r9-cpn-c2-02-rail-envelope-qty1-mm.step, 7u40-r9-cpn-c2-02-rail-envelope-qty1-mm.stl, 7u40-r9-cpn-c2-02-guard-qty1-mm.step, 7u40-r9-cpn-c2-02-guard-qty1-mm.stl, 7u40-r9-cpn-c2-02-lid-frame-qty1-mm.step, 7u40-r9-cpn-c2-02-lid-frame-qty1-mm.stl, 7u40-r9-cpn-c2-02-lid-plate-qty1-mm.step, 7u40-r9-cpn-c2-02-lid-plate-qty1-mm.stl, 7u40-r9-cpn-c2-02-lid-plate-qty1-mm.dxf
coupon | C2-03 | Local front body/guard/lid section for locator clearance and plate support trials. | 1 | coupon units per source manifest | one candidate scenario assembly; component CAD files are listed separately |  |  |  |  |  |  |  |  | candidate physical-fit coupon; result not tested |  |  |  |  | unquoted | 12 | Coupon manifest distinguishes the comparison setup from the count of CAD component files. Files: 7u40-r9-cpn-c2-03-body-wall-qty1-mm.step, 7u40-r9-cpn-c2-03-body-wall-qty1-mm.stl, 7u40-r9-cpn-c2-03-body-wall-qty1-mm.dxf, 7u40-r9-cpn-c2-03-rail-envelope-qty1-mm.step, 7u40-r9-cpn-c2-03-rail-envelope-qty1-mm.stl, 7u40-r9-cpn-c2-03-guard-qty1-mm.step, 7u40-r9-cpn-c2-03-guard-qty1-mm.stl, 7u40-r9-cpn-c2-03-lid-frame-qty1-mm.step, 7u40-r9-cpn-c2-03-lid-frame-qty1-mm.stl, 7u40-r9-cpn-c2-03-lid-plate-qty1-mm.step, 7u40-r9-cpn-c2-03-lid-plate-qty1-mm.stl, 7u40-r9-cpn-c2-03-lid-plate-qty1-mm.dxf
coupon | C3-01 | Two-face edge coupons for trialing a real L bracket, fasteners, washer coverage, adjustment and clamping. | 1 | coupon units per source manifest | physical coupon count recorded by the source manifest |  |  |  |  |  |  |  |  | candidate physical-fit coupon; result not tested |  |  |  |  | unquoted | 4 | Coupon manifest distinguishes the comparison setup from the count of CAD component files. Files: 7u40-r9-cpn-c3-01-bottom-qty1-mm.step, 7u40-r9-cpn-c3-01-bottom-qty1-mm.dxf, 7u40-r9-cpn-c3-01-wall-qty1-mm.step, 7u40-r9-cpn-c3-01-wall-qty1-mm.dxf
coupon | C3-02 | Two-face edge coupons for trialing a real L bracket, fasteners, washer coverage, adjustment and clamping. | 1 | coupon units per source manifest | physical coupon count recorded by the source manifest |  |  |  |  |  |  |  |  | candidate physical-fit coupon; result not tested |  |  |  |  | unquoted | 4 | Coupon manifest distinguishes the comparison setup from the count of CAD component files. Files: 7u40-r9-cpn-c3-02-bottom-qty1-mm.step, 7u40-r9-cpn-c3-02-bottom-qty1-mm.dxf, 7u40-r9-cpn-c3-02-wall-qty1-mm.step, 7u40-r9-cpn-c3-02-wall-qty1-mm.dxf
coupon | C3-03 | Two-face edge coupons for trialing a real L bracket, fasteners, washer coverage, adjustment and clamping. | 1 | coupon units per source manifest | physical coupon count recorded by the source manifest |  |  |  |  |  |  |  |  | candidate physical-fit coupon; result not tested |  |  |  |  | unquoted | 4 | Coupon manifest distinguishes the comparison setup from the count of CAD component files. Files: 7u40-r9-cpn-c3-03-bottom-qty1-mm.step, 7u40-r9-cpn-c3-03-bottom-qty1-mm.dxf, 7u40-r9-cpn-c3-03-wall-qty1-mm.step, 7u40-r9-cpn-c3-03-wall-qty1-mm.dxf
excluded_from_cost | 7U40-R9-HW-RAIL-UNIT-ENVELOPE | 40HP rail unit | 6 | piece |  |  |  |  |  |  |  |  |  | existing source rail; cost excluded by request |  |  |  |  | excluded from cost by request |  | Existing rail source; rail manufacturing cost is excluded by request.
excluded_from_cost | 7U40-R9-PCB-FIXER | Fixer PCB | 2 | piece |  |  | 1.6 |  |  |  |  |  |  | user-confirmed existing source PCB |  |  |  |  | excluded from cost by request |  | Existing source PCB; purchase/manufacturing cost excluded by request. PCB thickness 1.6 mm is user-confirmed.
excluded_from_cost | 7U40-R9-PCB-PADDER-3U | 3U padder PCB | 4 | piece |  |  | 1.6 |  |  |  |  |  |  | user-confirmed existing source PCB |  |  |  |  | excluded from cost by request |  | Existing source PCB; purchase/manufacturing cost excluded by request. PCB thickness 1.6 mm is user-confirmed.
excluded_from_cost | 7U40-R9-PCB-PADDER-1U | 1U padder PCB | 2 | piece |  |  | 1.6 |  |  |  |  |  |  | user-confirmed existing source PCB |  |  |  |  | excluded from cost by request |  | Existing source PCB; purchase/manufacturing cost excluded by request. PCB thickness 1.6 mm is user-confirmed.

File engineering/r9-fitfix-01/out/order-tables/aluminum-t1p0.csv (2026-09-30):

part | material | order_quantity | stl | step | dxf
body-bottom | A5052 t1.5 black anodized candidate | 1 | aluminum/body/7u40-r9f-body-bottom-qty1-mm.stl | aluminum/body/7u40-r9f-body-bottom-qty1-mm.step | aluminum/body/7u40-r9f-body-bottom-qty1-mm.dxf
body-front_back | A5052 t1.5 black anodized candidate | 2 | aluminum/body/7u40-r9f-body-front_back-qty2-mm.stl | aluminum/body/7u40-r9f-body-front_back-qty2-mm.step | aluminum/body/7u40-r9f-body-front_back-qty2-mm.dxf
body-left_right | A5052 t1.5 black anodized candidate | 2 | aluminum/body/7u40-r9f-body-left_right-qty2-mm.stl | aluminum/body/7u40-r9f-body-left_right-qty2-mm.step | aluminum/body/7u40-r9f-body-left_right-qty2-mm.dxf
lid-plate | A5052 t1.5 black anodized candidate | 1 | aluminum/t1p0/7u40-r9f-lid-plate-qty1-mm.stl | aluminum/t1p0/7u40-r9f-lid-plate-qty1-mm.step | aluminum/t1p0/7u40-r9f-lid-plate-qty1-mm.dxf

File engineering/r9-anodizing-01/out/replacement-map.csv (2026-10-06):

part | quantity | old_file | old_sha256 | new_file | new_sha256
c1-metal-edge | 1 | engineering/r9-fitfix-01/out/coupons/c1-metal/7u40-r9f-c1-metal-edge-qty1-mm.step | 96b1e980d4f64edcd41362a5fe5d0dc9ccfffe678fb1ac384a5ba276c703f6bd | step/7u40-r9a-c1-metal-edge-qty1-mm.step | d698dc851845b4c9f2a9c38e095ca8ad0ba80456c41490d6706c1c82b6169a44
c1-metal-edge | 1 | engineering/r9-fitfix-01/out/coupons/c1-metal/7u40-r9f-c1-metal-edge-qty1-mm.dxf | cfbfb94964fd001e00b3fff272d9bd80482b918533a98401b2fba4e222236d0f | dxf/7u40-r9a-c1-metal-edge-qty1-mm.dxf | e4ac30352a72d07caa57a75bb9dac38337f8d072ef8dc54f50f6dc5b40483637
c1-metal-edge | 1 | engineering/r9-fitfix-01/out/coupons/c1-metal/7u40-r9f-c1-metal-edge-qty1-mm.stl | 253641ca51e6747977062e2a7a76b27211ea26c79ebb50fff092c91f21298d34 | reference-stl/7u40-r9a-c1-metal-edge-qty1-mm.stl | 13028d73073528d879d8b755ec06f3af2a4008a670bcf21af637ace74fd36dfa
c2-01-wall | 1 | engineering/r9-fitfix-01/out/coupons/c2-01/7u40-r9f-c2-01-wall-qty1-mm.step | b665109c5993d0165690b2d08df6430db651ab729a63480bf77e264f5f8cc870 | step/7u40-r9a-c2-01-wall-qty1-mm.step | 3c788e43745acdb9e8b879b18b912884de9bd5adb62e59406ead7f0cca37bc94
c2-01-wall | 1 | engineering/r9-fitfix-01/out/coupons/c2-01/7u40-r9f-c2-01-wall-qty1-mm.dxf | acb1517d5967f14bcc8cffdd80a526ac298486cc20957b12afef2aa32ed3585f | dxf/7u40-r9a-c2-01-wall-qty1-mm.dxf | b3ff99bfa50367538b72c23a1e32da0c96c71d42bef570c4c15da76a4d8fa743
c2-01-wall | 1 | engineering/r9-fitfix-01/out/coupons/c2-01/7u40-r9f-c2-01-wall-qty1-mm.stl | bc3cadc2e5a4654bc09c98c8830e0b88e61c23457d7ec5060a61664bf79c6583 | reference-stl/7u40-r9a-c2-01-wall-qty1-mm.stl | 16516dc6df822c5e483c200857db85c12f0dc21954970fd69819ce2fbf263d5f
c2-01-plate | 1 | engineering/r9-fitfix-01/out/coupons/c2-01/7u40-r9f-c2-01-plate-qty1-mm.step | 5778e3c786f5349c3dd88b88ed63da8f09b7e1a06ec066fd96aa89d0744f3112 | step/7u40-r9a-c2-01-plate-qty1-mm.step | 91dbb02a22ff56b7c5e78174b03d9d3326337167d3091a12b80e46960b7349c2
c2-01-plate | 1 | engineering/r9-fitfix-01/out/coupons/c2-01/7u40-r9f-c2-01-plate-qty1-mm.dxf | 4c95e5953b9490163a318d2d9822a44b5c1d20a6054d1960a947d666f5e7e18d | dxf/7u40-r9a-c2-01-plate-qty1-mm.dxf | 747f6231c01309346361c483811752ea3cf45d392441f1cf39e86e0e99ba44b1
c2-01-plate | 1 | engineering/r9-fitfix-01/out/coupons/c2-01/7u40-r9f-c2-01-plate-qty1-mm.stl | da6cf4a7ee8ab636f8af53ba6bcda5a37192707441da651ea076da464f386b54 | reference-stl/7u40-r9a-c2-01-plate-qty1-mm.stl | 32ca16a17564af81d21f4dd8073912367531430c412e9347518f546b42f03c02
c4-01-floor | 1 | engineering/r9-fitfix-01/out/coupons/c4-01/7u40-r9f-c4-01-floor-qty1-mm.step | 6c21614c25f571960ea7834a39b6d96fafa96971cd1363f32650ff22c83f0981 | step/7u40-r9a-c4-01-floor-qty1-mm.step | dab7bec7fa297a65b2b48593fb748caebf93cf379e5432e25c2e87ca0da713d2
c4-01-floor | 1 | engineering/r9-fitfix-01/out/coupons/c4-01/7u40-r9f-c4-01-floor-qty1-mm.dxf | 5644862d7ac3390fb53ca2c554673c5b384ad6183fd46dae2691f3d40ff16fc1 | dxf/7u40-r9a-c4-01-floor-qty1-mm.dxf | 5ebcfaf99a034fe580223ed823b1791faff303ca1872b363521031cfac1e0318
c4-01-floor | 1 | engineering/r9-fitfix-01/out/coupons/c4-01/7u40-r9f-c4-01-floor-qty1-mm.stl | db7cfe77049539fa1bd40ef74d3424577fecd7c90b1cf8cc8618a84884b39b56 | reference-stl/7u40-r9a-c4-01-floor-qty1-mm.stl | fd891b99565310900cdb6529fbeb552e96c6dcd4c3b48b5c717a8a5a610500db
c4-01-wall | 1 | engineering/r9-fitfix-01/out/coupons/c4-01/7u40-r9f-c4-01-wall-qty1-mm.step | 5f93a830222b02953328c15e22c7db98a3c71337c657c33bea06c94d3ac51306 | step/7u40-r9a-c4-01-wall-qty1-mm.step | d2182dabfd9084ccdf1295d6a9f8fc2df1700407dd319314145c7b188f6b0202
c4-01-wall | 1 | engineering/r9-fitfix-01/out/coupons/c4-01/7u40-r9f-c4-01-wall-qty1-mm.dxf | daf29923d8d416231db5fcf2bf0c04d8722789c2f87e392bd1f739d11344f383 | dxf/7u40-r9a-c4-01-wall-qty1-mm.dxf | 1e478d9d3795806a071a43a6b65ebf3f2df110026da453dfbc61f1e803a9339b
c4-01-wall | 1 | engineering/r9-fitfix-01/out/coupons/c4-01/7u40-r9f-c4-01-wall-qty1-mm.stl | 39ed891e457b35b0e153315f5b12ab257b782039afef6b5b3c799c8a53e02e3b | reference-stl/7u40-r9a-c4-01-wall-qty1-mm.stl | e87e84e43c8ca0a9c2585a0877831334d56355d74c0d1c451573c856dd86eedd
c5-01-front | 1 | engineering/r9-fitfix-01/out/coupons/c5-01/7u40-r9f-c5-01-front-qty1-mm.step | a900b059cbae0aa43cd33e189459bd6e6f02c06733c54e54c13a3f9741430095 | step/7u40-r9a-c5-01-front-qty1-mm.step | c597ef206ec1220b78d24e0a497411f5155acbf26c662e66e0833b8522311987
c5-01-front | 1 | engineering/r9-fitfix-01/out/coupons/c5-01/7u40-r9f-c5-01-front-qty1-mm.dxf | 2dabc397a3dd415361c5ec18d3f26767e958e7ed0668cd56277b6671a7722ff7 | dxf/7u40-r9a-c5-01-front-qty1-mm.dxf | 260ab849133a6273cb72d93aade6ee13f721216ce651a03d776d3d4977697629
c5-01-front | 1 | engineering/r9-fitfix-01/out/coupons/c5-01/7u40-r9f-c5-01-front-qty1-mm.stl | a5449ea295d5fe1ad9ebfd306bb8cff83b602e9a5078a81e280fb3d3d68c6751 | reference-stl/7u40-r9a-c5-01-front-qty1-mm.stl | eadf53ab49b9a75795e411fb4242a00d6ded0b6ae4e43bf34ee0d27152204226
c5-01-left | 1 | engineering/r9-fitfix-01/out/coupons/c5-01/7u40-r9f-c5-01-left-qty1-mm.step | 265773012208add9d31cee046cd805c6b14e64d78142b31689cac01af60c0806 | step/7u40-r9a-c5-01-left-qty1-mm.step | bf96db8eb716fc75e3804daa804a79c50b736c7b4f63b19fb37371f3f5e88f52
c5-01-left | 1 | engineering/r9-fitfix-01/out/coupons/c5-01/7u40-r9f-c5-01-left-qty1-mm.dxf | dd30b8aca768f5bc5bd90ccde4eb8aedf822f5fb1e0732c48da638e89f8c08b0 | dxf/7u40-r9a-c5-01-left-qty1-mm.dxf | 37b969cc6c0a620b08f1509efd0bbb9cd14a84816b10f785cc27843ca106f586
c5-01-left | 1 | engineering/r9-fitfix-01/out/coupons/c5-01/7u40-r9f-c5-01-left-qty1-mm.stl | e08f89b5f3994fad632ef5dcf02eb84e54019d085084a3ff841a8be60c4b2f29 | reference-stl/7u40-r9a-c5-01-left-qty1-mm.stl | 213add1876136067120c5fcda0aad6471e4627f6f4785b38d29526a5b9284202
c3-01-bottom | 1 | engineering/r9-prototype-01/out/coupons/7u40-r9-cpn-c3-01-bottom-qty1-mm.step | a250dda6531aa5cc21d360ec6b758aa3dc46964bc39812a40333e5c1c33ec87b | step/7u40-r9a-c3-01-bottom-qty1-mm.step | 262e8bc056d5d6118b12103cabc3a9df0928541affaafe2c70d25a1e953cc9fe
c3-01-bottom | 1 | engineering/r9-prototype-01/out/coupons/7u40-r9-cpn-c3-01-bottom-qty1-mm.dxf | 57cbf74b25e8756cb80e06be475a035616f02879238623301bf70ecc76e47e7c | dxf/7u40-r9a-c3-01-bottom-qty1-mm.dxf | 30f93531e1a11538c49c7b11d192d43b64d72929e9ec3c036fc4a7a53ca61d1c
c3-01-bottom | 1 | new reference STL | REFERENCE ONLY | reference-stl/7u40-r9a-c3-01-bottom-qty1-mm.stl | 9cf0e599dfc0f304527c7fbadccadf9e150244a3ff9af84d62e0b34c8b4b143f
c3-01-wall | 1 | engineering/r9-prototype-01/out/coupons/7u40-r9-cpn-c3-01-wall-qty1-mm.step | 0ffece8d4bc2e1daf2febb845320893912507e999da6593e88850d7cdc491a8c | step/7u40-r9a-c3-01-wall-qty1-mm.step | a49b2f2deee5434d157f9e0b33f3ccdecb457cd5d27d7a06633f3e595c42b34e
c3-01-wall | 1 | engineering/r9-prototype-01/out/coupons/7u40-r9-cpn-c3-01-wall-qty1-mm.dxf | 2414b343bbf33c0ab93b31c7c24c627ff81fb99a0ca613a0e95fd9cd1a18b2e5 | dxf/7u40-r9a-c3-01-wall-qty1-mm.dxf | c6ae85f5c7663b9e505a7b9c8452b57effe8d8a004b5ff4f0a8f8cd0fe517a26
c3-01-wall | 1 | new reference STL | REFERENCE ONLY | reference-stl/7u40-r9a-c3-01-wall-qty1-mm.stl | 68cc64c943ca45072e1250ffd1f8e6b4183912c2931e221c8eb03681fbbba315
c3-02-bottom | 1 | engineering/r9-prototype-01/out/coupons/7u40-r9-cpn-c3-02-bottom-qty1-mm.step | c97070bc259cb2465cda8b15d997d58f156941d90787d0e0256b964e0b3b66cf | step/7u40-r9a-c3-02-bottom-qty1-mm.step | f354873313963b19894cd2658c339572d3f69eab1df13f73c2ef93012d093742
c3-02-bottom | 1 | engineering/r9-prototype-01/out/coupons/7u40-r9-cpn-c3-02-bottom-qty1-mm.dxf | 8441f6e8bdce564262a3500d16380fd7f863af98247ee13b9204ce0f63a40ee8 | dxf/7u40-r9a-c3-02-bottom-qty1-mm.dxf | ddca863dbb12a432c3053f04f1d7519c17754256afc03e60f0c9049c8c58a1d3
c3-02-bottom | 1 | new reference STL | REFERENCE ONLY | reference-stl/7u40-r9a-c3-02-bottom-qty1-mm.stl | 72164d3464cdcabe93f0eff97cc7342d1966409621ef31227f160c737e2681d0
c3-02-wall | 1 | engineering/r9-prototype-01/out/coupons/7u40-r9-cpn-c3-02-wall-qty1-mm.step | b29008e9ce4d86e4b6951c28bda0872dcaa88b1aeb57d5d668b17f89057ba9c2 | step/7u40-r9a-c3-02-wall-qty1-mm.step | 3c5f86f514060724895ac0fc65cc03bfffb8bf66546680a13280e44393defe0a
c3-02-wall | 1 | engineering/r9-prototype-01/out/coupons/7u40-r9-cpn-c3-02-wall-qty1-mm.dxf | 1b57082da9d56b0a0b9854f2781e444b12f2f6546c591dc346cc57be9c030c50 | dxf/7u40-r9a-c3-02-wall-qty1-mm.dxf | 604ceb19a1f57c5c449a6f4a1c40fa9249ed187e8c6ee5ca6c340ee1c8a290b2
c3-02-wall | 1 | new reference STL | REFERENCE ONLY | reference-stl/7u40-r9a-c3-02-wall-qty1-mm.stl | 47fafae640b1f6ad2d1acc6aea1460754365902d5e8b2bf37a1547206c5d7268
c3-03-bottom | 1 | engineering/r9-prototype-01/out/coupons/7u40-r9-cpn-c3-03-bottom-qty1-mm.step | d06644a1f9a86008dbd536c6cdf7647df5a55ca0afb125afdbccca6fe9ae2560 | step/7u40-r9a-c3-03-bottom-qty1-mm.step | 1b4b8ca83a7aad0f2a90cc5e8ea8136af72108417ce068cd9c862802c03d5b2f
c3-03-bottom | 1 | engineering/r9-prototype-01/out/coupons/7u40-r9-cpn-c3-03-bottom-qty1-mm.dxf | 46728be4508067b2c542116c46bc643f7c346a8f31644f630a2c197e60445ec7 | dxf/7u40-r9a-c3-03-bottom-qty1-mm.dxf | 801920b7f40e23bfd1530745935a9065e3ed18810f060bba439f6a347e6b4899
c3-03-bottom | 1 | new reference STL | REFERENCE ONLY | reference-stl/7u40-r9a-c3-03-bottom-qty1-mm.stl | 94b68d33ac191b2ffc543183832e91a27d5abd5ee026d70d68f8278dc8f0d488
c3-03-wall | 1 | engineering/r9-prototype-01/out/coupons/7u40-r9-cpn-c3-03-wall-qty1-mm.step | ae5b4e875a21afa56bc93a6753cbeb0a77f510f9fb7972cffb23d4a2fe9583b4 | step/7u40-r9a-c3-03-wall-qty1-mm.step | d5b16fe2d1e08a154f414a6662bb52d621bce3f74df4a6788b74322bdf17829f
c3-03-wall | 1 | engineering/r9-prototype-01/out/coupons/7u40-r9-cpn-c3-03-wall-qty1-mm.dxf | 77b3fd15298e7cf4cb056c4818b11fd78a6c3de112bfef68059b9666889f362c | dxf/7u40-r9a-c3-03-wall-qty1-mm.dxf | 4617510d5555425bff0490e03102ab18a9acc1ec2bcb7085692167750ee58212
c3-03-wall | 1 | new reference STL | REFERENCE ONLY | reference-stl/7u40-r9a-c3-03-wall-qty1-mm.stl | bac8989008394b1e31209f134ce5e48074af4adcb4999cb56fa94e037ff301a6

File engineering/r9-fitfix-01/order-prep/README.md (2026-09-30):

# ZUDO CASE 小型試験片・見積準備セット

**見積用・未送信・未発注。対象は小型片だけで、ケース１台分を含まない。**

| 区分 | 材料と仕上げの依頼案 | 種類 | 個数 |
|---|---|---:|---:|
| 基本PA12：C1/C2/C4/C5 | MJF PA12-HP、黒染め | 13 | 15 |
| 基本アルミ：共用治具と対向板 | A5052、t1.5、バリ取り、黒アルマイト | 7 | 7 |
| 別見積C3：座金・長穴・工具 | 同上。旧R9の下辺接合試験片 | 6 | 6 |

PA12はJLC3DPを候補、アルミはJLCCNCまたは指定板金業者を候補とする。部品別の造形／加工受入や価格はまだ回答を得ていない。送り先住所を含む送料、税、通貨、納期は未確定。注文や業者への連絡は行っていない。

## 添付と数量

- `fit-coupons-pa12-NOT-APPROVED.zip`：各STLは１個の形状。C1-06/07だけ各２個、残りは各１個。13種類・15個。黒染め指定は見積依頼文にある。
- `fit-coupons-metal-NOT-APPROVED.zip`：７板、各１個。STEP/DXFは同じ板の２形式なので２個に数えない。
- `c3-hardware-coupons-R9-PROTOTYPE-01-DRAFT.zip`：任意の別見積。C3-01/02/03の底・壁を各１枚、計６枚。元版名とSHA-256を保持する。01は5.5×7.5長穴、02は5.5×8.5長穴、03はφ5.5丸穴の対照。丸穴の採用を意味しない。
- `order-plan.json`：全部品のファイル・数量・寸法・添付SHA-256・未確定欄。
- `PA12-RFQ.txt` / `ALUMINUM-RFQ.txt`：そのまま確認に回せる英語の未送信文案。
- `TEST-PLAN.md` / `FIT-RECORD.md`：乾式確認→締結→接着へ進む手順と空欄記録票。

C2は01の壁・ガード・天板を02/03へ再利用する。C1も１枚のアルミ片を順に使う。全ての乾式比較を終えるまで共用品を接着で固定しない。複数の接着材を比較するための追加試験片はこの数量に含めていない。

## 先に決められること／業者回答が必要なこと

形状比較用の発注案は上記数量で作成済み。接着剤選定と全体運搬試験の完了を、小型乾式試験片の発注条件にはしない。

PA12は[公式材質ページ](https://jlc3dp.com/help/article/pa12-hp-nylon)でMJF、肉厚1mm、100mm以下の公差±0.3mmを確認した（2026-09-30）。今回の1.0mm壁、細い文字、黒染め後の精度はファイル別の業者確認が必要。比較差が公差より小さいため、結果は実測値と一緒に評価する。

アルミは[公式板金ページ](https://jlccnc.com/sheet-metal-fabrication)で5052、1.5mm板、アルマイトの掲載を確認した。10.5×20mm等の小片を黒アルマイトまで処理できるかは未確認。小さすぎる場合は勝手に板を拡大せず、業者の治具・キャリア案を確認する。

支払前に、部品別の加工可否・仕上げ、税送料込み金額、納期、C3を含めるか、正しいZIPと個数を確定する。金額と送り先がない現時点では有償注文の承認対象が確定していない。

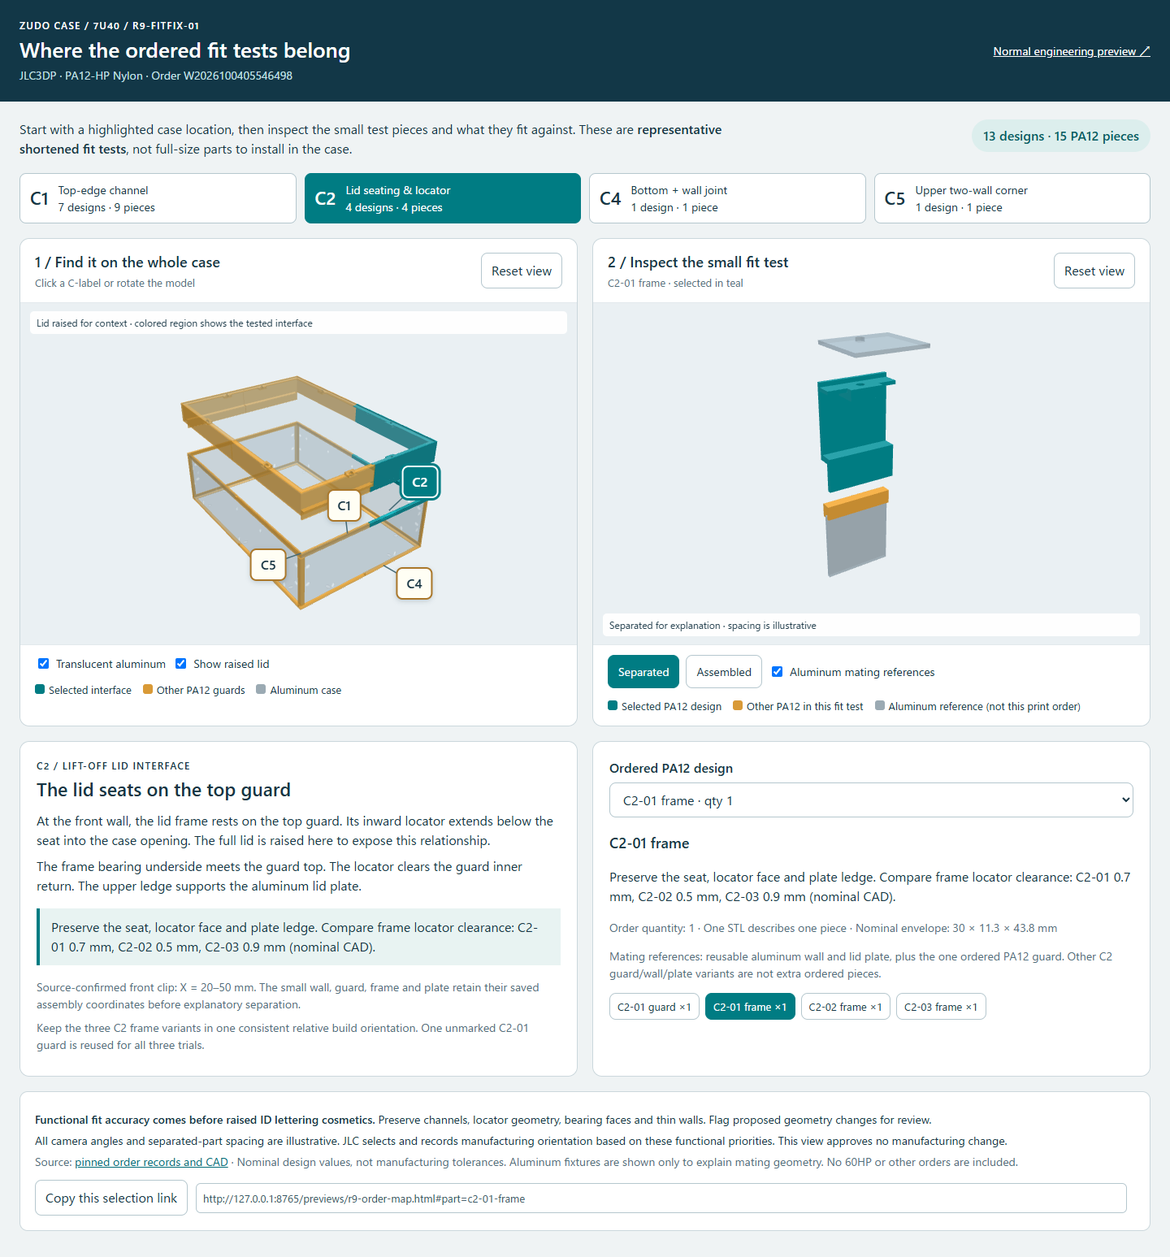
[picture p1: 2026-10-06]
engineering/order-map/verification/order-map-C2-1440.png

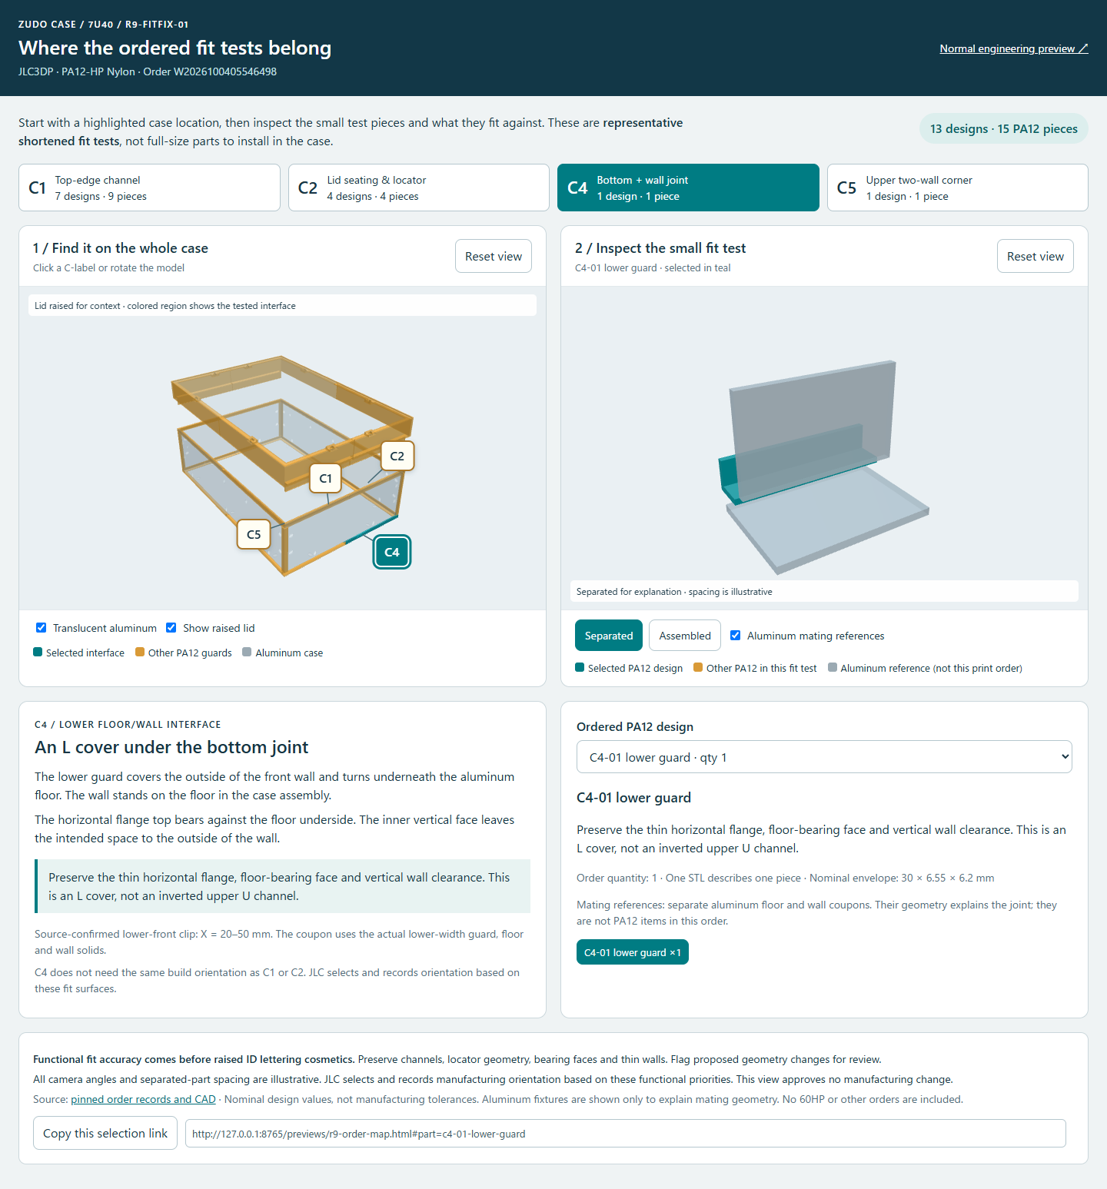
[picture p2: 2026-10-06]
engineering/order-map/verification/order-map-C4-1440.png

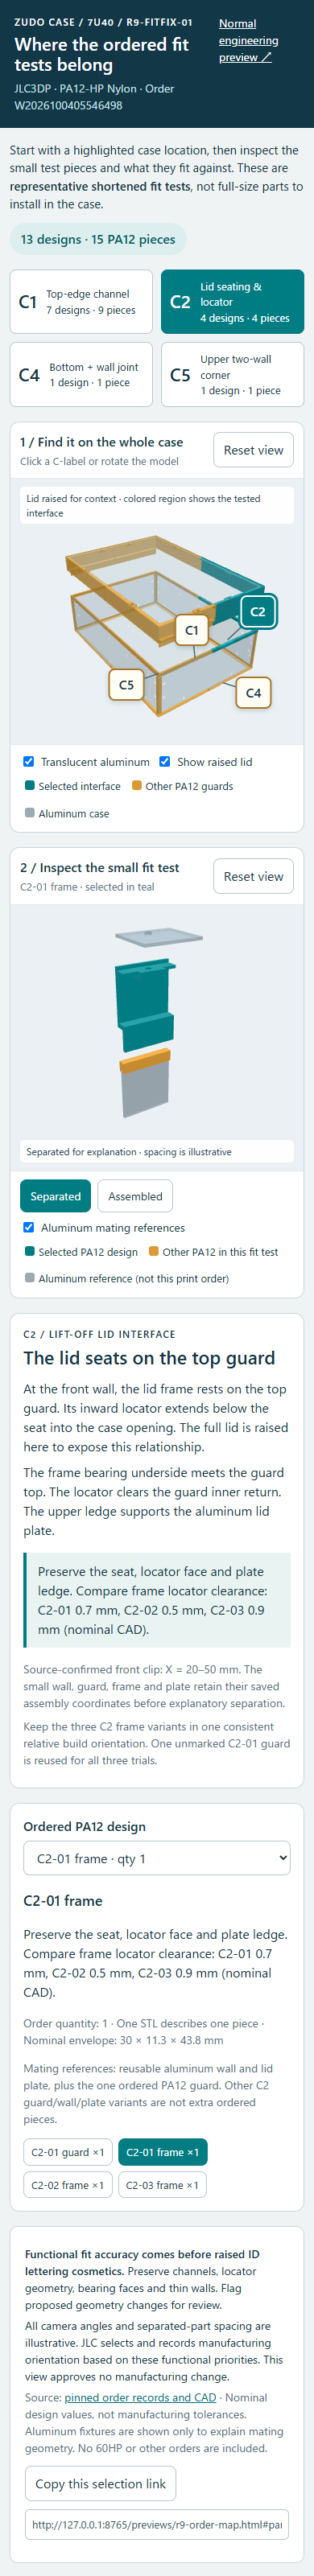
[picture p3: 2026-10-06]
engineering/order-map/verification/order-map-C2-390.png

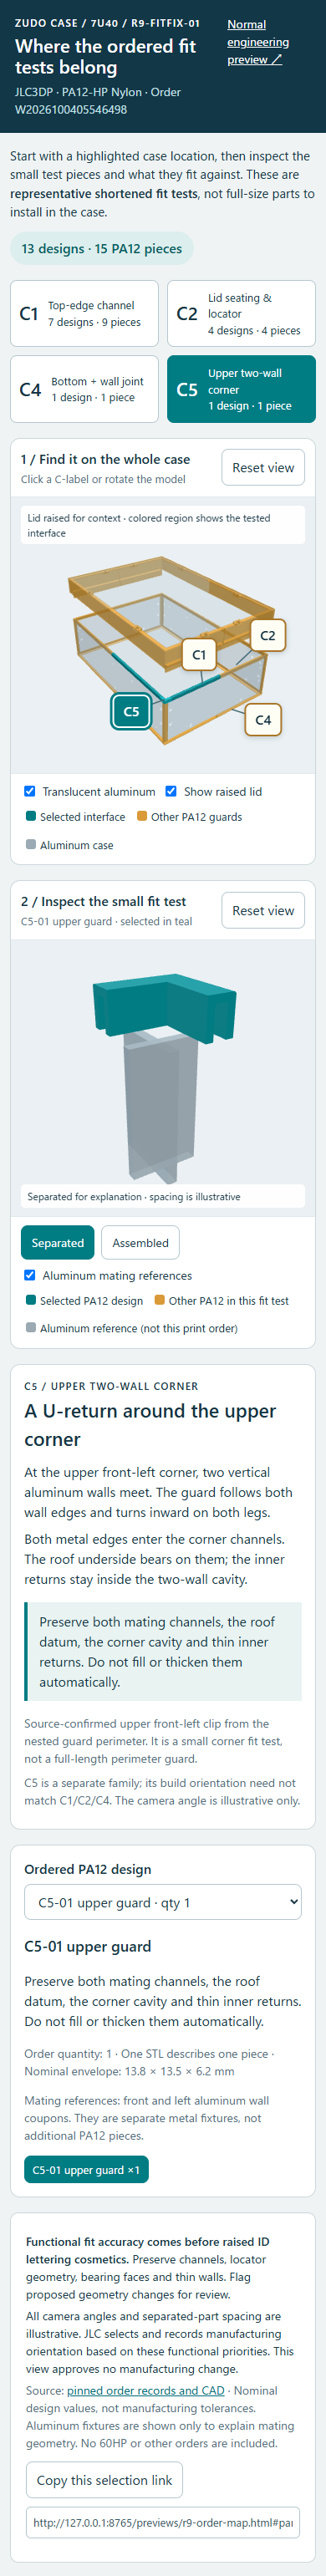
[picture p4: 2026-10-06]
engineering/order-map/verification/order-map-C5-390.png

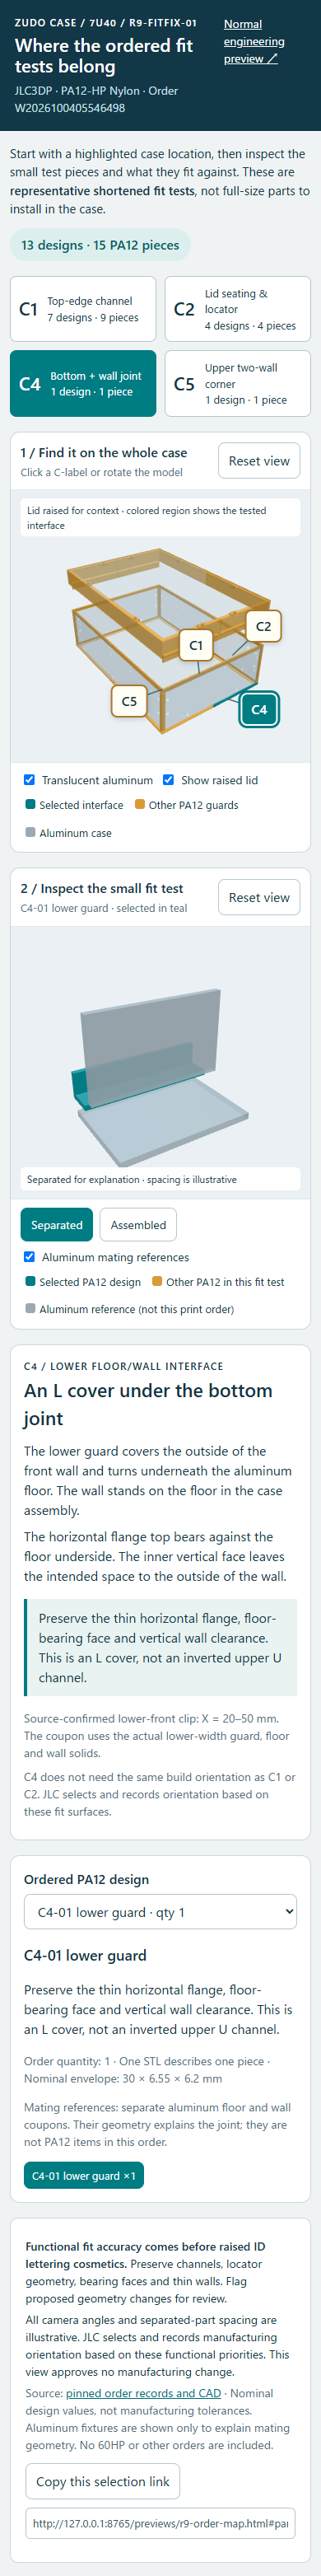
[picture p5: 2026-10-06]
engineering/order-map/verification/order-map-C4-390.png

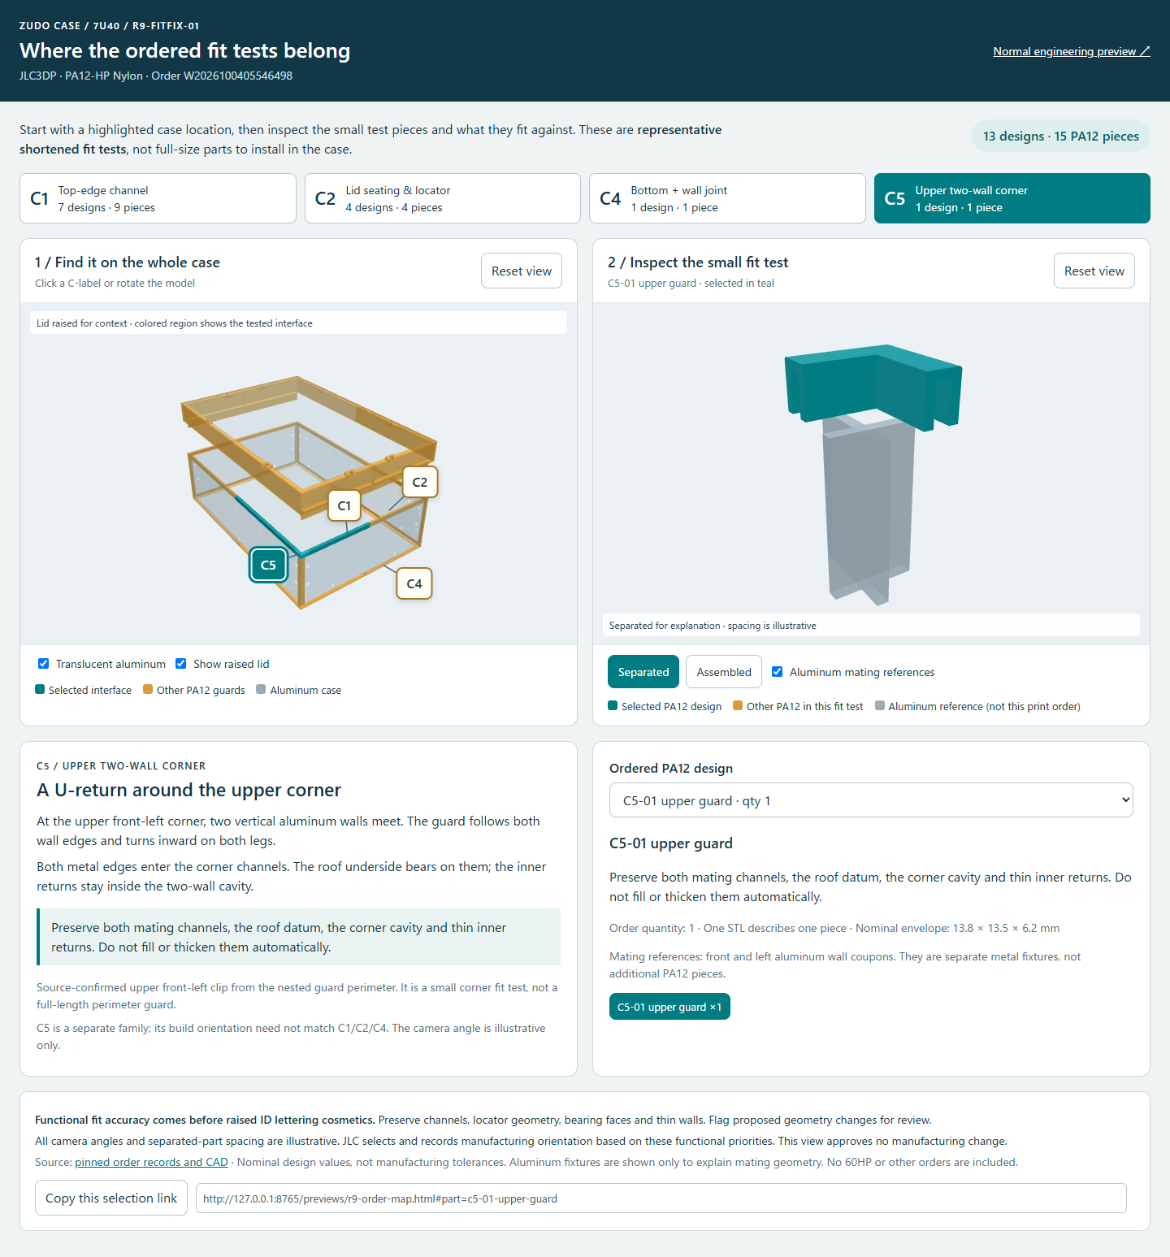
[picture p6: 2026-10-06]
engineering/order-map/verification/order-map-C5-1440.png

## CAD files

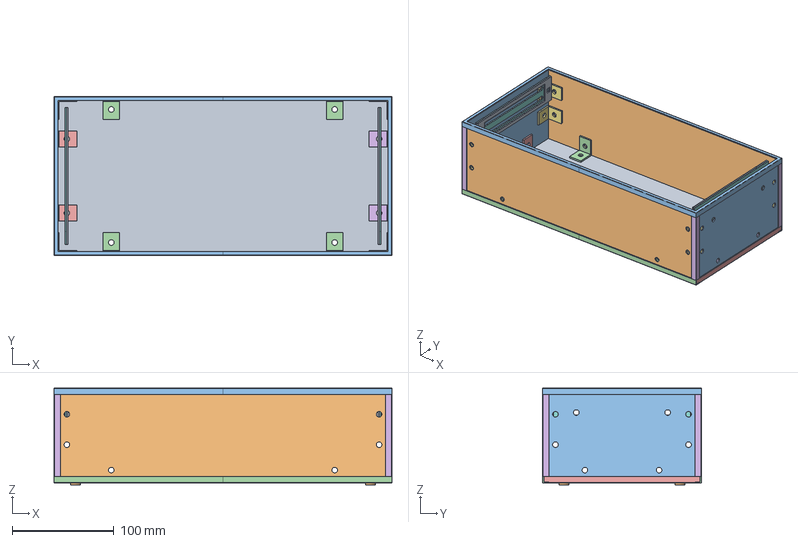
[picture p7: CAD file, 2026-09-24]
engineering/r6-body/engineering/3u60/3u60_r6_t1p2_enclosure_boards_assembly.step
332.8 x 156.4 x 95.2 mm

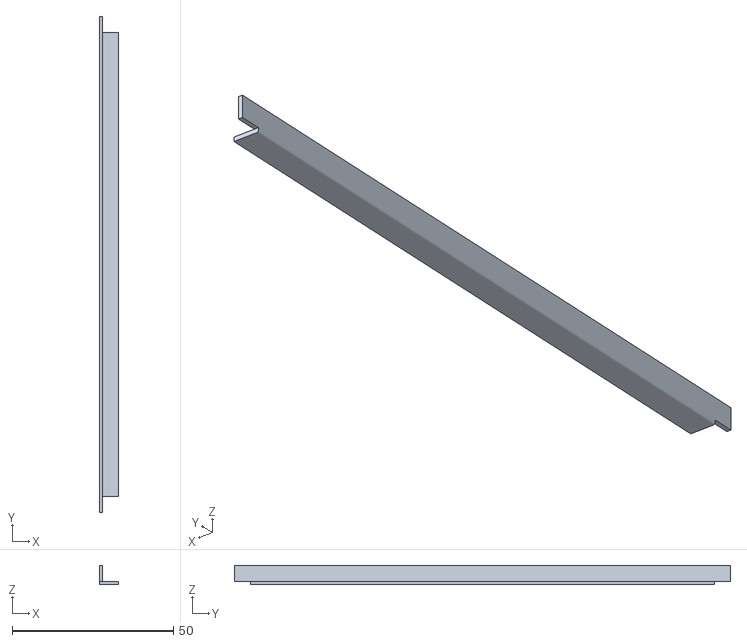
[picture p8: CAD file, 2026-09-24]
engineering/r6-body/stl/3u60/t1p0/3u60_r6_t1p0_03_lower_depth_full_qty2_mm.stl
6.00 x 154.0 x 6.00

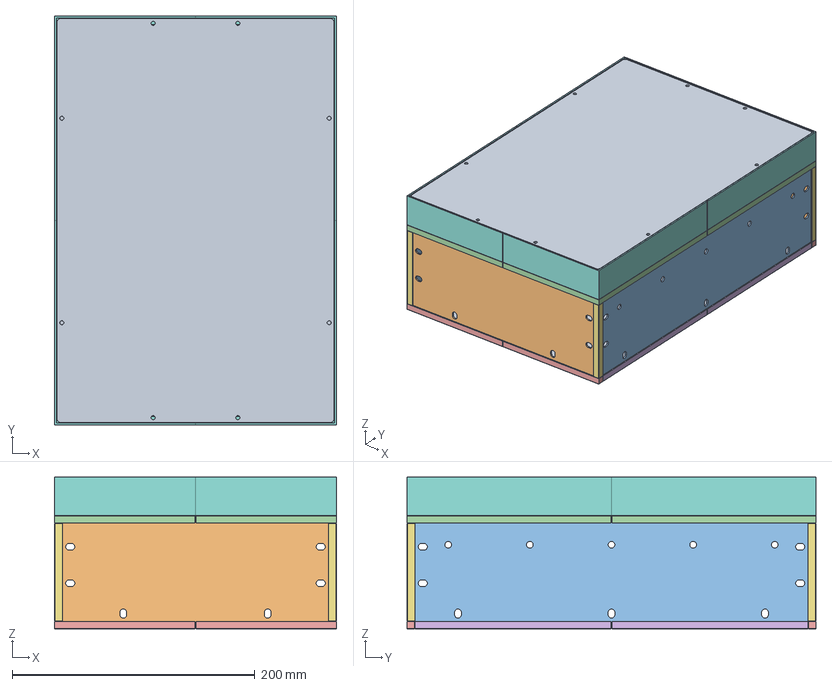
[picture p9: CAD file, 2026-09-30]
engineering/r9-fitfix-01/out/assembly/t1p2-assembled-REFERENCE.step
232.4 x 337.0 x 125.2 mm

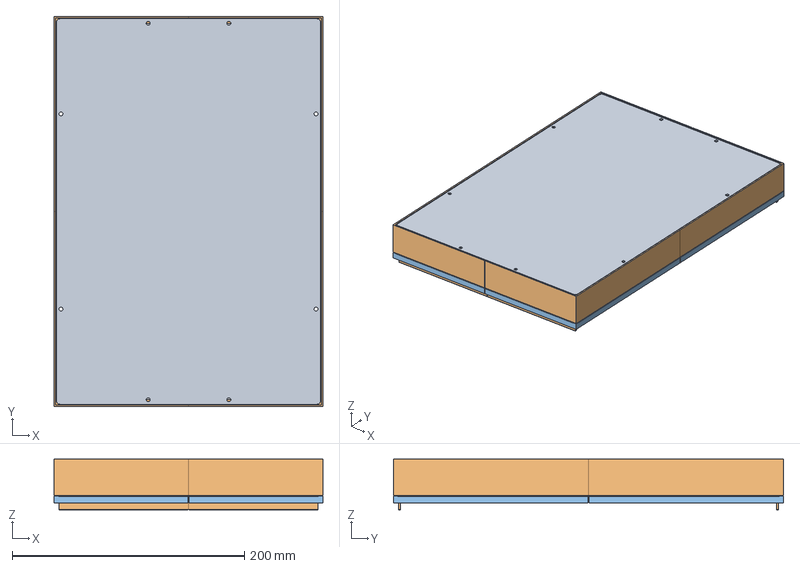
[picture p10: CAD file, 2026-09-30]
engineering/r9-prototype-01/out/assembly/7u40-r9-reference-assembly-NOT-APPROVED.step
231.8 x 336.4 x 43.8 mm

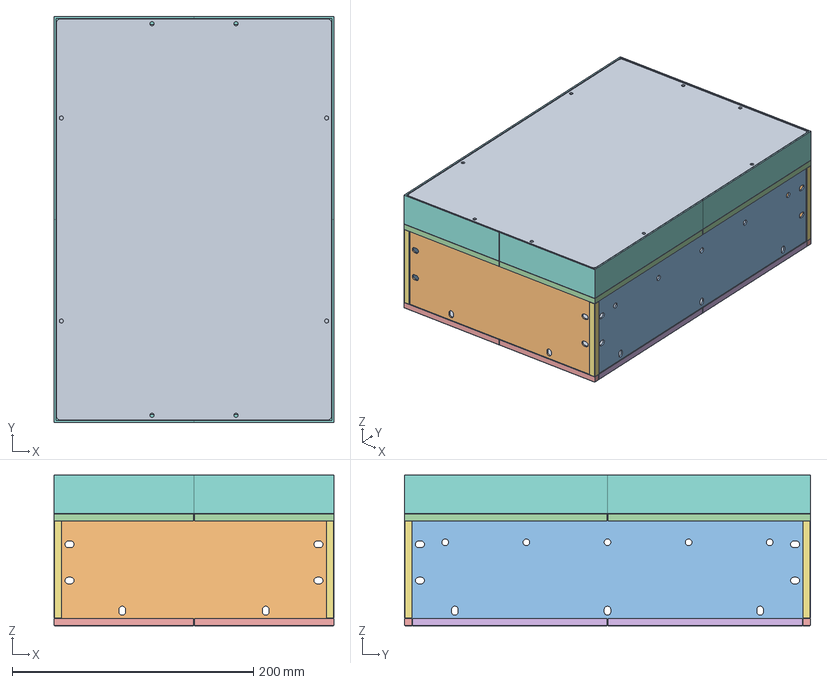
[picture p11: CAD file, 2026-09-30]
engineering/r9-fitfix-01/out/assembly/t1p0-assembled-REFERENCE.step
232.0 x 336.6 x 124.8 mm

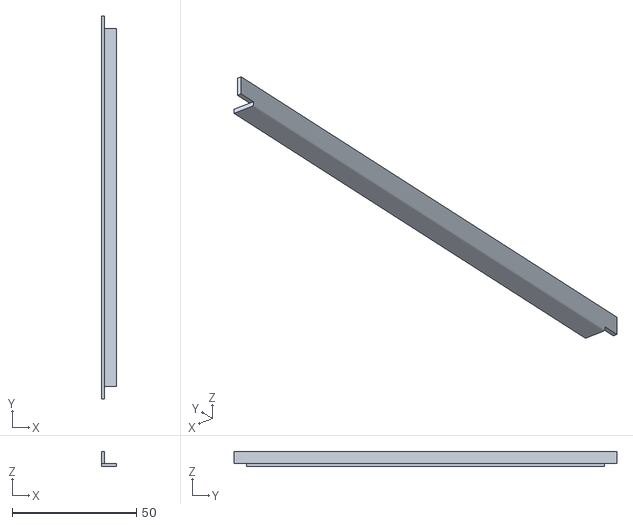
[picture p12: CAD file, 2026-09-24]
engineering/r6-body/stl/3u60/t1p2/3u60_r6_t1p2_03_lower_depth_full_qty2_mm.stl
6.20 x 154.0 x 6.20

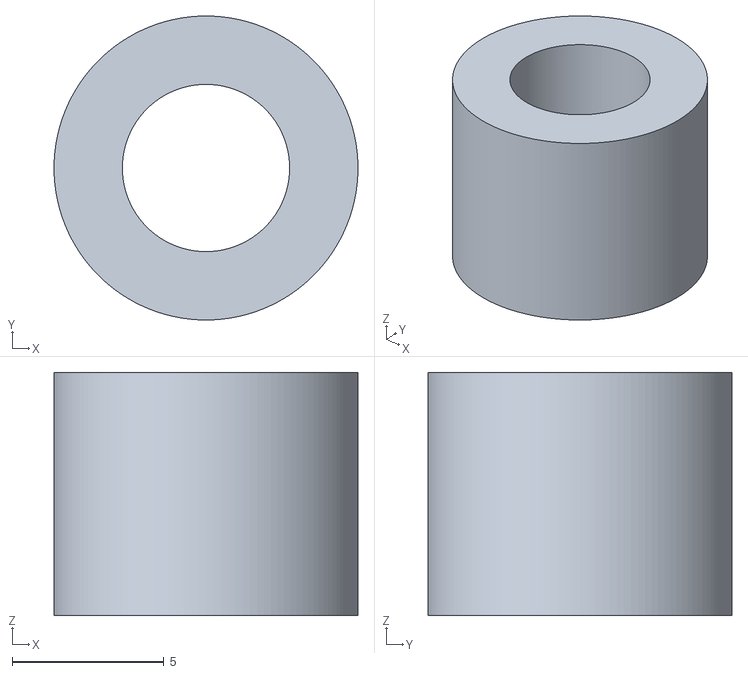
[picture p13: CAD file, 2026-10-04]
engineering/home-print-spacer-01/frame-spacer-h8-od10-id5p5-mm.stl
10.0 x 10.0 x 8.00

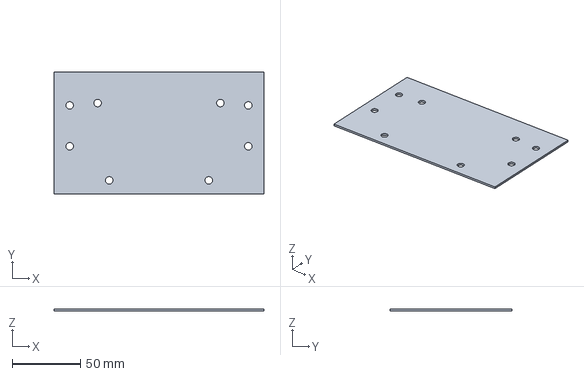
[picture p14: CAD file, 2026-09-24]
engineering/r6-body/engineering/3u60/aluminum/3u60_r6_aluminum_left_right_qty2_mm.step
154.0 x 89.5 x 1.50 mm

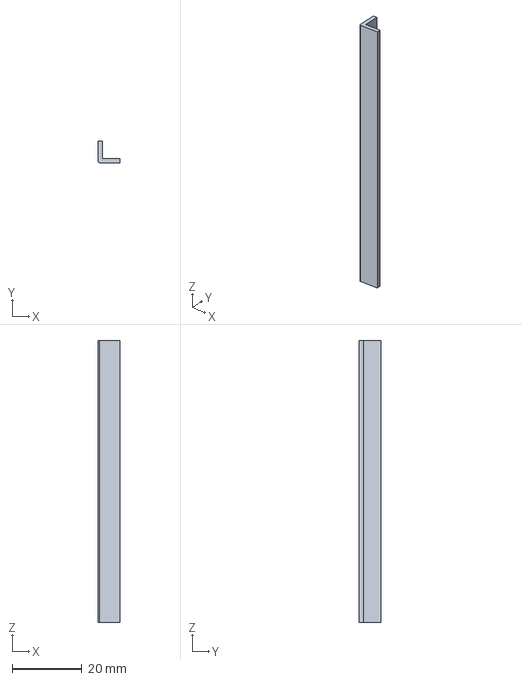
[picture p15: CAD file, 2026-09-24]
engineering/r6-body/engineering/3u60/guards/3u60_r6_t1p2_04_vertical_corner_qty4_mm.step
6.20 x 6.20 x 81.0 mm

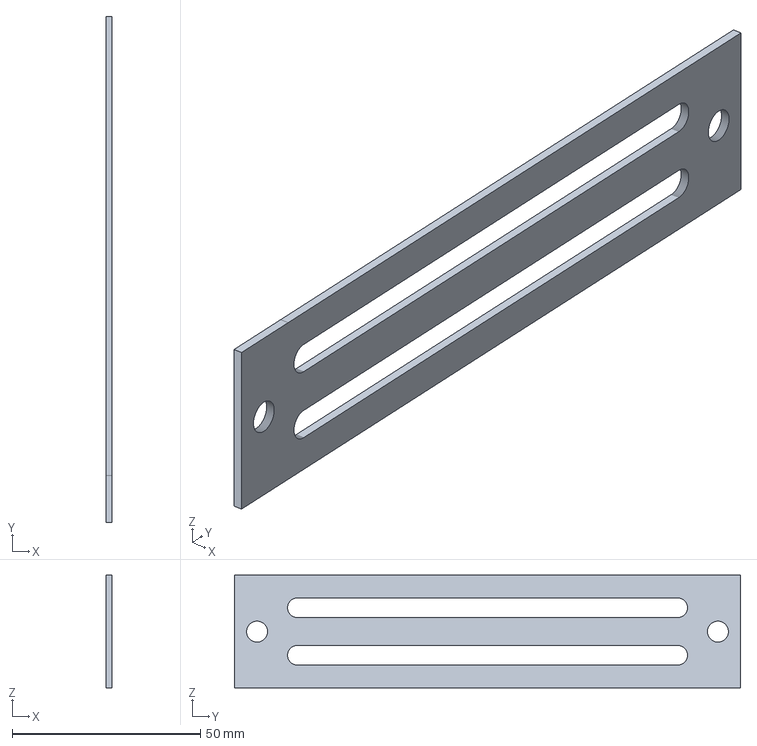
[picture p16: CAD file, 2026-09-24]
engineering/r6-body/engineering/3u60/pcbs/3u60_r6_fixer-1_source_outline_mm.step
1.60 x 134.5 x 30.0 mm

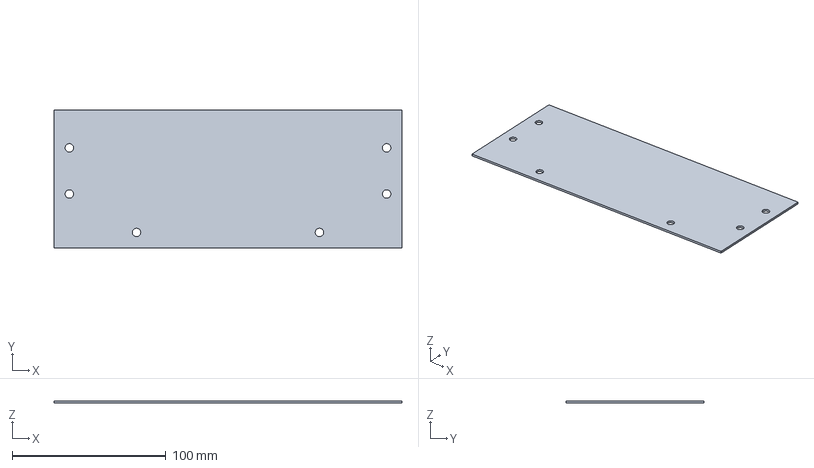
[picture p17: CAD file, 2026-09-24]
engineering/r6-body/engineering/7u40/aluminum/7u40_r6_aluminum_front_back_qty2_mm.step
226.4 x 89.5 x 1.50 mm

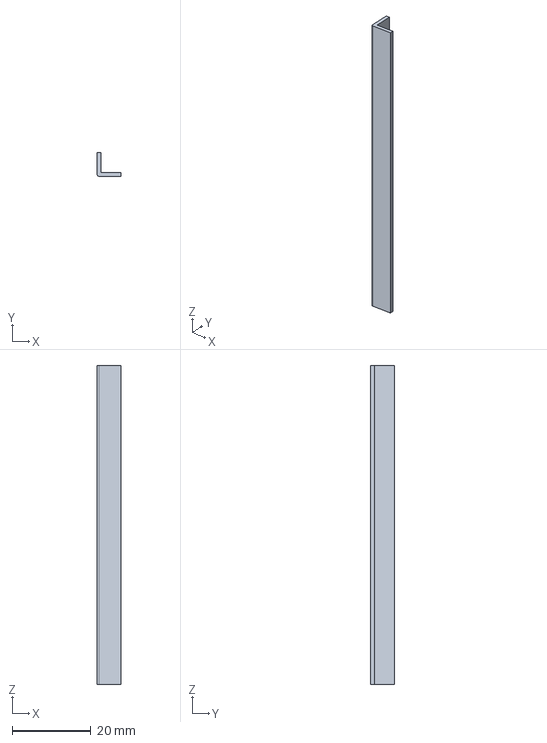
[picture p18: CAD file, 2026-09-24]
engineering/r6-body/engineering/7u40/guards/7u40_r6_t1p0_06_vertical_corner_qty4_mm.step
6.00 x 6.00 x 81.0 mm

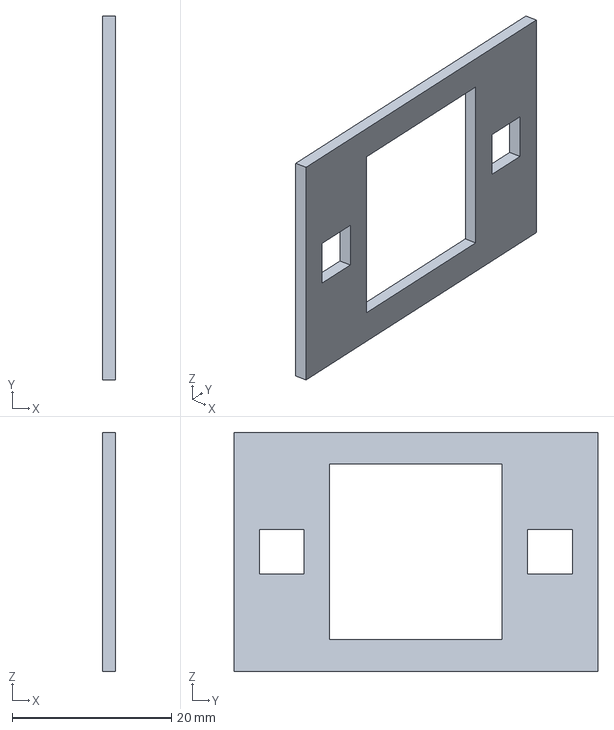
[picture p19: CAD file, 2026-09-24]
engineering/r6-body/engineering/7u40/pcbs/7u40_r6_padder-1-row2_source_outline_mm.step
1.60 x 45.7 x 30.0 mm

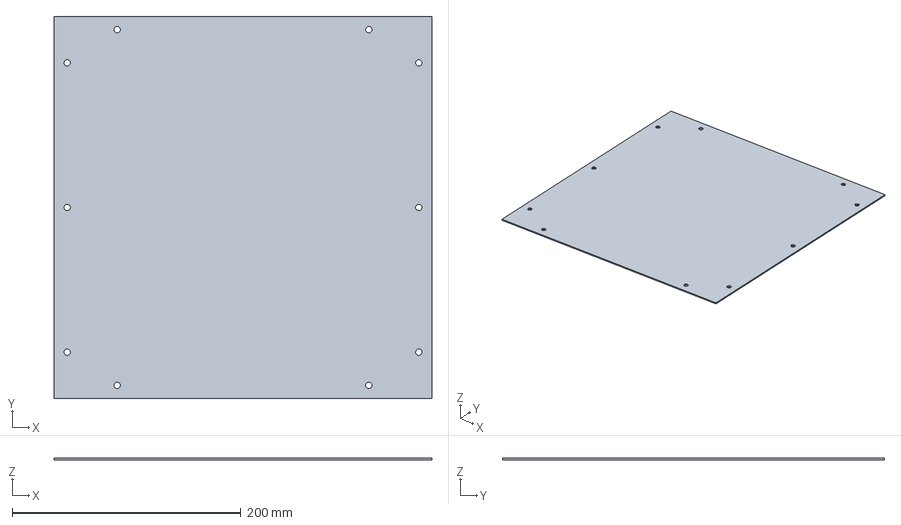
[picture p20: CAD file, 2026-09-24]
engineering/r6-body/engineering/7u60/aluminum/7u60_r6_aluminum_bottom_qty1_mm.step
330.4 x 334.0 x 1.50 mm

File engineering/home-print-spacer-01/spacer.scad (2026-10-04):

// Units: mm. Diameter values are provisional R6 geometry, not measured hardware.
height = 8;
outer_diameter = 10;
bore_diameter = 5.5;
$fn = 128;
assert(height > 0 && outer_diameter > bore_diameter && bore_diameter > 0);
difference() {
    cylinder(h = height, d = outer_diameter);
    translate([0, 0, -0.1]) cylinder(h = height + 0.2, d = bore_diameter);
}

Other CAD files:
engineering/r6-body/engineering/3u60/guards/3u60_r6_t1p0_03_lower_depth_full_qty2_mm.step
engineering/r6-body/engineering/3u60/guards/3u60_r6_t1p2_03_lower_depth_full_qty2_mm.step
engineering/r6-body/engineering/7u60/guards/7u60_r6_t1p0_04_lower_depth_half_a_qty2_mm.step
engineering/r6-body/engineering/7u60/pcbs/7u60_r6_fixer-1_source_outline_mm.step
engineering/r6-body/engineering/3u60/aluminum/3u60_r6_aluminum_bottom_qty1_mm.dxf
engineering/r6-body/engineering/3u60/aluminum/3u60_r6_aluminum_bottom_qty1_mm.step
engineering/r6-body/engineering/3u60/aluminum/3u60_r6_aluminum_bottom_qty1_mm.stl
engineering/r6-body/engineering/3u60/aluminum/3u60_r6_aluminum_front_back_qty2_mm.dxf
engineering/r6-body/engineering/3u60/aluminum/3u60_r6_aluminum_front_back_qty2_mm.step
engineering/r6-body/engineering/3u60/aluminum/3u60_r6_aluminum_front_back_qty2_mm.stl
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

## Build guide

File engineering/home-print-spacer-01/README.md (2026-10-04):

# 家庭用3Dプリンター向け・内側8mmスペーサー

fixer外面とケース側板内面の間に入れる中空円筒。外側の1mm座金とは別部品です。

- 印刷ファイル：`frame-spacer-h8-od10-id5p5-mm.stl`（1個、単位mm）
- 高さ **8mm**、外径 **10mm**、M5用貫通穴 **5.5mm**。
- 3U60：4個。7U40 / 7U60：各10個。スライサーで必要数を複製。
- 高さ8mmは採用済み。内外径はR6の仮寸法を引き継いだ試作値で、現物測定値ではありません。

## 印刷と現物確認

平らな環状面をベッドに置き、穴を垂直にして100%倍率で印刷します。サポートは不要。まず1個を印刷し、実M5ねじが通ること、高さが8mmであること、fixerと側板の間で金具・ねじ頭と干渉しないことを確認してください。穴が縮む場合はスライサーの穴補正か`spacer.scad`の`bore_diameter`を調整します。高さまで変わる全体拡大は避けます。

中実設定（100% infill）を出発点として、スライス後の壁・空洞を確認します。材料・積層条件・締付トルクは未検証。締付後の潰れや時間経過後の緩みを現物で確認してください。家庭印刷する選択はユーザー指定ですが、物理的な嵌合・締付強度・耐熱・運搬試験の合格を意味しません。`engineering/release/`の承認済み製作データには含めません。

## 再生成

Python標準ライブラリだけで生成・検査できます。

```sh
python3 engineering/home-print-spacer-01/build.py
```

`build.py`のHEIGHT / OD / IDを変更すると寸法を変更できます（検査の期待値も合わせて更新）。OpenSCAD用の編集可能な同寸法ソースは`spacer.scad`です。SCADを変更した場合はOpenSCADからSTLを書き出してください。Python生成器とSCADは独立しており、自動同期しません。

`manifest.json`にR6入力とSTL出力のSHA-256、寸法、個数、メッシュ検査結果を記録します。検査は閉じたメッシュ、面の向き、貫通穴の位相、実出力の外形・穴径・体積を確認します。STL自体には単位情報がないため、取り込み時にmmを指定します。

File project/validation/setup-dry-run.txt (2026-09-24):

npx --yes create-zudo-doc@latest <temporary-dir>/zudo-case-doc --preset /mnt/data/zudo-case-doc/setup.preset.json --no-install --no-git --yes

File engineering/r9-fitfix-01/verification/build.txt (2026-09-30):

7u40: Aluminum 5 panels / 3 types / 46 holes exported
7u40: Brackets 18, vertical centers [36.5, 66.5]
7u40: 6 rails, 8 PCB layers, 10 mounting stacks
Build t1p2
Validation t1p2 True []
Build t1p0
Validation t1p0 True []
Coupon C1-01 True
Coupon C1-02 True
Coupon C1-03 True
Coupon C1-04 True
Coupon C1-05 True
Coupon C1-06 True
Coupon C1-07 True
Coupon C1-METAL True
Coupon C2-01 True
Coupon C2-02 True
Coupon C2-03 True
Coupon C4-01 True
Coupon C5-01 True
DONE 154 files; 51 mesh readbacks; passed= True seconds= 58.97
heavy-guard: verdict=PASS exit=0 secs=64 min_mem_mb=9179 reason=-

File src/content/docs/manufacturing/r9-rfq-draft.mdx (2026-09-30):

---
title: "R9アルミ参考見積の未送信文案"
description: "7U40の６枚セットを数量別に比較するための未送信RFQ。"
sidebar_position: 25
---

**旧R9の参考下書き。現行の小型片は[試験片の見積準備](./fit-test-order.mdx)を使う。未送信で、製作開始指示ではない。** 対象はR9-PROTOTYPE-01の7U40候補で、添付は<PreviewLink path="/downloads/candidate/7u40-r9-prototype-01-aluminum-NOT-APPROVED.zip">アルミ６枚の未承認ZIP</PreviewLink>。ZIP内`package-manifest.json`と[版・ファイル表](../design/r9-prototype-01.mdx)で対象版と数量を照合し、送信する場合は空欄を埋める。

## 送信用草案

```text
件名：7U40 R9-PROTOTYPE-01・A5052 t1.5 黒アルマイト平板６枚の参考／試作見積（未発注）

小型電子機器ケースの曲げなし平板について、参考見積／試作見積をお願いいたします。
対象図面版：R9-PROTOTYPE-01（添付package-manifest.jsonとの照合日【＿＿】）
添付ファイル一覧：下記ZIP内のplates/以下のSTEP/DXF各４ファイル（送信前照合【＿＿】）
図面単位：mm
用途：参考見積／試作見積。このメールは製作開始の指示ではありません。

１セットは本体５枚（底１、前後２、左右２）＋蓋天板１枚です。
材質候補A5052、厚さ1.5mm、黒アルマイト。外形と丸穴・長穴は
すべてアルマイト前に加工し、同一図面で合わせてください。
切断後にバリと鋭い端を処理してください。表裏、切断端、穴内面までの
アルマイト被覆範囲と、仕上げ後の長穴寸法への影響を回答ください。

１セット、10セット、50セットは別々の見積条件です。各条件のロット総額と
１セットあたりの額を別々に提示ください。材質、外形/穴加工、端面処理、
アルマイト、段取、検査、梱包、送料、税の内訳と含否を示してください。

外形、穴位置、板厚、平面度の対応可能公差と、仕上げ後の寸法管理を教えてください。
外観の品質、傷防止の梱包、治具跡・色差を許容できる位置も相談したいです。
最小発注数量、納期、見積有効期限、再注文時の条件も回答ください。
A1100等への変更案はA5052とは別案として材質名・価格・条件を提示ください。

図面・条件を確認した後、製作する場合は別途正式に発注します。
```

## 見積の記録欄

| model | revision | quantity | price_basis | tax | shipping | quote_ids |
|---|---|---|---|---|---|---|
| 7u40 | R9-PROTOTYPE-01 | 1／10／50を別行で記入 | ロット総額／１セット額を別欄へ |  |  |  |

１/10/50は代替条件であり合算しない。対象はアルミのみ。PA12、締結材、8mmスペーサー、脚、バンドは別見積。レール/fixer/padderの製造費は今回のケース原価から除外する。現行の未取得額は0円でなく未確定とする。

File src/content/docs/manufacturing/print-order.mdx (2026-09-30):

---
title: "JLC3DP用STLの投入と数量"
description: "本体ガードの旧見積と、最新の３機種・載せ蓋を混同しない。"
sidebar_position: 30
---

7U40の現在の製作候補は[R9未承認ZIP](../design/r9-prototype-01.mdx)に本体ガード、蓋枠、C1/C2/C3試験片がある。試す順番は[小片手順](../verification/fit-test.mdx)。下の表はR6の旧参考データで、R9の数量と混ぜない。R9でもPA12-HP黒染めの接着・反り・保持は未検証。

## 本体ガードの見積用データ

材料候補は**PA12-HP Nylon／Dyed Black**。単位mm、倍率100%。各STLに入っているのは部品１個。ファイル名のqtyまたはmanifestのquantityを注文画面に設定する。

| 機種 | 種類数 | 各種類の数量（ファイル順） | 合計 | 1.2mm見積用 |
|---|---:|---|---:|---|
| 3U60 | 4 | 2 / 4 / 2 / 4 | 12個 | <PreviewLink path="/downloads/reference/3u60-r6-guards-t1p2-NOT-RELEASED.zip">R6 STL</PreviewLink> |
| 7U40 | 6 | 2 / 2 / 4 / 2 / 2 / 4 | 16個 | <PreviewLink path="/downloads/reference/7u40-r6-guards-t1p2-NOT-RELEASED.zip">R6 STL</PreviewLink> |
| 7U60 | 6 | 2 / 2 / 4 / 2 / 2 / 4 | 16個 | <PreviewLink path="/downloads/reference/7u60-r6-guards-t1p2-NOT-RELEASED.zip">R6 STL</PreviewLink> |

標準候補は1.2mm。1.0mm比較案は[データ一覧](../resources/files.mdx)へ。これは見積・嵌合検討の起点であり、保持方法まで承認した製品データではない。

## 画面で記録するもの

材料、染色、数量、寸法、各行金額、合計、通貨、税、送料、日時、ファイルの版とSHA-256を保存する。表の金額が単価か数量込みかも確認する。

R2の過去画面では縦辺が２個で、必要数４個と合っていなかった。R3画面は12個の数量が揃い2,264円だった。今回も数量ミスを防ぐため、注文画面とmanifestを照合する。

## R8版の蓋は未出力

**R8版そのものの製作用STLはない。** R9 7U40の蓋候補は上記にあるが、実物嵌合を確認していない。R7のロック蓋部品を注文しない。

## 造形前の小さな確認

全周の部品を一度に作る前に、ガード端面と蓋の差し込み部を含む短い試験片で確認する方針。R9 7U40のC1/C2/C3候補から選ぶ。旧R7のM3ナット試験片は今回の載せ蓋の嵌合試験には代用しない。

JLC3DPの最低厚さ・公差・追加課金は注文時の公式条件を確認する。過去の単価表から金額を保証せず、今回のデータを実際に投入した表示額を優先する。

参照：[JLC3DP PA12-HP](https://jlc3dp.com/help/article/pa12-hp-nylon)、[嵌合試作](../verification/fit-test.mdx)。

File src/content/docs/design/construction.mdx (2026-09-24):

---
title: "平板５枚と役割分担"
description: "部材の強度、端の保護、取り外しを分ける。"
sidebar_position: 10
---

## 基本構成

底板の上に前後左右の４枚を載せ、左右板の間へ前後板を収める。厚板を凸凹に加工して差し込む旧構造は継承しない。曲げた一体シェルでもなく、平板へ分解できる構造を採用する。

R6・7U40の組立状態

| 部分 | 役割 | 状態 |
|---|---|---|
| アルミ板＋L字ブラケット | 箱を保持する | R6に名目配置 |
| 本体PA12ガード | 切断端・継ぎ目の被覆、外観 | 薄型形状あり。嵌合・固定未確定 |
| レールユニット | モジュールを固定し、一体で取り外す | 実STL/PCBを反映 |
| 蓋＋位置決め段差 | 上部を覆い、横ずれを抑える | R8プレビュー |
| 外周バンド | 運搬時の上方向の抜け止め | 品番・保持力未確定 |

## 接合の数量

縦の４辺には各２個のL字ブラケットを置く。底周囲は3Uで各辺２個、7Uは長い左右辺を各３個とする。合計は3Uで16個、7Uで18個。ブラケット１個を２本のネジで隣接板へ留める前提なので、板接合の締結は32本／36本となる。

前後方向の約8mmは、最も外側へ出るレールユニット輪郭と前後板内面の間の距離である。レール断面だけで測り直さない。

## 仕上げ

アルミは板厚1.5mm、黒アルマイトを現状候補とする。候補材はA5052。国内比較に用いたタカチB2FはA1100Pで、同じ材料の実見積ではない。[アルミの発注条件](../manufacturing/aluminum-order.mdx)で区別する。

ガードが付く部分でも、組立中には端を触るためバリ取りが必要という方針は維持する。ただし必要な丸みや許容傷の数値はまだ定めていない。販売用の見た目と安全な端の状態を、最初の実物サンプルで確認する。

根拠：<a href="/evidence/r6-original-readme.md">R6保存README</a>。数量は[機種比較](../models/comparison.mdx)と[BOM](../manufacturing/bom.mdx)に集約。

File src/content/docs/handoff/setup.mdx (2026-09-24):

---
title: "ローカルでzudo-docを起動する"
description: "公式CLIで土台を生成し、このMDX・資産をそのまま使う。"
sidebar_position: 10
---

## 現在のチェックアウト

このチェックアウトは公式`create-zudo-doc@5.27.0`で初期化済みで、生成されたフレームワーク設定、`package.json`、`pnpm-lock.yaml`を含む。確認に使った環境はNode.js 24.13.1、pnpm 10.30.3。Node.js 22以上を用意する。

新しいチェックアウトでは、リポジトリのルートから次を実行する。

```sh
pnpm install --frozen-lockfile
pnpm check:docs
pnpm check:assets
pnpm test:setup
pnpm build
pnpm dev
```

`pnpm install --frozen-lockfile`は追跡中のlockfileと依存定義が合わない場合に停止する。`pnpm dev`が表示するURLをブラウザーで開く。2026-09-24の初回`pnpm build`は44ページ、41文書ルートと検索項目、47公開資産を生成した。現在はAsset Viewerの画像・図15件と一覧を加え、合計60ページを生成する。

## 文書のみのスナップショットを初期化する場合

`node scripts/setup.mjs`は、公式scaffoldをまだ取り込んでいない文書のみのスナップショットで使う一回限りの補助スクリプト。この初期化済みチェックアウトでは実行しない。公式scaffolderを一時フォルダーで実行し、MDX、設定、画像、設計資料を保護して土台を取り込む。衝突があれば上書きせず停止する。依存導入はscaffold取り込みの後に別途行う。

## バージョンを指定する

scaffolderの指定版は`5.27.0`。別版を試す場合は動作確認した版を明示する。

```sh
ZUDO_DOC_CLI_VERSION=確認したバージョン node scripts/setup.mjs
```

実際のコマンド・生成された依存情報は`.handoff/setup-record.json`へ記録する。npmへの接続が必要なのはローカルの初期化とインストール時。3D単体HTML自体は外部通信なしで開ける。

## 手動で初期化する場合

```sh
pnpm create zudo-doc zudo-case-doc-site --lang ja --no-i18n --no-git --no-install --yes
```

生成先のスターター記事を確認してから、このセットの`src/content/docs/`、`public/`、`zfb.config.ts`を移す。`engineering/`、`project/`、`AGENTS.md`は作業資料として同じリポジトリへ入れる。既存サイトへ混ぜる場合はセットアップスクリプトを使わず、記事と設定を意図的に統合する。

## 表示確認と公開前の注意

2026-09-24のChrome 146.0.7680.153でdesktop 1440×900、narrow 390×844を確認した。41文書ルートと8カテゴリが両幅で表示され、narrowでは横はみ出しがなかった。検索・テーマ・画像・R8/R6プレビューの操作も確認済み。経路別の結果、非空ダウンロード、画面記録はリポジトリの`project/browser-validation.md`にまとめる。ビルドやブラウザーの表示確認は、嵌合・強度・運搬などの現物試験を代替しない。

Cloudflareでは`zudo-case.zudolab.dev`を文書・Asset Viewer・根拠ファイルに、`zudo-case-preview.zudolab.dev`を単体プレビュー・参照/旧版ZIPに使う。`pnpm build`後に`pnpm prepare:worker-assets`を実行して２つの配信フォルダーを作る。GitHub Actionsは`main`へのpushでプレビュー、文書の順にデプロイする。`noindex`は有効にしているが、アクセス制御ではない。旧ソースZIPや見積画像もURLを知る人は閲覧できる。

このセットはルートパス配信を想定。サブパス配信に変える場合は、iframeと画像/ダウンロードのURLも確認する。

公式：[Installation](https://zudo-doc.takazudomodular.com/docs/getting-started/installation/)、[CLI](https://zudo-doc.takazudomodular.com/docs/reference/create-zudo-doc/)、[設定API](https://zudo-doc.takazudomodular.com/docs/guides/configuration/)。

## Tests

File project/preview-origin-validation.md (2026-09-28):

# プレビュー配信元分離の確認記録

確認日: 2026-09-29
対象: Issue [#70](https://github.com/Takazudo/zudo-case/issues/70)、統合済み revision `e6f275cbe03f03564fcb0266fadbbf13e3328067`
目的: Issue #69 の実行単位ごとの配信元分離を、実ブラウザーと production 出力で確認する。

## 実ブラウザー

マネージャーが隔離された作業ツリーで既定値の `dev` を起動し、同じプロセスを稼働させたまま `check` と `build` を実行した。Playwright の実ブラウザーでプレビュー文書を再読込し、さらに MDX を一時編集して再コンパイルした後も、表示元キャプションは `表示元: ローカル (public/)`、iframe とプレビューリンクは `/previews/r8-simple-lid.html` の相対 URL を保った。

`public/previews/r8-simple-lid.html` に一時マーカーを入れ、実際の iframe 内に表示されることを確認した。確認時のスクリーンショットではマーカーとR8ケースのプレビューを視認できた。モデルページから取得した参照 ZIP は25,994 bytesで、ブラウザー取得物と `public/` 内ファイルの SHA-256 がともに `b50eb1140197d742d00b8192d7e9ad1750a4617422b8713ca3eb2e55f1e6d5eb` だった。

既定 `dev` を動かしたまま、`http://127.0.0.1:8787` を指定した2つ目の `dev` も起動した。指定先は2つ目の表示にだけ反映され、既定 `dev` はローカル表示を維持した。production build の文書は `https://zudo-case-preview.zudolab.dev` を参照し、ローカル override は含まれなかった。マーカーと MDX の一時変更は確認スクリプトの `finally` で元に戻され、作業ツリーの検査でも差分はなかった。

## チェック結果

- `node --test tests/preview-links.test.mjs tests/preview-origin-isolation.test.mjs`: 8/8 pass。
- `node scripts/check-docs.mjs`: 41 MDX、8カテゴリ、124内部リンクを確認。
- `node scripts/sync-reference-tables.mjs --check`: 生成ページと `project/current-spec.json` が一致。
- マネージャーによる `.github/workflows/check.yml` 相当の全工程を heavy guard 下で実行: `verdict=PASS exit=0 secs=23 min_mem_mb=10736`。資産241件のハッシュ、setup 7件、ledger 97件、実 `check` と TypeScript、fixture 21件、60ページの production build、built-preview-links（41文書中13 URL）、大容量資産2件の準備、Worker系テスト9件を通過。

補助ログとスクリーンショットはローカル Git 管理領域の `.git/agent-logs/sweep-260929/verification/`、全工程ログは `.git/agent-logs/sweep-260929/full-check.log` にある。スクリーンショットを視認した。これらのログは配布物ではないため、本記録には判定に必要な観測値を残した。

## 範囲と限界

この確認が示すのは、実行単位ごとのプレビュー参照先とローカル資産の表示が維持されること、および指定された文書・ビルド検査の結果である。筐体の嵌合、強度、落下、疲労、荷重、製造適合性は評価していない。CAD、価格、製造承認状態の変更はない。

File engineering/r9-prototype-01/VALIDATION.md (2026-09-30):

# R9-PROTOTYPE-01 検証集約

**状態:** passed_with_flags / 製作承認: なし

**集計:** pass 156 / flag 14 / fail 0
**対象:** 7u40 / mm / R9候補データ

## 確認結果

- 本体平板: 5枚、蓋板: 1枚。
- 穴テーブル: 46件 (長穴 36、丸穴 10)。
- R9生成STL: 56件をSTEP再取込形状と照合。
- STEP: 64件、DXF: 17件を再取込。
- パラメーター変更: 2ケースを一時コピーで再生成。
- R6元レールSTLはR9生成物ではないため、R9 STLの閉じたメッシュ検査から除外。

## フラグ

- stl:out/hardware-envelopes/7u40-r9-hw-case-mount-bolt-qty10-mm.stl: Reference/display STL has a recorded mesh limitation; its STEP BREP remains the geometry source of truth.
- stl:out/hardware-envelopes/7u40-r9-hw-foot-qty4-mm.stl: Reference/display STL has a recorded mesh limitation; its STEP BREP remains the geometry source of truth.
- stl:out/hardware-envelopes/7u40-r9-hw-inner-spacer-qty10-mm.stl: Reference/display STL has a recorded mesh limitation; its STEP BREP remains the geometry source of truth.
- stl:out/hardware-envelopes/7u40-r9-hw-panel-joint-bolt-qty36-mm.stl: Reference/display STL has a recorded mesh limitation; its STEP BREP remains the geometry source of truth.
- stl:out/hardware-envelopes/7u40-r9-hw-rail-end-bolt-qty12-mm.stl: Reference/display STL has a recorded mesh limitation; its STEP BREP remains the geometry source of truth.
- stl:out/hardware-envelopes/7u40-r9-hw-washer-1mm-qty46-mm.stl: Reference/display STL has a recorded mesh limitation; its STEP BREP remains the geometry source of truth.
- stl:out/hardware-envelopes/7u40-r9-pcb-fixer-qty2-mm.stl: Reference/display STL has a recorded mesh limitation; its STEP BREP remains the geometry source of truth.
- hardware-envelope-stl-scope: Hardware-envelope and source-derived PCB STLs are assembly/display references, not manufacturing candidates; each is still listed and checked against its STEP geometry.
- source-rail-stl-exclusion: The 40HP rail mesh is saved R6 source geometry, not an R9-made STL; source identity is checked separately.
- s2-slot-bearing-coverage: The provisional 10 mm washer does not meet nominal bearing overlap at current wall slots; larger OD remains a candidate.
- s4b-static-interference-coverage: Assembly collision coverage is partial; untested pair classes remain.
- s4b-lift-path-coverage: Lift-path checks cover limited BREP and envelope classes, not all actual assembly solids.
- s4b-physical-fastener-access: M3/M5 driver access and physical washer fit are not validated.
- s4b-band-contact-and-deflection: Straps are schematic; plate-only contact and deflection remain unresolved.

## 参照メッシュの詳細

- 参照包絡STLのSTEP境界との差は最大 0.001862 mm。厳密照合値は 0.0001 mm、STL書出しの弦誤差許容値は 0.01 mm。
  - out/hardware-envelopes/7u40-r9-hw-case-mount-bolt-qty10-mm.stl: 0.001400 mm
  - out/hardware-envelopes/7u40-r9-hw-foot-qty4-mm.stl: 0.001556 mm
  - out/hardware-envelopes/7u40-r9-hw-inner-spacer-qty10-mm.stl: 0.001561 mm
  - out/hardware-envelopes/7u40-r9-hw-panel-joint-bolt-qty36-mm.stl: 0.001862 mm
  - out/hardware-envelopes/7u40-r9-hw-rail-end-bolt-qty12-mm.stl: 0.001405 mm
  - out/hardware-envelopes/7u40-r9-hw-washer-1mm-qty46-mm.stl: 0.001561 mm
- out/hardware-envelopes/7u40-r9-pcb-fixer-qty2-mm.stl: 閉じたメッシュではありません。辺出現数 {"1": 20, "2": 18950, "6": 4}。R6由来輪郭を用いた表示用包絡で、製作用PCBデータとして扱いません。

## 未検証

- FEA, load capacity, or strength under service loads.
- Fit with real materials and manufacturing tolerances.
- Guard adhesion, retention, and pull-off strength.
- The effect of anodizing thickness on fit.
- Drop resistance and fatigue life.
- Band tension, strap load strength, and lid deflection during transport.
- Actual module knob heights and cable clearance (G05).
- Actual hardware, fastener, washer, and driver fit (G06).
- Physical assembly and transport trial (G11).
- Body plate and internal part solid-pair collision coverage: body plate STEP patterns are local and most repeated hardware has only instance AABBs; intentional fastener contacts need pair-specific exclusions.
- Lift path exact solids against body, PCB, rail, brackets, hardware and actual module knobs; locator AABBs against available component AABBs are a conservative 1 mm lift-step screen, not exact solids.
- M3 driver cone/tool access: eight plate/frame bores are modeled, but driver and screw heads are not specified.
- M5 physical tool access and washer fit; S2 exterior envelope is nominal only.
- Adhesive retention, physical fit, strap load strength, module knob/cable envelope and transport testing.

CAD再取込・メッシュ検査・名目配置チェックは、現物の嵌合、材料、強度、接着、運搬の結果を示しません。
すべての詳細は同じフォルダーの out/validation.json を参照してください。

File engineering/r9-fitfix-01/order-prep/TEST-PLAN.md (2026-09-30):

# 小型試験片：到着後の確認手順

状態：未実施。以下は探索試験の手順と次工程への判定案で、強度規格や製造承認ではない。

## 用意するもの

寸法を測れるノギス（分解能・精度を記録）、薄板用の測定器、直角を保持できる治具、当て木／小型クランプ、実在庫L字ブラケット、試すM5ネジ・座金・ナット、実際の工具。C2のM3ネジ・ナットも実寸確認後に用意する。ねじ長・座金径・接着剤は未選定で、CADの模式値から購入品番を決めない。

C4/C5は接合穴を持たない局部試験片。直角治具で、実ケースと同じ「底板上に立板」「左右板が前後板を挟む」配置を保持する。ガードを治具代わりにして板位置を決めない。ガードの接触面や屋根／底面にテープを挟んで位置合わせしない。

## 1. 受入と乾式の確認

1. 部品ID・製造ロット・使用ファイルSHA-256を記録。仕上げ後のアルミ板厚を複数位置で測る。バリ・反り・欠け・造形文字を観察し、欠けた文字は袋のIDで識別する。
2. 各C1の主要壁・チャネル幅を測る。片側候補空間はC1-01=0.30、02=0.25、03=0.40、04=0.15、05=0.30mm。C1-05だけ肉厚1.0mm、他は1.2mm。屋根を板上端へ当てた乾式状態で、無理なこじりなしに入るか、完全着座するか、割れ・白化・板の傷を記録する。
3. C1-06は19.75mm×2片＋0.5mmの継ぎ目、C1-07は20mm×2片で名目継ぎ目0。実際の隙間・段差・露出した金属端を記録。0mmの候補を押し込んで隙間を消さない。
4. C4は床と立板に対する下辺Lカバー、C5は２立板に対する上端角を確認する。板同士の位置を固定したまま、屋根／底フランジが座り、内側返しが金属へ突き当たらないことを観察する。
5. C2の共通壁・ガード・天板を使い、フレーム01=0.7、02=0.5、03=0.9mmの位置決め隙間を順に比較する。各10回の着脱を探索条件として記録。屋根と蓋の座面が当たり、こじり・引掛かり・割れがないか確認する。M3組立は実ナットがポケットに収まり、ネジが底突きしないことを先に確認する。

JLC3DPの公開公差は100mm以下で±0.3mm（2026-09-30確認）。比較差より大きい場合があるため、ID順の公称値だけで優劣を判定しない。実測値と挙動が対応しない場合は、同じ条件の複製／追加片を注文して再確認する。１ロット１片の成功で公差を確定しない。

## 2. C3を追加した場合

在庫金具１個と実締結材を使い、底・壁の２枚を組み合わせる。01/02/03で同じ金具と工具を順に使う。締付前の実際の可動範囲、穴ずれ吸収、両面座金の受け面、締付後のずれ、工具アクセスを記録する。ネジ径による隙間と長穴の設計移動量を混同しない。締付トルクは実締結材の仕様で決め、任意のトルクを合格値にしない。

C3は下辺１接合の局部試験で、全ての角・レール付近・隣接ガードとの工具干渉を検証しない。03丸穴は対照で、長穴方針の変更ではない。

## 3. 接着保持は乾式確認の後

先に全ての乾式比較を済ませ、共用アルミ片を接着で消費しない。実測した側面空間、黒染めPA12とアルマイトへの適合、接着層厚、表面処理と養生条件が合う製品を、そのメーカー資料で選定する。0.15mmテープを自動的な正解にしない。複数接着剤を比べる場合は、必要なアルミ／PA12の追加個数を別計上する。

接着後は品番、ロット、前処理、充填範囲、養生温度と時間、接着層厚を記録。屋根と底フランジの直接支持面を変えない。手作業で剥がれないことだけでは運搬荷重の保証にならない。保持力の数値基準・試験荷重はまだ未設定として残す。

## 次工程へ進む条件

実測寸法と乾式挙動が説明でき、破損・強制組立がなく、採用する接着／締結構成を現物で確認してから１台の試作を検討する。長部品の反り・全体の嵌合・実ノブ・バンド荷重・運搬は、その１台で別途確認する。小型片の成功を全体承認にしない。

結果は同梱の `FIT-RECORD.md`（リポジトリでは `../handoff/FIT-RECORD.md`）に記入し、C3の受け面・工具の写真も追加する。

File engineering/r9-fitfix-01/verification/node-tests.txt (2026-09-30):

✔ fitfix check rejects changed CAD, public copy, generator, parity and active designation without writing (1853.340458ms)
✔ the current three models match their plate geometry (0.996875ms)
✔ bottom width mismatch reports model, plate, and axis (0.369541ms)
✔ front and back plate height mismatch fails (0.61625ms)
✔ one plate thickness mismatch fails (0.242917ms)
✔ a missing role fails with the expected plate identity (0.171125ms)
✔ a duplicate role fails (0.19675ms)
✔ a non-finite plate dimension fails (0.157458ms)
✔ a negative plate dimension fails (0.361583ms)
✔ plate array order does not affect role matching (0.393833ms)
✔ unexpected role quantity fails (0.394ms)
✔ R9 ledger registers every CAD output, candidate package, and preview from the output manifest (6.668459ms)
✔ the saved R9 candidate state passes ledger checks without approving production (440.507167ms)
✔ the R9 artifact manifest includes all output files and the self-excluded output manifest (3.220375ms)
✔ current state passes (13.928417ms)
✔ evidenced quote and matching total pass (12.583375ms)
✔ synthetic total without qualifying record fails (6.961958ms)
✔ assistant estimate cannot justify current total (10.077667ms)
✔ quote scope mismatch fails (13.209167ms)
✔ selected disjoint quotes with matching conditions and coverage note pass (13.958916ms)
✔ selected quote quantity mismatch fails (13.627667ms)
✔ selected quote tax_status mismatch fails (9.279083ms)
✔ selected quote price_basis mismatch fails (15.182375ms)
✔ selected quote shipping_included mismatch fails (12.781375ms)
✔ unselected competing quote is excluded from total (15.186125ms)
✔ unknown selected quote_ids fails (8.639625ms)
✔ duplicate selected quote_ids fails (9.633583ms)
✔ historical selected quote_ids fails (14.754334ms)
✔ estimate selected quote_ids fails (13.939083ms)
✔ selection rejects wrong component (17.845791ms)
✔ selection rejects invalid current record (8.163208ms)
✔ selection rejects wrong model set (21.006875ms)
✔ duplicate record id including historical record fails (12.425834ms)
✔ null total permits valid unselected quotes and absent or null scope (19.229584ms)
✔ multi-quote selection without coverage note fails (13.82225ms)
✔ multi-quote selection without duplicate part fails (20.104125ms)
✔ both model and models in record fail (11.602458ms)
✔ both model and models in scope fail (11.699458ms)
✔ model sets match regardless of order or singular representation (10.271541ms)
✔ current record requires valid id (18.836042ms)
✔ current record requires valid price_basis (12.687375ms)
✔ current record requires valid quantity (15.818834ms)
✔ current record requires valid tax_status (5.515083ms)
✔ current record requires valid shipping_included (9.236375ms)
✔ non-null scope requires valid quantity (7.366584ms)
✔ non-null scope requires valid price_basis (10.569083ms)
✔ non-null scope requires valid tax_status (6.447959ms)
✔ non-null scope requires valid shipping_included (6.176833ms)
✔ non-null scope requires valid quote_ids (8.655833ms)
✔ non-null scope requires valid quote_ids (9.222833ms)
✔ non-null scope requires valid quote_ids (19.846834ms)
✔ lid uses explicit selection and condition matching (10.645666ms)
✔ band uses explicit selection and condition matching (9.635ms)
✔ unapproved candidate passes with verified hash (31.117167ms)
✔ null current lid designation passes (22.521291ms)
✔ invalid current lid designation path string fails (15.175209ms)
✔ invalid current lid designation number fails (3.811042ms)
✔ unregistered current lid candidate ID fails (10.31075ms)
✔ valid unapproved lid designation may reference plate and frame candidates (12.60575ms)
✔ lid model sets match across order and singular/array representations (14.173833ms)
✔ current lid candidate with wrong model fails (7.571291ms)
✔ current lid candidate with wrong revision fails (6.715125ms)
✔ current lid candidate with wrong component fails (5.919833ms)
✔ empty current lid candidate_ids fails (3.136917ms)
✔ duplicate current lid candidate_ids fail (5.499333ms)
✔ current lid candidate_ids rejects empty string (3.289583ms)
✔ current lid candidate_ids rejects nonstring (3.519458ms)
✔ duplicate candidate file IDs fail (10.057125ms)
✔ designated lid candidate still requires its registered file hash (5.693833ms)
✔ both model fields in candidate metadata fails (6.367ms)
✔ unknown model in candidate metadata fails (6.204625ms)
✔ nonstring model in candidate metadata fails (5.303083ms)
✔ empty candidate ID fails (6.630417ms)
✔ nonstring candidate ID fails (5.849208ms)
✔ ID-bearing candidate requires a non-empty string component (4.942209ms)
✔ ID-bearing candidate requires a non-empty string component (4.689417ms)
✔ ID-bearing candidate requires a non-empty string revision (5.01675ms)
✔ ID-bearing candidate requires a non-empty string revision (6.098917ms)
✔ current lid designation with both model fields fails (3.996583ms)
✔ current lid designation with unknown model fails (5.1705ms)
✔ ID-bearing candidate requires component (5.897833ms)
✔ ID-bearing candidate requires model (8.210083ms)
✔ ID-bearing candidate requires revision (7.956375ms)
✔ lid designation does not permit an unlisted engineering release file (7.184958ms)
✔ lid designation without an approval record cannot approve production (6.508583ms)
✔ approval without approval record fails (2.710583ms)
✔ approval with open G item fails (7.435417ms)
✔ unlisted release file fails (4.512333ms)
✔ release gate disagreement fails (3.309291ms)
✔ complete approval with matching ledgers and closed evidenced gates passes (23.700542ms)
✔ closed G item without actual evidence fails (4.421458ms)
✔ nested release file not listed fails (5.189083ms)
✔ candidate hash mismatch fails (10.231083ms)
✔ lid and band prices each require their own matching quote (6.088333ms)
✔ synced generated pages pass --check (118.7145ms)
✔ CLI through a symlinked directory runs and detects drift (185.325542ms)
✔ a ledger-only change fails --check and names affected pages (115.766291ms)
✔ a hand-edited generated page fails --check (125.3255ms)
✔ --check leaves fixture content and mtimes unchanged (93.15ms)
✔ missing generated pages fail --check (61.941041ms)
✔ regeneration restores a passing --check (153.608625ms)
✔ fresh run stages complete output; rerun verifies and changes no bytes (303.654959ms)
✔ missing chunk rejects rerun without changing live output (287.592292ms)
✔ generation mismatch rejects rerun without changing live output (191.356833ms)
✔ verified live output allows stale staging and backup cleanup (135.109625ms)
✔ partial input preserves previous output (182.990833ms)
✔ unrouted oversize rejects before writing (47.782417ms)
✔ after-stage rolls back to the previous good generation (249.0455ms)
✔ after-preview-backup rolls back to the previous good generation (286.171834ms)
✔ after-manifest-backup rolls back to the previous good generation (241.074375ms)
✔ after-generation-backup rolls back to the previous good generation (210.43ms)
✔ after-preview-publish rolls back to the previous good generation (198.74575ms)
✔ after-manifest-publish rolls back to the previous good generation (192.773875ms)
✔ after-generation-publish rolls back to the previous good generation (236.248417ms)
✔ production, dev, and override origins (0.65775ms)
✔ missing markdown, frame/component, and generated preview targets fail (15.15925ms)
✔ per-run config preserves definitions and resolves the canonical build output (97.353667ms)
✔ live dev rereads its local origin after check (712.019ms)
✔ live dev rereads its local origin after build (442.977167ms)
✔ two live same-mode runs retain distinct overrides on reread (542.918708ms)
✔ override validation fails before a CLI or run directory is created (57.268584ms)
✔ dev mirrors source edits, additions, removals and config into its own run only (908.031625ms)
✔ R9 manifest check accepts matching outputs and rejects a changed byte (33.958083ms)
✔ mock scaffold: framework only; preserve MDX/config/assets; use generated versions (83.568ms)
✔ setup provenance records the pinned CLI without temporary or machine paths (97.102625ms)
✔ post-install record captures exact versions and lockfile hash (114.978292ms)
✔ collision is detected before copying (42.2585ms)
✔ already integrated project is not overwritten (52.8ms)
✔ non-zudo-doc input is rejected (37.511083ms)
✔ copy failure rolls back newly copied paths and package (103.888125ms)
✔ streams a full body and matches the local byte count and SHA-256 (38.090375ms)
✔ same-length altered body fails by SHA-256 (18.345208ms)
✔ short 200 body fails by byte count (14.918959ms)
✔ long 200 body fails by byte count (15.262083ms)
✔ HTTP 404 fails as a retryable status failure (25.158709ms)
✔ body cut mid-stream fails as a retryable transport failure (26.412167ms)
✔ origin validation rejects credentials, paths, queries, and fragments (0.310709ms)
✔ deployed report records both full-body checks and their evidence scope (29.025209ms)
✔ deployment outputs have separate audiences and stay under the asset size limit (42.543708ms)
✔ large /previews/r6-body.html streams the original bytes (87.369167ms)
✔ large /downloads/archive/r7-m3-lid-source.zip streams the original bytes (56.126709ms)
✔ small fixture asset streams every chunk and preserves its manifest metadata (16.807ms)
✔ missing first chunk rejects the asset body (0.812667ms)
✔ missing later chunk rejects the asset body (0.653208ms)
✔ short chunk rejects the body when its final byte count differs from the manifest (0.90675ms)
✔ same-length altered chunk streams and differs from the manifest SHA-256 (0.377458ms)
✔ HEAD returns manifest metadata without fetching any chunks (0.150167ms)
ℹ tests 147
ℹ suites 0
ℹ pass 147
ℹ fail 0
ℹ cancelled 0
ℹ skipped 0
ℹ todo 0
ℹ duration_ms 2841.474208
heavy-guard: verdict=PASS exit=0 secs=3 min_mem_mb=9457 reason=-

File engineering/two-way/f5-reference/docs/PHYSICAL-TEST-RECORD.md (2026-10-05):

# F5 physical test record — blank / not performed

This file is a record template. No test below has been performed by this prototype package.

Date: __________  Operator: __________  Family: A / B / C  Source commit: __________
Actual source part / fabrication revision: __________  Module dummy masses, base / lid: __________

| Measurement | Nominal study | Actual / result |
|---|---|---|
| Rail length | 305 mm (60HP) / 204 mm (40HP) | |
| Padder / fixer thickness | 1.6 / 1.6 mm | |
| Frame outside width | 311.4 / 210.4 mm | |
| Side spacer / external washer | 8 / 1 mm | |
| 3U PCB assembly maximum own depth | 30 mm | |
| 7U fixer maximum own depth | 60.015381 mm | |
| Frame rear reach from panel front | 31.900247 mm (3U); 61.950925 mm (7U) | |
| Lid rear depth | 48 mm (A/B); 70 mm (C) | |
| PCB to inside lid back clearance | 14.599753 mm (A/B); 6.549075 mm (C) | |
| B gap between independent 3U frame boards | 1 mm | |
| Collar inner tongue to source side frame | 2.4 mm at default inputs | |
| Frame mounting bolts and source slot fit | Exact hardware not selected | |
| Bolts, nuts, cover cavities and tool access | Unverified | |
| Power board, wiring and module back clearance | Unverified | |
| Real relaxed plugged-cable/knob height | 72/58 mm front-gap studies only | |

Record interference and failures, not just pass/fail. Do not force a part past a collision, tighten onto controls, or let leads support a tray. Restrain dummy loads against falling before handling and stand tests. Establish an appropriate test procedure and acceptance criteria for the actual assembled weight; no load/drop rating is supplied by this template.

Supporting photos / measurements / observed deflection: __________
Required changes: __________
Physical fit approval by owner: __________ (blank means not approved)

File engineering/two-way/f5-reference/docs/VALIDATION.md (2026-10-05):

# F5 validation record

2026-10-05 · **Software and nominal geometry only; not manufacturing approval.**

## Final checks

| Check | Result | Evidence |
|---|---:|---|
| Node source / frame / geometry suite | 117 passed, 0 failed | `tests/frame-results.tap` |
| Offline Chromium UI and responsive suite | 69 passed | `tests/browser-results.json` |
| GLB export and reload | 6 of 6 bounds and geometry-group comparisons passed | `models/manifest.json` |
| Final reference renders | No JavaScript errors | `previews/preview-render.json` |

Commands are in the root README. The final HTML was built with all three preview thumbnails embedded. Browser checks made no HTTP(S) requests. The tested renderer was the **software Canvas renderer**; WebGL was unavailable and its rendering path was not exercised.

The numerical suite verifies byte-identical Git blob identities for the two rail JSON copies, all source rail vertices and triangles, rigid transforms, PCB outside dimensions and layer thicknesses, source mounting datums, A/B/C component counts, the unchanged 7U board's old-48-mm lid failure, the new 70 mm C lid clearance, nominal locator clearances, finite geometry in eight views, configured closed envelopes, stand packing and export provenance. It also verifies the retained distinction between independent poses and a solved opening motion.

The browser suite exercises all three families and eight views, the side-layer separation control, the C lid error/recovery, display toggles, camera controls, keyboard orbit, expanded view, JSON save/load and rejection of the old F4 schema, PNG export, and page widths 320, 390, 768, 1200 and 1600 pixels. It checks visible warnings for inadequate patch clearance, removed retention straps and undersized trunk inputs.

The six GLBs are one source-frame inspection and one playing arrangement for each family. Reload comparisons check scene bounds and geometry-group counts. They do not establish watertightness, manufacturability or structural correctness.

## Known limitations

The exact source rail meshes retain the upstream duplicated/non-manifold surfaces. PCB outer vertices, mounting datums and padder coordinates follow the source, but rounded fixer cutouts are display approximations. Most hardware, protective covers and the tray's final bores remain schematic. Tests compare the geometry that is actually modeled, not unspecified future hardware.

There is no physical load, drop, retention, stability, thermal or electrical test. There is no complete continuous interference sweep, fixed-length cable simulation or validation that the purchased hinges fold the mounted spacer profiles flat. Numeric fit checks do not incorporate manufacturing tolerances, PCB bow, actual module protrusions or tool access.

`docs/archive-F4/` is historical background. Its dimensions and test counts do not apply to F5. No GitHub repository was modified.

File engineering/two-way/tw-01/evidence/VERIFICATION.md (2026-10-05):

# TW-01 検証記録 — 2026-10-05

対象: epic #106、実装順 #107 → #108 → #109 → #110 → #111。基準 main は `6a13d80d816b0247ab9eee761c29c1fb786b76cc`。実機開発 #112、R9 #102、フレームワーク移行 #105 は別管理。製造承認・発注・デプロイ・マージは行っていない。

## 原本と維持ソース

受領した `zudo-case-prototype-F5.zip` は SHA-256 `2060f83d75c93c7e5a29e6fe0751ac1fae101dccba8c7bf08d2a43080f7b4e58`、5,574,131 bytes。原本の読みやすい最小ビルド集合は `engineering/two-way/f5-reference/SOURCE-RECEIPT.json`で個別照合する。再構築したファイルを原本とは表示しない。

原本の使い捨てディレクトリーで HTML を再生成し、原本 HTML と SHA-256 `833eb36f5a18e4cec5135eb1e804069e6028b947187a0621f28d42d4628b2915` が一致。原本数値回帰117件のログは `original-F5-baseline.tap`。この117件は原本確認であり TW-01 納品数ではない。

TW-01 は canonical R6 PCB 全外周／切欠きと原寸レールを読み取り、1.6 / 1.6 / 8 / 1 mm の積層を保持。B の独立3U×2＋1 mm、C の全7U＋70 mm、両トレー原寸フレームを検査。C を48 mm蓋に戻す負例はクリアランス −15.450925 mm、70 mm は +6.549075 mm。物理ゲートは全て未測定のまま。

## 実行環境

Linux x86_64、Node 24.19.0、Python 3.12、pnpm 10.30.3（既存CIと同じ系列）。canonical conversion は `uv sync --frozen` の固定依存を使用し、変換結果を保存済み frame-data.js とバイト比較した。

Playwright 1.58.2、Chromium 133.0.6943.0（`@sparticuz/chromium@133.0.0`）、Noto Sans CJK JP。標準 Playwright browser CDN はアーカイブが途中で切れたため、npm 配布 Chromium を利用した。WebGL は実際の WebGL context と ANGLE/SwiftShader で実行しており、物理GPUでの検証とはしない。

## TW-01 自動検査

- `node --test engineering/two-way/tw-01/tests/*.test.cjs`: **142 / 142 pass**、0 skip。`tw-01-tests.tap`。原本117件を TW ソースへ適用する数値回帰に加え、canonical source・全15設定・安全なimport・成果物検査を含む。
- `node engineering/two-way/tw-01/build.cjs --check`: 29生成物に差分なし。独立した2回の生成が全バイト一致。
- ソースZIPを空ディレクトリーへ展開し、親Nodeテスト環境を分離し、原本receiptを含む24契約テストの実行（0 skip）とビルドを確認。出力がリポジトリからの生成物と全バイト一致。
- 6 GLB をバイナリから再読込し、メートル/Y-up変換後の頂点境界をresolverの期待値と照合。manifestのSHA-256とサイズを全成果物で照合。最大ファイルも25 MiB未満。
- `scripts/prepare-frame-data.py` の再変換が保存結果と一致。既存R6ソースは変更していない。

## ブラウザー（別々に記録）

| 検査 | 結果 | 証拠 |
|---|---|---|
| software rasterizer | 56 pass | browser-software.json / software-390.png |
| WebGL / SwiftShader | 56 pass | browser-webgl.json / webgl-B-play.png / webgl-C-invalid48.png |
| ネイティブ文書・preview origin・準備済みHTTP成果物 | 36 pass | browser-integration.json / docs-390.png |

オフライン file:// でA/B/C全8姿勢、原寸／分解フレーム、接合部、表示切替、カメラ、キーボード、拡大表示のフォーカス／Escape、320/390/768/1200/1600 pxおよび高さ360 px、JSON/PNG書出し、旧F5設定・TW設定・不正入力の原子的拒否、偽承認情報の無効化を確認。レポートに検査したHTMLのSHAを記録。C旧48 mmの負例も明示。

統合検査はローカルdocs、別origin `ZUDO_CASE_PREVIEW_ORIGIN` のiframeと表示元ラベル、6文書、390/1200 px、Worker準備ディレクトリーからの全26成果物HTTP応答のSHA照合、preview indexと直開きを含む。本番URL形は既存 built-preview-links チェックで検査。デプロイしていないため本番HTTPの新成果物確認は未実施。

再実行: `tests/browser/package.json` の固定 Playwright をインストールして Chromium を用意する。`node engineering/two-way/tw-01/tests/browser.cjs --backend software --out /tmp/tw-software` と `--backend webgl --out /tmp/tw-webgl` を別々に実行する。非標準browserは `TW_CHROMIUM`、Playwrightは `TW_PLAYWRIGHT_MODULE` で指定可能。統合検査は localhost:4173 の標準dev、4174 のpreview-origin上書きdev、127.0.0.1:8787 の dist-preview HTTP serverを起動し `node engineering/two-way/tw-01/tests/integration-browser.cjs` を実行する。

## 既存リポジトリ検査

`repository-checks.json` に全13コマンドの終了0を記録: check:docs / check:tables / check:assets / check:r9 / check:r9-doc-table / check:r9-ledger / check:fitfix / check:fit-test-order / test:r9 / test:setup / test:ledger、およびpreview links・origin isolation、Worker準備・deployed verifier fixture tests。

最終 `final-check-results.json` と `final-check-*.log`: full check、full build（73 pages、53 search entries）、built-preview-links（39 production URLs / 53 docs）、Worker assets準備、Worker実資産・deployment contractテスト9件、TW生成差分チェックは全て終了0。既存の巨大2資産のチャンク分割とpreview originルーティングを保持。

既存R6/R8/R9/fitfixソース、release/gate/quote台帳は変更なし。既存CIのCAD再生成ゲートはそのまま維持した。リモートCIの結果はPRの現在headで確認すること。この記録だけをリモートCIや物理検証の合格とはしない。

## 残る確認

PRで現在headのCIを確認し、変更差分と日本語UIをレビューする。実GPU・他OSブラウザーでの描画、実測寸法、パッチクリアランス、カラー位置決め、ストラップ保持、トランク収納／荷重は #112 の物理開発で別途検証する。72 / 58 mm の前方ギャップは仮定値。ソフトウェアの合格は製造承認ではない。

## 継続レビュー — 2026-10-05

対象head `a5f36ab3245c978ae8638bb3fa05eac1e8e1705d` の run [37290162498](https://github.com/Takazudo/zudo-case/actions/runs/37290162498) は両ジョブ成功。実ログを読んだ。PR合成merge `339025ca9f62769ed532b20c48411236640c4899` は同headとbase `6a13d80d816b0247ab9eee761c29c1fb786b76cc` の組み合わせ。

- check: 142 pass / 0 fail / 0 skip、29成果物一致、73 pages build、39 production preview URLs / 53 docs、Worker 9 pass。
- cad-regenerate: R9検査156 pass / 14 flag / 0 fail（flagは物理承認ではない）、候補パッケージ生成、repeatability 6 pass、tracked outputsの差分なし。
- 後続fitfix: geometry 11 pass、使い捨て出力154 files / 51 mesh readbacks、t1p2 / t1p0および各coupon検査成功、body DXFの3種のdrawing patternが全て一致。

#107–#111の仕様・差分・日本語文書・変換器・ビルド・設定/UIをレビューした。独立した読み取り専用レビューで、連続範囲のF5入力をUIが正しく示さない不具合を確認。厚み1.75 mm / スタンド板7 mmが空のselect、gap72.3 mm / hinge93°がstepで丸めたslider表示になっていた。入力値・geometryは保持されていた。数値入力と非整列値のstep=anyでUIを修正し、整列値では元stepへ戻す。モデル・原本・レール/PCB・寸法JSON・GLBは変更しない。

最終HTMLをChromium 151.0.7922.173でlocal HTTP経由によりsoftwareとWebGL別々に検査し、各59 pass。新しい3チェックは連続厚みのimport表示、fractional slider表示、編集/export一致。レポートは `review-browser-software.json` / `review-browser-webgl.json` に新HTML SHAとtransportを記録。WebGLはANGLE/SwiftShader指定で物理GPU検証ではない。旧56件file://証拠は旧HTMLの記録として保持する。

この環境ではsystem Chromiumのfile://はERR_BLOCKED_BY_ADMINISTRATOR、npm Chromium133は起動後SIGSEGV。新HTMLのfile://再実行は**blocked**。local HTTPの成功をstandalone再確認とは表示しない。portable ZIPの24契約テスト/0 skipと再生成一致、TW142件、生成drift検査は再実行する。CIは修正後headで別途PRに結果を記録し、必須未確認がある間はDraftを維持する。

legacy R6/R8/R9/fitfix、current-spec、release-state、G01–G11、quoteのdiffは空。#112、#102、#105は別件。マージ・デプロイ・製造承認・連絡・発注・課題クローズは未実施。

## マージ判定基準の改訂 — 2026-10-05

ユーザーの追加指示により、今回のソフトウェア統合では `file://` の実行を一律のマージ条件から外す。管理ポリシーでページ読込自体が禁止されることと、HTMLの不具合を区別する。以下を今回の必要条件とする。この節は上記の「file再検査が終わるまでDraft」と以前のマージ禁止記述に優先する。

1. マージ対象のHTMLが検査レポートと同じSHA-256であること。
2. 単体配布の静的確認: JS/CSS/形状/画像をHTML内に持ち、外部script/stylesheet/画像、実行時fetch/XHR、module import、service worker、origin依存の読込がないこと。設定は選択したFileから読み、書出しはBlob/data URLを使う。localStorage拒否はcatchされ、起動・描画の必須条件にならないこと。
3. 同じHTMLのlocal HTTPでsoftware/WebGLを別々に検査し、各59チェック（fractional import表示・編集/exportを含む）、ページ例外なし、外部資産要求なしを確認すること。
4. TW数値/設定/生成差分・既存サイト/CAD回帰を含む現在PR headのCIが成功し、最終実ログを確認すること。変更後は新headで再確認する。

`file://` は許可された環境で行う追加の互換性検査として残す。最新HTMLの直接ファイル実行は依然 **blocked / 未確認**。HTTP合格をfile合格へ言い換えず、管理ポリシーを変更・回避しない。Playwright 1.58.2は再実行時の固定環境として維持し、既存レポートを新規実行とは表示しない。実GPU・他OS・ブラウザー固有の保存/ダウンロード制限も未確認。

### 今回の照合結果

対象実装head `8b8341e49f327c0cdfc4da3a44400b59f25c5594` のHTML Git blob `607c8954d2ac3b694adc541181d86ad86120e515` を取得し、1,379,050 bytes、SHA-256 `19a51c26c1549f4bde4a04d214a1edb62666d14f8675a73b0d19f805d72e6230` と照合した。静的検査で8個のinline classic scriptと1個のdata PNGを確認。外部script/link/iframe/object/base、CSS url/@import、fetch/XHR/WebSocket/dynamic import/service worker/location依存なし。localStorageの読み書きはともにtry/catch内。設定は `File.text()`、JSONはBlob URL、PNGはcanvas data URLを使用する。

`review-browser-software.json` と `review-browser-webgl.json` は同じSHAで各59 pass、errors空、transport `local-http`、Chromium151.0.7922.173。WebGLはANGLE/SwiftShaderで実GPU検証ではない。今回、既存レポートの照合と静的検査を実施した。新しいbrowser runや最新HTMLのfile screenshotsは作成していない。旧56件file記録と旧画像の対象版は変えない。実装の新たな具体的不具合は見つからず、HTML・モデル・設定・geometry・生成物を変更しない。

実装headのCI run37307366481は両ジョブsuccess、実ログ確認済み。今回の文書/CI変更は別の新headとして再検査し、最終結果・merge SHA・post-merge結果はPR #113に記録する。

### マージとデプロイの分離

既存deploy workflowはmain pushで自動公開するため、pushのhead commit messageに `[skip deploy]` がある場合だけdeploy jobをskipする条件を追加する。今回のmerge messageにこの印を付ける。通常pushと手動deployの動作は維持する。`check.yml` はmain pushでも既存のcheck/CAD両ジョブを実行し、マージ後を検査する。CIをskipする印は使用しない。

#112現物開発、#102 R9現物、#105基盤移行は別件。F5とlegacy台帳は不変。マージのみ許可され、デプロイ・製造承認・連絡・発注・課題クローズ・resource cleanupは行わない。

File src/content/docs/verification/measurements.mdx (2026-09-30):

---
title: "現物寸法の空欄記録票"
description: "金具、締結材、ノブ、バンド、板材を必要な範囲で記録する。"
sidebar_position: 55
---

この表は**未記入テンプレート**。全金具の精密測定を求めず、長穴の調整範囲と受け面を確かめる。代表３個は書式上の欄数で、統計的受入検査数ではない。

確認済み情報：fixer/padder PCB厚は各1.6mm、M5平頭高さ1.4mmで頭がpadder下へ収まることはユーザー確認済み。金具外形20×20×16mm、実測厚2mm。2.2mmはモデル余裕で実測値ではない。fixerとケース側板のスペーサー8mm、外側座金厚1mmも採用済み。品番記録や既存適合記録があれば参照してよい。

試験日：＿＿＿＿　測定者：＿＿＿＿　器具：＿＿＿＿　ロット：＿＿＿＿　曲げ基準面の写真：＿＿＿＿

| 対象（mm） | 代表1 | 代表2 | 代表3 | 用途 |
|---|---|---|---|---|
| 同じ金具の面A：曲げ基準から穴中心 |  |  |  | 長穴範囲 |
| 同じ金具の面B：曲げ基準から穴中心 |  |  |  | 曲げ線沿いの誤差も見る |
| 金具の反り・直角の外観 |  |  |  | 全品精度の認定ではない |
| パネル接合ねじ頭の直径 |  |  |  | 長穴受け面 |
| 座金の内径・外径・厚さ |  |  |  | 端部の覆いと突出 |

| 蓋と搭載物 | 記録 |
|---|---|
| 最も高いノブ／スイッチのモジュール名 |  |
| パネル面からの最大突出mmとパネル厚mm |  |
| パッチケーブルを抜いて閉じる条件の確認 |  |
| 実物の天板下面までのすきまmm |  |
| バンド品番・２本の幅・有効周長・位置・張力 |  |
| アルミ材質・仕上げ・実測厚mm |  |
| 接着材品番・貼付厚mm・硬化条件 |  |

ロックナット厚は外側配置を変えない限りケース設計寸法の拘束にしない。発注時のねじ掛かり代と突出は別に確認する。実ノブが未定なら仮領域を維持し、蓋高さを固定した一式注文の前に測る。

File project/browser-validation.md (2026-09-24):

# ローカルサイトのビルド・ブラウザー検証

この記録は文書サイトの表示と操作を扱う。ケースの嵌合、強度、落下、疲労、運搬を検証するものではない。

## 環境と再現手順

| 項目 | 記録 |
|---|---|
| 確認日 | 2026-09-24 |
| Node.js | v24.13.1 |
| pnpm | 10.30.3 |
| 公式 scaffolder | create-zudo-doc 5.27.0 |
| 依存導入 | pnpm install --frozen-lockfile 完了 |
| 静的文書検査 | Pass: 41 MDX、8カテゴリ、122内部リンク。 |
| 資産検査 | Pass: 241ファイル、223,675,056 bytes、SHA-256一致。 |
| setup単体テスト | Pass: 7/7。 |
| ビルド | 2026-09-24の最終・guarded pnpm buildが成功（verdict=PASS、13.64秒）。44ページ、検索index 41項目、broken-link warningなし。47公開資産。 |
| 起動 | pnpm dev が表示するローカルURL |
| ブラウザーと版 | Chrome 146.0.7680.153 |
| Desktop viewport | 1440 × 900; screenshots inspected: overview/start, R8 embedded preview, R6 standalone preview |
| Narrow viewport | 390 × 844; all 41 routes passed with H1 and zero horizontal overflow; overview/start, R8 docs, sidebar, and search screenshots inspected. |
| スクリーンショット・記録 | 下記basenameの画像は一時ローカル保存で、リポジトリには含めない。絶対パスは記録しない。 |

チェックアウト後の再現コマンド:

    pnpm install --frozen-lockfile
    pnpm check:docs
    pnpm check:assets
    pnpm test:setup
    pnpm build
    pnpm dev

ブラウザー確認は実際の画面を操作して行う。重いブラウザー実行にはリポジトリの作業指示にあるheavy guardを使う。HTTP取得だけの成功はUI確認として数えない。

スクリーンショット（temporary local evidence; not bundled）: zudo-case-start.png, zudo-case-r8.png, zudo-case-r6.png, zudo-case-mobile.png, zudo-case-mobile-menu-settled.png, zudo-case-mobile-search.png, zudo-case-mobile-r8.png, zudo-case-image-open.png, zudo-case-r8-standalone.png. The large R6 source preview also remains local.

## 8カテゴリの一覧ルート

| ルート | カテゴリ | Desktop | Narrow |
|---|---|---|---|
| /docs/decisions/ | decisions | 200 + H1 | 200 + H1 |
| /docs/design/ | design | 200 + H1 | 200 + H1 |
| /docs/handoff/ | handoff | 200 + H1 | 200 + H1 |
| /docs/manufacturing/ | manufacturing | 200 + H1 | 200 + H1 |
| /docs/models/ | models | 200 + H1 | 200 + H1 |
| /docs/overview/ | overview | 200 + H1 | 200 + H1 |
| /docs/resources/ | resources | 200 + H1 | 200 + H1 |
| /docs/verification/ | verification | 200 + H1 | 200 + H1 |

## 41文書ルート

以下の41ルートをdesktop 1440×900とnarrow 390×844で個別に開き、HTTP 200とH1を確認した。narrowでは全ルートで横方向のはみ出しがないことも確認した。この巡回は、各ページの本文・サイドバー・全リンクを個別に読み込んだという意味ではない。そうした操作は下の共通確認に記録する。

| # | ルート | 文書 | Desktop | Narrow |
|---:|---|---|---|---|
| 1 | /docs/decisions/decisions | 採用・不採用の判断 | 200 + H1 | 200 + H1; zero overflow |
| 2 | /docs/decisions/history | R1〜R8の変更履歴 | 200 + H1 | 200 + H1; zero overflow |
| 3 | /docs/decisions/ | 判断履歴 | 200 + H1 | 200 + H1; zero overflow |
| 4 | /docs/design/brackets-slots | ブラケットと公差吸収用の長穴 | 200 + H1 | 200 + H1; zero overflow |
| 5 | /docs/design/construction | 平板５枚と役割分担 | 200 + H1 | 200 + H1; zero overflow |
| 6 | /docs/design/fasteners-feet | 締結材・底面・接地 | 200 + H1 | 200 + H1; zero overflow |
| 7 | /docs/design/guards | 薄型PA12ガード | 200 + H1 | 200 + H1; zero overflow |
| 8 | /docs/design/ | 共通設計 | 200 + H1 | 200 + H1; zero overflow |
| 9 | /docs/design/lid-bands | 10BOX式の載せ蓋と外周バンド | 200 + H1 | 200 + H1; zero overflow |
| 10 | /docs/design/rail-stack | 実レール・PCB・8mmスペーサー | 200 + H1 | 200 + H1; zero overflow |
| 11 | /docs/handoff/ | ローカルへの引継ぎ | 200 + H1 | 200 + H1; zero overflow |
| 12 | /docs/handoff/maintenance | 文書・表・資産の更新 | 200 + H1 | 200 + H1; zero overflow |
| 13 | /docs/handoff/setup | ローカルでzudo-docを起動する | 200 + H1 | 200 + H1; zero overflow |
| 14 | /docs/handoff/tasks | 次に行う作業 | 200 + H1 | 200 + H1; zero overflow |
| 15 | /docs/manufacturing/aluminum-order | アルミ板の見積・発注条件 | 200 + H1 | 200 + H1; zero overflow |
| 16 | /docs/manufacturing/bands-suppliers | 調達先と運搬バンドの候補 | 200 + H1 | 200 + H1; zero overflow |
| 17 | /docs/manufacturing/bom | ケース側BOM | 200 + H1 | 200 + H1; zero overflow |
| 18 | /docs/manufacturing/costs | 見積・概算・未取得費用 | 200 + H1 | 200 + H1; zero overflow |
| 19 | /docs/manufacturing/ | 製作・見積 | 200 + H1 | 200 + H1; zero overflow |
| 20 | /docs/manufacturing/print-order | JLC3DP用STLの投入と数量 | 200 + H1 | 200 + H1; zero overflow |
| 21 | /docs/models/3u60 | 3U・60HP | 200 + H1 | 200 + H1; zero overflow |
| 22 | /docs/models/7u40 | 3U＋3U＋1U・40HP | 200 + H1 | 200 + H1; zero overflow |
| 23 | /docs/models/7u60 | 3U＋3U＋1U・60HP | 200 + H1 | 200 + H1; zero overflow |
| 24 | /docs/models/comparison | ３機種の比較 | 200 + H1 | 200 + H1; zero overflow |
| 25 | /docs/models/ | ３機種の仕様 | 200 + H1 | 200 + H1; zero overflow |
| 26 | /docs/overview/glossary | 用語と座標 | 200 + H1 | 200 + H1; zero overflow |
| 27 | /docs/overview/ | はじめに | 200 + H1 | 200 + H1; zero overflow |
| 28 | /docs/overview/scope | 目的・範囲・根拠の扱い | 200 + H1 | 200 + H1; zero overflow |
| 29 | /docs/overview/start | 現在地と最初に読むページ | 200 + H1 | 200 + H1; zero overflow |
| 30 | /docs/overview/status | 採用仕様とデータ状態 | 200 + H1 | 200 + H1; zero overflow |
| 31 | /docs/resources/body-preview | R6・本体とレールのプレビュー | 200 + H1 | 200 + H1; zero overflow |
| 32 | /docs/resources/current-preview | R8・載せ蓋＋外周バンド | 200 + H1 | 200 + H1; zero overflow |
| 33 | /docs/resources/engineering | CADの再生成とソースデータ | 200 + H1 | 200 + H1; zero overflow |
| 34 | /docs/resources/files | 版別ファイルとダウンロード | 200 + H1 | 200 + H1; zero overflow |
| 35 | /docs/resources/ | データとプレビュー | 200 + H1 | 200 + H1; zero overflow |
| 36 | /docs/resources/sources | 資料台帳と出典 | 200 + H1 | 200 + H1; zero overflow |
| 37 | /docs/verification/assemble-test | 組立・蓋・持ち運びの確認 | 200 + H1 | 200 + H1; zero overflow |
| 38 | /docs/verification/before-order | 発注前ゲート | 200 + H1 | 200 + H1; zero overflow |
| 39 | /docs/verification/fit-test | 小さい試験片から確認する | 200 + H1 | 200 + H1; zero overflow |
| 40 | /docs/verification/ | 現物確認・承認 | 200 + H1 | 200 + H1; zero overflow |
| 41 | /docs/verification/release | 検証記録と製作承認 | 200 + H1 | 200 + H1; zero overflow |

## 共通操作と資産

| 確認項目 | Desktop | Narrow | 実際の操作・結果 |
|---|---|---|---|
| 入口: /docs/overview/start、初期ページへの誘導 | Pass: 200 + H1 | Pass: 200 + H1; screenshot inspected | |
| 8カテゴリ一覧とサイドバー移動 | Pass: category listing → 7U40 | Pass: open sidebar → メインメニューに戻る → 機種 → ３機種の仕様 | Narrow sidebar settled at 256px; readable screenshot |
| 文書内リンクを実際に開く | Pass: 93 unique local targets returned status below 400 by HEAD; selected real clicks | Pass: sidebar navigation above | 7U40 reference ZIP was downloaded and checked separately |
| 日本語の文字・折返し・見出し | Pass: inspected desktop screenshots | Pass: inspected overview/start, R8 docs, and sidebar screenshots | Route sweep checked H1 on all 41 pages; it did not manually inspect all page prose |
| 日本語検索: 検索語、候補、遷移先 | Pass: 「載せ蓋」 yielded 12 results | Pass: 「載せ蓋」 yielded 12 results; R8 result opened with H1 | |
| light/dark切替と表示 | Pass: dark→light; data-theme and background changed | Pass: dark→light | |
| 画像の拡大、閉じる操作 | Pass: overlay opened with 2 images; Escape closed it to 1 | Pass: overlay opened with 2 images; Escape closed after transition to 1 | |
| R8プレビューの表示と実際の操作 | Pass: embed loaded; model 7u40→3u60 and travel preset worked; standalone render/control screenshot inspected | Pass: iframe present without overflow; model 7u60 and open preset selected | |
| R6プレビューのリンク先起動と操作 | Pass: standalone opened; model, guard variant, exploded controls worked | Pass: linked standalone opened; 3u60 model selected | Current linked presentation preserved |
| 参照ダウンロード | Pass: browser click downloaded 7u40-r6-aluminum-NOT-RELEASED.zip (263,502 bytes) | Pass: same ZIP downloaded, 263,502 bytes | All 9 current ZIP URLs separately returned nonempty bytes matching their source assets |
| Console errors | Pass: none in stable-page capture | Pass: no console/page errors in narrow route sweep | |
| Failed network requests | Pass: no HTTP ≥400 in stable-page capture | Pass: no HTTP ≥400 in narrow route sweep | Earlier rapid-navigation run aborted dev reloads and an image/download after successful display/download; stable captures clean |
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

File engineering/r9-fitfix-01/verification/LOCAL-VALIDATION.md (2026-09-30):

# R9-FITFIX-01 ローカル統合検証

2026-09-30。出発コミット `7f04c5bda0672ecf2cded79b6e1b48ad141e64b5`。受領セットのソースを独立候補へ追加し、保存R6入力のGit blob一致を確認した。

## CAD

- `uv run --locked --project engineering/r9-prototype-01 python engineering/r9-fitfix-01/build.py` をheavy-guard経由で実行。Python3.12.12 / CadQuery2.7.0 / ezdxf1.4.4 / numpy2.5.3。実行記録は `build.txt`、実環境は `../out/environment.json`。environmentのlockfile_execution_verifiedは生成器が自動判定しないnullであり、上記コマンドの実行が固定環境の根拠。
- 1.2/1.0mm両案、51種類のSTLとSTEP再読込、10パラメータ条件、C1/C2/C4/C5の検査が通過。詳細は `../out/validation.json`。
- 回帰11件すべて通過（`regression.txt`）。旧下辺形状が侵入する負の対照も含む。
- 旧R9の底・前後・左右のDXF３パターンは幾何エンティティが一致。ファイルのバイト一致とは別。双方のSHA-256付き記録は `body-patterns.json`。
- ガード16個の体積は基本39.235cm³、比較31.938cm³。蓋枠4個は84.378cm³ / 83.873cm³。価格未取得。

## 統合

`node scripts/sync-fitfix.mjs` で125候補・163資産を登録。元R9の141候補と217出力は保持し、旧版の台帳検査も通過。製造承認、G01〜G11、見積台帳は変更していない。

公開コピーは同じ出力のバイトを使う。`--check` は入力コード・uv.lock・ベンダーJS、CAD/ZIP/HTML、DXF比較証拠、公開コピー、現行指定、仕様台帳の差分を検出する。変更したバイト・旧版への現行指定の差戻しを拒否する回帰テストを追加した。

- 文書46件、内部リンク180件、表の再生成・台帳チェック通過。
- 628資産のサイズ・SHA-256照合通過。候補の各ファイルは25MiB以下、Git LFS不使用。
- TypeScript/コレクション検査、65ページのサイトビルド通過。
- 既存Nodeテスト一式147件通過（0失敗）。配信用資産の準備、ビルド内の本番プレビューURL、画像リンクも検査。
- ローカルChromeのWebGLで1440px / 390px、1.2/1.0mm、蓋開閉・バンド表示、C1/C2/C4/C5切替と文書内iframeを確認。横はみ出し、ページ/consoleエラーなし。`browser.json` と `preview-1440.png` / `preview-390.png` を参照。
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

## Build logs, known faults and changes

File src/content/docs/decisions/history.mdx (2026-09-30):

---
title: "R1〜R9の変更履歴"
description: "名称が似たファイルの取り違えを防ぐための経緯。"
sidebar_position: 20
---

R9-PROTOTYPE-01（7U40のみ）はR6の５枚本体とR8の真上へ外す蓋を一つの未承認CAD候補へ統合した。金具接合36穴は曲げ線直交の5.5×7.5mm長穴、レール固定10穴は丸穴。ガードはスリップフィット＋接着層、蓋は本体ロックなし。C1/C2/C3小片と[未送信RFQ](../manufacturing/r9-rfq-draft.mdx)を用意した。受け面26穴の旗、現物嵌合、バンド荷重、実ノブなどが残り、量産承認ではない。

## 履歴

| 段階 | 内容 | 現在の扱い |
|---|---|---|
| 初期材料比較 | 鉄、ボンデ、アルミ、既製エッジ材、PA12を比較 | 背景資料。現在は黒アルミ＋専用PA12 |
| R1 | レール直付け、上面枠で余白を覆ったケース案 | 元構造と異なるため不採用 |
| R2 | 独立フレーム＋5mmスペーサー、前後余白を開放 | 以後実寸と離隔を変更 |
| R2ガード | 厚3mm・幅18mm。約208.914cm³ | 大きい体積で高価 |
| R3 | 1.2/1.0mm・幅5mmへ。長辺分割 | 1.2mm見積画面2,264円が実価格根拠 |
| R4 | 実レールとPCB1.6mmを積層へ反映。幅324.4mm | 5mmスペーサー時代の寸法 |
| 取付比較 | 頭1.4mm、金具2mm/余裕2.2mm、5mmで下げる案と8mm案 | ユーザーは8mmを選択 |
| R6 | 8mm離隔、前後約8mm、3U60/7U40/7U60 | 現在の本体CADの起点 |
| R7 | 30mm高の天板＋PA12枠、前後４本M3の補助固定 | 開閉の手間から不採用 |
| ロック比較 | 奥フック＋前90°回転/スライド、約2mm移動して外す | 複雑さ・破損懸念から不採用 |
| R8 | 10BOX式の段差、真上へ外す載せ蓋、運搬バンド２本 | 旧コンセプト表示。R9で7U40の候補CADへ展開 |
| R9-PROTOTYPE-01 | 7U40の長穴・接着層付きガード・ロックなし蓋・C1/C2/C3小片 | 製作候補・未承認。現物と見積は未確認 |

## 過去値で起きやすい混同

**頭1mmは旧仮定**で、後の実測により1.4mmへ更新。**幅324.4mmは5mm離隔の60HP**で、8mm採用後は330.4mm。**3U奥行171mmは旧案**で、余白を詰めた後は154mm。

**1.6mmのfixer厚をスペーサー空間へ再加算しない。** スペーサーはfixer外面〜ケース内面の離隔。幅の総積層と、隙間に入る頭・金具の比較は基準面が異なる。

**R7蓋のPA12体積と価格をR8へ流用しない。** ロック・ナット受け・圧縮部品が変わり、R8は表示形状だけを作り直している。

## 記録されていない版名

この整理では、過去に提示されていないR5の正式リリースを新たに作っていない。取付比較を独立した検討段階として記録する。文書のD1版は整理セットの版であり、ケース設計をR9へ進めた意味ではない。

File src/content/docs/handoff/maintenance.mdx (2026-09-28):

---
title: "文書・表・資産の更新"
description: "MDXの編集と、参照表の同期を分離する。"
sidebar_position: 30
---

## 文書を書くルール

各カテゴリに`index.mdx`を置き、すべてのページへ`title`・`description`・`sidebar_position`を指定する。本文は`##`から始める。文書間リンクは拡張子付きの相対`.mdx`リンクにする。

カテゴリ一覧はzudo-docの`CategoryNav`。特別な描画フレームワークを追加せず、MDXと標準の注記・表を中心にした。

## 数字の更新

機種別ページ、比較表、BOMは`project/current-spec.json`から生成する。

```sh
node scripts/sync-reference-tables.mjs
node scripts/check-docs.mjs
```

台帳の数値はR6/R8の出力から読み取った値。CAD変更後に出力と照合して台帳を更新する。図面を変えずに台帳だけ変えて「製作済み」としない。生成対象ファイルの先頭コメントにも編集元を記載する。

## リンク・資産を確認する

```sh
node scripts/verify-assets.mjs
node scripts/check-docs.mjs
```

ハッシュ検査は同梱元が変更されていないかを調べる。実際の設計更新でファイルが変わった場合は、旧版を残し、新版の情報を`project/artifact-manifest.json`と`project/release-state.json`へ追加する。無条件に期待ハッシュを上書きして検査を通さない。

## 過去版の見せ方

現行プレビューのページから、ロック付きの旧版を「最新」としてリンクしない。アーカイブを削除せずに区別する。価格も、対象版と条件を変えずに履歴へ残す。

このサイトの文書更新日と、CADの改訂日と、業者見積日と、実測日は別。日付が分からない過去発言へ推測の日付を付けない。

公式の根拠：[Writing Docs](https://zudo-doc.takazudomodular.com/docs/getting-started/writing-docs/)、[Sidebar](https://zudo-doc.takazudomodular.com/docs/guides/sidebar/)。

## 見積・製作データの状態を進める

現在価格の欄（`current_total_jpy`・`current_lid_price_jpy`・`current_band_price_jpy`）は未見積・採用前なら`null`のままにする。対応する`current_*_scope`も`null`または省略とする。相見積を複数保存しても、採用するまで現在額を埋める必要はない。`0`は未確認の代用にしない。

`project/quote-records.json`へ現在版の見積を追加するときは、台帳全体で一意の空でない`id`、`kind`（`supplier_quote`または`user_quote_screenshot`）、`applies_to_current_release: true`、`component`（`total`・`lid`・`band`）、`model`または`models`の一方だけ、`revision`、正の整数の`quantity`、`price_basis`、`currency`、空でない`tax_status`、真偽値の`shipping_included`、リポジトリ内に実在する`source`を記録する。`price_basis`は`total_jpy`が１台あたりなら`per_unit`、対象数量分の合計なら`lot_total`。`rows[].row_jpy`の合計を`total_jpy`と一致させる。過去の助手による概算は履歴のまま保持し、現行価格の根拠にはしない。

現在額を採用するときは、対応する`current_*_scope`に機種・版・`quantity`・`price_basis`・`tax_status`・`shipping_included`と、採用した見積IDだけの`quote_ids`（重複のない空でない配列）を記す。選択した見積は同じ`component`で、機種の集合とすべての条件が範囲に一致する必要がある。その`total_jpy`の合計だけを現在額へ転記する。未選択の相見積は加算しない。数量、単価／ロット総額、税、送料条件の換算は扱わない。異なる条件を比較するときは別の見積として保存し、条件が一致するものを選ぶ。

複数見積を合算する場合は、必要な部品・数量を重複なくカバーする説明を空でない`coverage_note`に記す。選択見積間で同じ`rows[].part`ラベルがあると重複計上として拒否する。ただし、ラベルが違う部品や費用の意味上の重複まで検査では証明できないため、説明と根拠を人が確認する。部品別価格を全体価格に混ぜない。

新しい製作候補は`project/release-state.json`の`candidate_files`にリポジトリ相対`path`とファイルの`sha256`を記録する。従来の`path`・`sha256`だけの項目も有効。候補を版付きで識別するときは、台帳内で一意な空でない`id`と、`component`、`model`または`models`の一方、`revision`を記録する。`model`/`models`は`current-spec.json`の機種キーを使う。`current_lid_manufacturing`は`null`、または`model`/`models`の一方、`revision`、`candidate_ids`（空でなく重複しない候補ID一覧）を持つオブジェクトとする。参照先すべての`component`は`lid`、機種集合と版は現行指定に一致させる。アルミ板とPA12フレームなど複数ファイルで蓋候補を構成するときは、それぞれのIDを一覧にする。参照先のファイル存在とSHA-256も検査する。候補の登録や現行指定だけでは製造承認にならず、`production_approved`、機種別`manufacturing_release`、`release_gate`、G01〜G11を進めない。`engineering/release/`への配置は承認後に限り、`published_release_files`に同じパスとハッシュを記録する。

承認には`approval_record`の承認者・日付・承認ファイル一覧（各パスとSHA-256）・`model_revisions`（機種別の製作版）、G01〜G11すべての`closed`状態、`result.summary`、実在する根拠ファイルの`result.evidence`一覧、`current-spec.json`の`release_gate`および機種別`manufacturing_release`との一致が必要。R8がプレビューだけの間、`latest_preview_is_manufacturing_data`は`false`とする。静的チェックは台帳・ファイル・ハッシュの整合を見るもので、加工適合、強度、現物試験、製造承認そのものを代行しない。

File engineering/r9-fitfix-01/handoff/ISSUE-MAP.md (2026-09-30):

# #99–#101 と今回の修正の対応

基準: `7f04c5bda0672ecf2cded79b6e1b48ad141e64b5`。
コード候補: `engineering/r9-fitfix-01/`。GitHubのIssueは閉じていません。

| Issue | 実装箇所 | 今回の検査 | ローカルの完了条件 |
|---|---|---|---|
| #99 下辺・上端コーナーの金属侵入 | `fitfix/geometry.py`: `guard_section`, `guard_perimeter`, `guard_parts` | 旧断面105mm³の負の対照、新断面、全16個×5枚、C4/C5 | 固定環境で再生成、実R9本体との図面/配置照合、全体CI |
| #100 すきまによる薄肉化 | 同ファイル: `Guard`, 断面とリング | BREP切断プローブで主要平坦壁の1.2/1.0mmを測定。fit/adhesive/壁厚変更10条件 | パラメータと実肉厚の契約確認、加工先/試験片での造形・保持確認は別ゲート |
| #101 上端Zと蓋座面の不一致 | 同ファイル: `interface`, `lid_parts` | 分割ガード実面に対する接触面積、Z隙間0、19位置での着脱 | 固定環境の公称検査を再実行、docs/台帳/previewを同じ座面に統合 |

`fitfix/coupons.py`は同じ断面・全体部品を使います。C4/C5は新しい床＋壁、２壁角の局部です。
`tests/test_geometry.py`は回帰テスト、`out/validation.json`は今回の全生成に伴う検査結果です。

## 意図してしていないこと

R9-PROTOTYPE-01を同名のまま書換え、公開資産の期待ハッシュだけを上書き、実測値・見積・G結果を作成、製造承認、業者への送信や発注は行っていません。

コードとしてのIssueの解消判断と、現物ゲートの完了判断は別です。7U40の成立を、そのまま他２機種の蓋たわみ・運搬試験の完了へ広げないでください。

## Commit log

2026-09-24 Initialize ZUDO CASE documentation and preserved design handoff
    [1u-padder.kicad_pcb, 3u-padder.kicad_pcb, 3u60_r6_aluminum_bottom_qty1_mm.dxf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]
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2026-09-27 Validate quote and release ledger transitions with evidence
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2026-09-29 Implement R9 7U40 body geometry
    [7u40-r9-al-bottom-qty1-mm.dxf, 7u40-r9-al-bottom-qty1-mm.step, 7u40-r9-al-bottom-qty1-mm.stl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]
2026-09-29 Implement R9 7U40 lift-off lid prototype
    [7u40-r9-lid-plate-qty1-mm.dxf, 7u40-r9-lid-plate-qty1-mm.step, 7u40-r9-lid-plate-qty1-mm.stl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]
2026-09-29 Add provisional R9 bracket slot geometry and checks
    [7u40-r9-al-bottom-qty1-mm.dxf, 7u40-r9-al-bottom-qty1-mm.step, 7u40-r9-al-bottom-qty1-mm.stl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]
2026-09-29 Add R9 7u40 prototype guard sections and exports
    [7u40-r9-pa12-guard-t1p0-lower-depth-a-qty2-mm.step, 7u40-r9-pa12-guard-t1p0-lower-depth-a-qty2-mm.stl, 7u40-r9-pa12-guard-t1p0-lower-depth-b-qty2-mm.step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]
2026-09-29 Add R9 7u40 assembly integration checkpoint
    [7u40-r9-pa12-lid-frame-bl-qty1-mm.step, 7u40-r9-pa12-lid-frame-bl-qty1-mm.stl, 7u40-r9-pa12-lid-frame-br-qty1-mm.step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]
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2026-09-29 Add R9 C1 and C3 coupon exports
    [7u40-r9-cpn-c1-01-qty1-mm.step, 7u40-r9-cpn-c1-01-qty1-mm.stl, 7u40-r9-cpn-c1-02-qty1-mm.step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]
2026-09-29 Add R9 C2 lid stack coupons
    [7u40-r9-cpn-c2-01-body-wall-qty1-mm.dxf, 7u40-r9-cpn-c2-01-body-wall-qty1-mm.step, 7u40-r9-cpn-c2-01-body-wall-qty1-mm.stl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]
2026-09-29 Package R9 7U40 quote candidates
    [bom.csv]
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2026-09-29 Refresh R9 coupon outputs from pinned CI toolchain
    [7u40-r9-cpn-c1-01-qty1-mm.step, 7u40-r9-cpn-c1-01-qty1-mm.stl, 7u40-r9-cpn-c1-02-qty1-mm.step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]
2026-09-30 Add R9 fit-fix CAD candidate and local verification
    [7u40-r9f-body-bottom-qty1-mm.dxf, 7u40-r9f-body-bottom-qty1-mm.step, 7u40-r9f-body-bottom-qty1-mm.stl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]
2026-09-30 Integrate fit-fix documents, ledgers and test-order quote package
2026-10-04 feat: add home-printable 8mm frame spacer
    [frame-spacer-h8-od10-id5p5-mm.stl, spacer.scad]
2026-10-04 fix: synchronize R9 artifact ledger after package update
2026-10-05 feat(two-way): implement accepted F5 family and verified TW-01 workbench
    Implement #107 through #111 under #106 with immutable F5 source, canonical frame conversion, safe versioned configurations, Japanese docs, offline preview and reproducible downloads.
    Retain legacy R9 state and physical gates. Local tests and backend-specific browser evidence included; no manufacturing approval.
    [DIMENSIONS.csv, FRAME-PART-COUNTS.csv, dimensions-TW-01.csv]
2026-10-06 Add whole-case map for ordered R9 fit coupons (#115)
    Link all 13 ordered designs to their full-case interfaces using existing geometry, with responsive inspection views and source provenance.
    Closes #114.
2026-10-06 fix: add traceable anodizing hanging holes to 13 aluminum coupons
    [7u40-r9a-c1-metal-edge-qty1-mm.dxf, 7u40-r9a-c1-metal-edge-qty1-mm.step, 7u40-r9a-c1-metal-edge-qty1-mm.stl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]
2026-10-15 fix: match current case rail PCB preview to photographed face finishes
2026-10-20 feat(r9-lid-m5-01): M5 screw + nylon lock nut for the 7U40 lid plate/frame (#123)
    Independent candidate R9-LID-M5-01 from R9-FITFIX-01. Only the plate-to-PA12
    frame fastener changes: through hole 5.5, hex pocket AF 8.4, effective depth
    5.5, roof 1.5, boss depth 7.0, axis 5.5 from the plate edge. Seat, locator,
    lift-off, bands, body plates and guards are unchanged and checked as such.
    - one M5 definition drives 4 frames x (t1.2/t1.0), plates, C2-M5-01/02/03 and
    the N1 AF ladder (8.3/8.4/8.5)
    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
2026-10-20 fix(r9-lid-m5-01): refresh R9 document-registry hash after current-spec update
    The R9 package manifest records the current-spec.json hash; regenerate it with
    r9.package and resync the R9 ledger. No CAD output changes.
    Claude-Session: https://claude.ai/code/session_01HRFn5hhiPcK9LUgf9bXuyz
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2026-10-25 fix: distinguish cap coverage from fixed bracket travel clearance
2026-10-25 feat: maintain P3 printed 5mm 7U40 variant [skip deploy]
    Add locked full CAD regeneration, accepted geometry comparisons, source-preserved 7U rails, print packages, standalone preview, Japanese docs and scoped CI. Keep R10 cart and selected manufacturing files unchanged.
2026-10-25 fix: pin P3 browser CI to supported Ubuntu [skip deploy]
2026-10-26 feat: 7U40 P4 Uniform四壁通気孔 (#127) [skip deploy]
    P3を保存した独立P4家庭印刷ケース。四壁82開口と専用38締結穴を分離し、完全なCAD・パッケージ・プレビュー・日本語文書を統合。
    P3/R10保存、2回再生成、Canvas/WebGL、文書・既存CADを検証。PR #127の全current-head CI成功。デプロイ・発注・製造承認は行わない。
2026-10-27 feat: add P4 H2D unsliced 3MF print projects [skip deploy]
2026-11-02 feat: generate P5 J3 tab joints from maintained CAD source [skip deploy]
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2026-11-06 build: upgrade to zudo-doc 9.1.2 and zfb 5.2.0
    Freeze the latest stable tuple at implementation start: zudo-doc and
    history-server 9.1.2, zfb/zfb-runtime/zfb-md-wasm 5.2.0 (the exact pins
    of the official create-zudo-doc 9.1.2 scaffold), Node >=24, pnpm 10.30.3.
    Set themePack "default" to keep the Classic look after the 9.0 default
    change. Regenerated 6.2.0 and 9.1.2 scaffolds match every copied file
    byte-for-byte, so no route/CSS/template replacement is applied. Update
    setup.mjs defaults, setup tests, current-version docs, ZUDO_DEPS_PINS.md,
    and add a maintenance receipt; the 6.2.0 receipt stays unchanged.
    Claude-Session: https://clau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
2026-11-06 docs: 文書を６セクションへ再編し、旧URLを互換ページで維持
    - 全体案内・金属ケース・家庭印刷ケース・2WAY 実験設計・共通部品・開発・保守の６セクションへ再編（/files/は維持）
    - overview/startを系列の選択ページ、overview/statusを系列横断の要約に変更
    - 旧URLは project/doc-routes.json から生成する unlisted の互換ページで残し、正式ページへのリンクと旧見出しアンカーを保持
    - 家庭印刷の履歴ハブと明示サイドバー（現行P5／履歴P4／履歴P3）を追加
    - R9を現行とする記述、P4を通気孔なしとする記述、R8/R6を全体の起点とする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
2026-11-06 docs: レビュー指摘を反映（R9工程の見出し、C3試験片の記述、互換リンク検査）
    - 金属ケースの次工程: R9当時の工程案と引継ぎ文を「旧R9系の工程（履歴）」の下の見出しへ移し、旧アンカーはspanで維持
    - 長穴の確認を実組立（7U40はR10一式）とし、C3試験片はR9当時の計画として記載
    - engineering/release/ は空ではなく注意書きのREADMEだけと記載（artifact-manifestのhashを更新）
    - check-built-doc-routes: 互換ページから正式ページへのリンクを本文（main）内で確認
    Claude-Session: https://claude.ai/cod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
2026-11-06 test: 直接CLIのdev分離テストで２プロセスを順に起動する
    zudo-doc 9.x のroutesプラグインは起動ごとに <project root>/.zudo-doc/routes-src を削除・再コピーする。
    同じルートで２つの直接 zfb dev を同時に起動すると、一方が他方のステージ済みルートを
    バンドル中に消すことがあり、CIで1回失敗した。起動を順番にし、分離の検査内容は変えない。
    run-site は実行ごとに別ルートを使うため、pnpm dev/build/check には影響しない。
    Claude-Session: https://claude.ai/code/session_01JXThoMmHyzoBZr4qNYjpGq
2026-11-08 feat: integrate accepted 10BOX-v2 R5 and case documentation [skip deploy]
2026-11-12 scaffold: reconcile create-zudo-doc 10.0.3 and adopt Graphite explicitly
    Three-way comparison of regenerated 9.1.2, the checkout and regenerated
    10.0.3: only pages/docs/[[...slug]].tsx changed upstream (comment only)
    and is taken from 10.0.3. themePack is "graphite" in zfb.config.ts and
    setup.preset.json because zudo-doc 10 aliases "default" to Graphite and
    the generator rejects "default". Pin, setup default CLI version, docs
    and a new reconciliation receipt move to 10.0.3 together.
    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
2026-11-12 feat: add ZUDO CASE illustration, sharing card and metadata
    Adds a decorative monochrome case-frame illustration used as the home
    logo mask, a 1200x630 Graphite sharing card with its generator source
    and reproduction steps, and siteUrl/logo/metaTags in zfb.config.ts.
    noindex stays enabled. A focused test guards the theme, metadata and
    image dimensions.
    Refs #134
    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
2026-11-12 review: clarify siteUrl canonical effect, harden imagery generator
    Document that siteUrl also sets canonical/og:url, complete the image
    reproduction prerequisites, replace the overflow assert with an explicit
    exit, move the filter module's jacks clear of the panel screw, and fix
    the pinned-guide wording.
    Claude-Session: https://claude.ai/code/session_01JXThoND6X7iKobEJHQCi2X
    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
2026-11-12 fix(tenbox-v2): treat the 3MF build-day ModificationDate as benign in R5 verify
    build_flat_projects.py stamps ModificationDate with the UTC build day, and
    verify.py compared the regenerated common-floor model byte-for-byte after
    normalizing only UUIDs, so the clean-rebuild CI job could pass only on
    2026-11-08. Normalize ModificationDate alongside UUIDs, as the R5 README
    already describes. No geometry, settings, 3MF project or print package
    changes. The source ZIP is rebuilt with the same deterministic packer
    (reproduced byte-identically before the edit) and its receipt and the
    verify.py receipt are updated in the manifest.
    Claude-Sessi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
